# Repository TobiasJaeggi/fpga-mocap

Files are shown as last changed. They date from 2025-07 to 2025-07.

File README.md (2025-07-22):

# FPGA-based low-cost motion capture
Infrared-based motion capture.
Image processing is done the [GECKO5Modular](https://github.com/logisim-evolution/GECKO5Education) (formerly GECKO5Education V2.0), an educational FPGA platform.
I created this system as part of masters degree in electrical engineering at Bern University of Applied Sciences (BFH).

> [!NOTE]
> Solving marker correspondence using epipolar geometry is not yet implemented.
> As a result, the Python software is currently only able to track a single marker.

# Blob Detector
Marker detection unit hosting FGPA, microcontroller, IR camera, IR LEDs and PoE module.
<p float="left">
  
  
</p>

# Demo
The system tracking a reflective marker.
demo
[demo video](https://youtu.be/6Va6dF9vp88)

# Mechanical design
[onshape project](https://cad.onshape.com/documents/1d5331a2d4403797078fc34d/w/9683c0b739c4abd1173768d9/e/775ed87ad6031a9883c39a66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)

# Documentation
`doc/Low-Cost_Motion_Capture.pdf`

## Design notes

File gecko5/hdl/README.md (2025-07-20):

# Disclaimer
**This README is out of date!**
It is a leftover of the template this project is based on.
The most complete documentation can be found in the root README.md

Some testbenches are deprecated and no longer work.

[or1ktoolchain]( https://github.com/openrisc/or1k-gcc) is required to build program for softcore

---

# Old README
#### Structure:

The virtual prototype consists of three directories:

- modules: This directory contains the several modules that are contained in the SOC. Add your own modules in this directory. Most modules also contain a ```doc``` directory with documentation.
- programms: This directory contains the "hello world" template that can be used as basis for your own programms.
- systems: This directory contains all the required files for the "top level" of the SOC.

#### Hardware configuration files:

To be able to build the Virtual Prototype hardware, there are several files:

- systems/singleCore/scripts/gecko4_or1420.tcl: This file contains the pin-mapping of the top level to the FPGA-pins. For the add-on board they are already contained as remarks, for the one's of the GECKO4Education you can visit [the wiki page](https://gecko-wiki.ti.bfh.ch/gecko4education_epfl:start).
- systems/singleCore/config/project.device.intel: This file contains the definitions of the FPGA used on the GECKO4Education. Do not modify this file.
- systems/singleCore/config/project.files: This file contains a list with all Verilog files that are required to build the Virtual Prototype. If you add modules, you have also to modify this file such that the modules are found.
- systems/singleCore/config/project.intel: This file contains generic commands for the Intel Quartus Lite tool. Do not modify this file.
- systems/singleCore/config/project.qsf: This file is responsible to include the gecko4_or1420.tcl file. Do not modify this file.
- systems/singleCore/config/project.toplevel: This file contains the name of the top-level module. Normally you should not have to modify this file.

#### Building the hardware:

As the tools are quite "heavy" and to provide a automated flow, a makefile system is used. To build the system:

- Goto the directory systems/singleCore/ (e.g. ```cd systems/singleCore/```).
- Type: ```make intel_bit```
- If no errors occurred you'll find in the directory ```systems/singleCore/sandbox``` the files ```or1420SingleCore.cfg``` and ```or1420SingleCore.rbf```. These files can be used to program your FPGA with the open-source tool ```openocd``` of the oss-cad-suite by executing ```openocd -f or1420SingleCore.cfg``` on the machine to which the GECKO4Education board is connected. Alternatively you can use the intel quartus programmer, for this you require the file ```or1420SingleCore.sof```, which is also available in the directory ```systems/singleCore/sandbox```

#### Building the software:

Also the software is based on a makefile system. To build a program follow following steps (with as example the hello world program):

- Goto the directory ```programs/helloWorld```
- Execute ```make clean mem```
- If no error occurred, you will find in the directory ```programs/helloWorld/build-release/``` the files ```hello.elf```, ```hello.cmem```, and ```hello.mem```. The file that you need to upload to your board is the ```hello.cmem```-file.
- Upload the ```hello.cmem```-file with your favorite terminal program to your virtual prototype.

IMPORTANT: As the or1420 does not contain a hardware-divide unit you have to compile your programm with the compile option ```-msoft-div```!

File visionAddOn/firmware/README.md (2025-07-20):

C++ firmware for the STM32 microcontroller on the Vision Add-On

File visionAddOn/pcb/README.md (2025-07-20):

# `visionAddOn/hardware`
An addon for the [GECKO5Education](https://github.com/logisim-evolution/GECKO5Education) intended for IR based MoCap featuring
- STM32F767 with external RAM, EEPROM and external Watchdog
- Power Over Ethernet
- Connector for [KLT-E4MPF-OV9281 V4.2 NIR Camera](http://modulecamera.com)
- switchable 5V supply for external IR stroble LED
# known issues
## V1.0
### nINT/REFCLK0 does not output a clock
Pin 2 (LED2/nINIT/nPME/nINTSEL) on LAN87 needs a pulldown. Also, remove pulldown on LED1/nINT/nPME/REGOFF.
 
# Attribution
## Project Template
This project is based on the GECKO5 [addonTemplate](https://github.com/logisim-evolution/GECKO5Education/tree/main/kicad/addonTemplate)

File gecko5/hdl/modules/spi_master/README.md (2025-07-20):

# spi-master
[source](https://github.com/nandland/spi-master)

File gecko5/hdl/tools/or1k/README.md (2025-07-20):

# disclaimer
These tools are compiled for `amd64` architecture.
# about
Tools required to run custom code on the or1420 soft core.
ork1toolchain.zip contains the compiler, linker, etc.
convert_or32 is used to convert the toolchains output (.elf) to the format required by the or1420 softcore (.cmem).
# install
## ork1toolchain
1. extract ork1toolchain.zip to /opt/or1k_toolchain:
```
/opt/or1k_toolchain
├── bin
├── include
├── lib
├── libexec
├── or1k-elf
└── share
```
2. add bin folder to the system path
`export PATH="/opt/or1k_toolchain/bin:$PATH"`
(add to `~/.bashrc` or corresponding file of your shell)
## convert_or32
1. Copy convert_or32 to /opt/convert_o32/bin.
```
/opt/convert_or32/
└── bin
    └── convert_or32
```
2. add bin folder to the system path
`export PATH="/opt/convert_or32/bin:$PATH"`
(add to `~/.bashrc` or corresponding file of your shell)

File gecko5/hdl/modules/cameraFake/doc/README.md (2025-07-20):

# Description
Fake of Olimex Ov7670 camera, caplable of displaying a test image.
Outputs a RGB565 8bit parallel video signal. The resolution is 640*480 pixels.
# sources
[clock divier](https://www.fpga4student.com/2017/08/verilog-code-for-clock-divider-on-fpga.html)
[verilator tutorial](https://itsembedded.com/dhd/verilator_1/)
[implementing vga in verilog](https://ktln2.org/2018/01/23/implementing-vga-in-verilog/)

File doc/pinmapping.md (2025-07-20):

# Pin Mapping

| In Use (STM) | STM Pin | visionAddOn<br>QTE<br>Signal Name | QTE-020-01-F-D-A<br>Pin Number | GECKO5 QTE Signal Name | FPGA Pin |
| --- | --- | --- | --- | --- | --- |
| - | - | - | 1 | - | - |
| - | - | NC | 2 | - | - |
| | PD5 | UART_TX_STM_TO_FGPA | 3 | GPIO18 | A5 |
| - | - | PCLK_CAMERA | 4 | GPIO19 | E5 |
| x | PA3 | UART_RX_STM_FROM_FPGA | 5 | GPIO17 | B5 |
| - | - | HREF_CAMERA | 6 | GPIO20 | F2 |
| x | PA6 | PCLK_FPGA | 7 | GPIO16 | C5 |
| - | - | VSYNC_CAMERA | 8 | GPIO21 | E1 |
| x | PA4 | HSYNC_FPGA | 9 | GPIO15 | D5 |
| - | - | D2_CAMERA | 10 | GPIO22 | E2 |
| x | PG9 | VSYNC_FPGA | 11 | GPIO14 | A3 |
| - | - | D3_CAMERA | 12 | GPIO23 | D1 |
| x | PC9 | D3_FPGA | 13 | GPIO13 | A4 |
| - | - | D4_CAMERA | 14 | GPIO24 | D2 |
| x | PC8 | D2_FPGA | 15 | GPIO12 | B3 |
| - | - | D5_CAMERA | 16 | GPIO25 | C1 |
| x | PC7 | D1_FPGA | 17 | GPIO11 | B4 |
| - | - | D6_CAMERA | 18 | GPIO26 | C2 |
| x | PC6 | D0_FPGA | 19 | GPIO10 | C3 |
| - | - | D7_CAMERA | 20 | GPIO27 | B1 |
| x | PE4 | D4_FPGA | 21 | GPIO9 | C4 |
| - | - | D8_CAMERA | 22 | GPIO28 | B2 |
| x | PD3 | D5_FPGA | 23 | GPIO8 | D3 |
| - | - | D9_CAMERA | 24 | GPIO29 | A2 |
| x | PE5 | D6_FPGA | 25 | GPIO7 | F5 |
| - | - | STROBE | 26 | GPIO30 | H3 |
| x | PE6 | D7_FPGA | 27 | GPIO6 | E3 |
| | PB6 | SCL_CAM | 28 | GPIO31 | H4 |
| | PA5 | DEBUG0 | 29 | GPIO5 | E4 |
| | PB7 | SDA_CAM | 30 | GPIO32 | H5 |
| | PB4 | DEBUG1 | 31 | GPIO4 | F3 |
| - | - | PWR_RX | 32 | - | - |
| | PD7 | DEBUG2 | 33 | GPIO3 | F4 |
| - | - | PWR_TX | 34 | - | - |
| | PG10 | DEBUG3 (EXTI new SPI data) | 35 | GPIO2 | G3 |
| - | - | USB_FPGA_D- | 36 | Usb D- | - |
| | PG11 | DEBUG4 | 37 | GPIO1 | G5 |
| - | - | USB_FPGA_D+ | 38 | Usb D+ | - |
| - | - | - | 39 | - | - |
| - | - | GND | 40 | GND | - |

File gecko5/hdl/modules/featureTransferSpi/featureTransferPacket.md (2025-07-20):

## Types
---
`U8` type
unsigned integer 8-bit

---
`BB` type
6 bytes
index range is bit index
```
|-BB--------------------------------------|
|-47:42---|-41:31-|-30:20-|-19:10-|-9:0---|
| padding | xmin  | xmax  | ymin  | ymax  |
```
---
## packet structure
bb: bounding box
index range is byte index
```
|-header-------------------------|-features------------------|
| frame count | number of bb <n> | bb0 | bb1 | ... | bb<n-1> |
|-------------|------------------|-----|-----|-----|---------|
| U8          | U8               | BB  | BB  | ... | BB      |
```

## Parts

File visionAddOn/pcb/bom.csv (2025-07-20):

Reference | Value | Datasheet | Footprint | Qty | DNP | Description | DigiKey-Partnumber | CUBUS
R5 | 0 | ~ | Resistor_SMD:R_0402_1005Metric | 1 |  |  | 311-0.0JRTR-ND | 0 RESC1005X35
R6,R7,R10,R60,R61,R62 | 0 |  | Resistor_SMD:R_0402_1005Metric | 6 | DNP |  | 311-0.0JRTR-ND | 0 RESC1005X35
R11,R57,R58,R59 | 0 |  | Resistor_SMD:R_0402_1005Metric | 4 |  |  | 311-0.0JRTR-ND | 0 RESC1005X35
C31,C33 | 9pF | ~ | Capacitor_SMD:C_0402_1005Metric | 2 |  |  | 490-8232-2-ND
C2 | 18pF | ~ | Capacitor_SMD:C_0402_1005Metric | 1 |  |  | 490-8082-2-ND | 18P CAPC1005X50
C18,C20 | 47pF | ~ | Capacitor_SMD:C_0402_1005Metric | 2 |  |  | 490-5942-2-ND | 47P CAPC1005X50
C59 | 470pF | ~ | Capacitor_SMD:C_0402_1005Metric | 1 |  |  | 490-1300-2-ND | 470P CAPC1005X50
C71,C72 | 22nF | ~ | Capacitor_SMD:C_0603_1608Metric | 2 |  | Unpolarized capacitor | 490-17777-2-ND
C7,C12,C15 | 100nF |  | Capacitor_SMD:C_0402_1005Metric | 3 |  |  | 490-6328-2-ND | 100N CAPC1005X50
C17,C19,C22,C23,C24,C25,C26,C27,C29,C30,C32,C35,C36,C38,C39,C40,C41,C42,C45,C46,C47,C48,C49,C50,C51,C54,C55,C58,C63,C65,C66,C67,C76,C77,C79 | 100nF | ~ | Capacitor_SMD:C_0402_1005Metric | 35 |  |  | 490-6328-2-ND | 100N CAPC1005X50
C70 | 100nF | ~ | Capacitor_SMD:C_0603_1608Metric | 1 | DNP | Unpolarized capacitor | 311-1088-2-ND | 100N CAPC1608X80
C1,C3 | 1uF | ~ | Capacitor_SMD:C_0603_1608Metric | 2 |  |  | 445-4112-2-ND | 1U CAPC1608X80
C6,C8,C9,C11,C13,C14,C16 | 1uF |  | Capacitor_SMD:C_0603_1608Metric | 7 |  |  | 445-4112-2-ND | 1U CAPC1608X80
C34,C37,C52,C53,C56,C57,C62,C75 | 1uF | ~ | Capacitor_SMD:C_0402_1005Metric | 8 |  |  | 490-10024-2-ND | 1U CAPC1005X50
C60 | 1uF | ~ | Capacitor_SMD:C_0402_1005Metric | 1 | DNP |  | 490-10024-2-ND | 1U CAPC1005X50
C43,C44 | 2.2uF | ~ | Capacitor_SMD:C_0402_1005Metric | 2 |  |  | 490-10012-2-ND | 2U2 CAPC1005X50
C4,C5,C10 | 4.7uF |  | Capacitor_SMD:C_0805_2012Metric | 3 |  |  | 1292-0805X475K250CTTR-ND | 4u7 CAPC2012X95
C21 | 10uF | ~ | Capacitor_SMD:C_0603_1608Metric | 1 |  |  | 445-4112-2-ND
C64 | 10uF | ~ | Capacitor_SMD:C_0402_1005Metric | 1 |  |  | 490-GRM155R61A106ME11DTR-ND
R14,R15 | 27 | ~ | Resistor_SMD:R_0402_1005Metric | 2 |  |  | P27.0LTR-ND | 27 RESC1005X35
R31,R32,R34,R35,R36 | 33 | ~ | Resistor_SMD:R_0402_1005Metric | 5 |  |  | 311-33.0LRTR-ND
R30 | 47 | ~ | Resistor_SMD:R_0402_1005Metric | 1 |  |  | RMCF0402JT47R0TR-ND
R47,R48,R49,R50 | 50 | ~ | Resistor_SMD:R_0402_1005Metric | 4 |  |  | 13-RT0402BRE0750RLTR-ND
R16,R17,R43,R44 | 270 | ~ | Resistor_SMD:R_0402_1005Metric | 4 |  |  | 541-4842-2-ND | 270 RESC1005X35
R1,R2,R28,R29 | 1k | ~ | Resistor_SMD:R_0402_1005Metric | 4 |  |  | 311-1.0KJRTR-ND | 1K RESC1005X35
R8,R9 | 1k | ~ | Resistor_SMD:R_0402_1005Metric | 2 |  | Resistor | 311-1.0KJRTR-ND | 1K RESC1005X35
R18,R19,R20,R21,R22,R26,R27,R33,R37,R38,R39,R41,R42,R52,R53,R54,R55 | 10k | ~ | Resistor_SMD:R_0402_1005Metric | 17 |  |  | 311-10KJRTR-ND | 10K RESC1005X35
R23 | 12k | ~ | Resistor_SMD:R_0402_1005Metric | 1 |  |  | 311-12KJRTR-ND | 12K RESC1005X35
R46 | 12.1k | ~ | Resistor_SMD:R_0402_1005Metric | 1 |  |  | 311-12.1KLRTR-ND
R24,R25 | 100k | ~ | Resistor_SMD:R_0402_1005Metric | 2 |  |  | 311-100KLRTR-ND | 100K RESC1005X35
R4 | 150k | ~ | Resistor_SMD:R_0402_1005Metric | 1 |  |  | 311-150KLRTR-ND | 150K RESC1005X35
R3 | 680k | ~ | Resistor_SMD:R_0402_1005Metric | 1 |  |  | 311-680KJRTR-ND | 680K RESC1005X35
R45 | 1M | ~ | Resistor_SMD:R_0402_1005Metric | 1 | DNP |  | 311-1.00MLRTR-ND | 1M RESC1005X35
StrobeEnable1 | 61300211121 | ~ | Connector_PinHeader_2.54mm:PinHeader_1x02_P2.54mm_Vertical | 1 |  | Generic connector, single row, 01x02, script generated (kicad-library-utils/schlib/autogen/connector/) | 732-5315-ND
WATCHDOG_ENABLE1 | 61300211121 | https://www.we-online.com/components/products/datasheet/61300211121.pdf | Connector_PinHeader_2.54mm:PinHeader_1x02_P2.54mm_Vertical | 1 |  | Generic connector, single row, 01x02, script generated (kicad-library-utils/schlib/autogen/connector/) | 732-5315-ND
J3 | 61300311121 | ~ | Connector_PinHeader_2.54mm:PinHeader_1x03_P2.54mm_Vertical | 1 |  | Generic connector, single row, 01x03, script generated (kicad-library-utils/schlib/autogen/connector/) | 732-5316-ND
J1,J7 | 61300411121 | ~ | Connector_PinHeader_2.54mm:PinHeader_1x04_P2.54mm_Vertical | 2 |  | Generic connector, single row, 01x04, script generated (kicad-library-utils/schlib/autogen/connector/) | 732-5317-ND
J5 | 61300511121 | ~ | Connector_PinHeader_2.54mm:PinHeader_1x05_P2.54mm_Vertical | 1 |  | Generic connector, single row, 01x05, script generated (kicad-library-utils/schlib/autogen/connector/) | 732-5318-ND
J4 | 105450-0101 | https://tools.molex.com/pdm_docs/ps/PS-105448-001.pdf | visionAddOn:MOLEX_105450-0101 | 1 |  | USB Shielded I/O Receptacle; Type C; Right Angle; Surface Mount; Gold over Nickel | WM12856TR-ND
D2,D4 | 150060GS75020 | https://www.we-online.com/components/products/datasheet/150060GS75020.pdf | LED_SMD:LED_0603_1608Metric | 2 |  | Light emitting diode | 732-150060GS75020TR-ND
D1,D3 | 150060RS75020 | https://www.we-online.com/components/products/datasheet/150060RS75020.pdf | LED_SMD:LED_0603_1608Metric | 2 |  | Light emitting diode | 732-150060RS75020TR-ND
R51 | 15k/0.1W | ~ | Resistor_SMD:R_0402_1005Metric | 1 |  | Resistor | P15.0KLTR-ND
R40 | 1k5 | ~ | Resistor_SMD:R_0402_1005Metric | 1 |  |  | 311-1.5KJRTR-ND
L5 | 1k @ 100MHz/LRC0402CS2N2GV001T | ~ | Inductor_SMD:L_0402_1005Metric | 1 |  |  | 712-LRC0402CS2N2GV001TTR-ND
C61 | 1nF/2000V/10%/X7R/C1206 | ~ | Capacitor_SMD:C_1206_3216Metric | 1 |  | Unpolarized capacitor | 709-VPDD202W102K1GV001ETR-ND
C69 | 22uF/80V/20%/PCH1J220MCL4GS | https://www.nichicon.co.jp/english/series_items/catalog_pdf/e-pch.pdf | Capacitor_SMD:CP_Elec_6.3x7.7 | 1 |  | Polarized capacitor | PCH1J220MCL4GTR-ND
C68,C73,C74 | 470uF/10V/20%/PCF1A471MCL1GS | https://www.nichicon.co.jp/english/series_items/catalog_pdf/e-pcf.pdf | Capacitor_SMD:CP_Elec_10x10 | 3 |  | Polarized capacitor | 493-2996-2-ND
R12,R13 | 5k1 | ~ | Resistor_SMD:R_0402_1005Metric | 2 |  |  | 311-5.10KLRTR-ND
U2 | AP2281-3WG-7 | ~ | visionAddOn:SOT26_DIO | 1 |  |  | AP2281-3WG-7DITR-ND
U13 | AS4C16M16SA | https://www.alliancememory.com/wp-content/uploads/pdf/dram/256M-AS4C16M16SA-Automotive_v2.0_March%202015.pdf | Package_SO:TSOP-II-54_22.2x10.16mm_P0.8mm | 1 |  | 64M – (16M x 16 bit) Synchronous DRAM (SDRAM), TSOP-II-54 | 1450-1252-ND
U18 | AT24C02D-MAHM-T | https://ww1.microchip.com/downloads/aemDocuments/documents/OTH/ProductDocuments/DataSheets/AT24C01D-AT24C02D-I2C-Compatible-Two-Wire-Serial-EEPROM-1Kbit-2Kbit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 | visionAddOn:AT24C02D-MAHM-T_SON50P200X300X60-9N | 1 |  |  | AT24C02D-MAHM-TTR-ND
BOOT_STM1 | B3U-1000P | ~ | visionAddOn:SW_B3U-1000P_OMR | 1 |  | https://omronfs.omron.com/en_US/ecb/products/pdf/en-b3u.pdf | SW1020TR-ND
BT1 | B3U-1000P | https://omronfs.omron.com/en_US/ecb/products/pdf/en-b3u.pdf | visionAddOn:SW_B3U-1000P_OMR | 1 |  |  | SW1020TR-ND
RESET1 | B3U-1000P | https://omronfs.omron.com/en_US/ecb/products/pdf/en-b3u.pdf | visionAddOn:SW_B3U-1000P_OMR | 1 |  |  | SW1020TR-ND
L6 | BLM18KG601SN1D | ~ | Inductor_SMD:L_0603_1608Metric | 1 |  | Inductor | 490-5258-2-ND
C28 | C1608X5R0J106M080AB | ~ | Capacitor_SMD:C_0603_1608Metric | 1 |  |  | 445-4112-2-ND
xt30SourceSelect1 | D3086-98 | ~ | visionAddOn:HARWIN_D3086-98 | 1 |  | Generic connector, single row, 01x03, script generated (kicad-library-utils/schlib/autogen/connector/) | 952-1864-ND
U8 | DF30FC-24DS-0.4V_82_ | https://www.hirose.com/product/document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 | visionAddOn:DF30FC-24DS_KLT_PIN_MAPPING | 1 |  |  | H3860TR-ND
X1 | ECS-2520MV-240-BL-TR | https://www.ecsxtal.com/store/pdf/ECS-2520MV.pdf | Oscillator:Oscillator_SMD_ECS_2520MV-xxx-xx-4Pin_2.5x2.0mm | 1 |  | HCMOS Crystal Clock Oscillator, 2.5x2.0 mm SMD | 50-ECS-2520MV-240-BL-TR-ND
X2,X3 | ECS-2520MV-240-BL-TR | https://www.ecsxtal.com/store/pdf/ECS-2520MV.pdf | Oscillator:Oscillator_SMD_ECS_2520MV-xxx-xx-4Pin_2.5x2.0mm | 2 |  |  | 50-ECS-2520MV-240-BL-TR-ND
X4 | ECS-2520MV-250-CN-TR | https://www.ecsxtal.com/store/pdf/ECS-2520MV.pdf | Oscillator:Oscillator_SMD_ECS_2520MV-xxx-xx-4Pin_2.5x2.0mm | 1 |  | HCMOS Crystal Clock Oscillator, 2.5x2.0 mm SMD | XC2752TR-ND
U10 | FT231XQ | https://www.ftdichip.com/Support/Documents/DataSheets/ICs/DS_FT231X.pdf | Package_DFN_QFN:QFN-20-1EP_4x4mm_P0.5mm_EP2.5x2.5mm | 1 |  |  | 768-1128-2-ND
J6 | FTSH-105-01-S-DV-K-P-TR | http://infocenter.arm.com/help/topic/com.arm.doc.ddi0314h/DDI0314H_coresight_components_trm.pdf | visionAddOn:SAMTEC_FTSH-105-01-S-DV-TR | 1 |  | Cortex Debug Connector, standard ARM Cortex-M SWD and JTAG interface | SAM13935TR-ND
Q1 | IRLZ44N | http://www.irf.com/product-info/datasheets/data/irlz44n.pdf | Package_TO_SOT_THT:TO-220-3_Vertical | 1 |  | 47A Id, 55V Vds, 22mOhm Rds Single N-Channel HEXFET Power MOSFET, TO-220AB | IRLZ44NPBF-ND
U14 | LAN8742A | http://ww1.microchip.com/downloads/en/DeviceDoc/8742a.pdf | Package_DFN_QFN:VQFN-24-1EP_4x4mm_P0.5mm_EP2.5x2.5mm_ThermalVias | 1 |  | LAN8720 Ethernet PHY with RMII interface, QFN-24 | LAN8742A-CZ-TR-ND
L1 | LQM2HPN2R2MJ0L | ~ | visionAddOn:LQM2HPN2R2MJ0L | 1 |  |  | 490-6700-2-ND
U3 | MIC826TYMT-TR | https://ww1.microchip.com/downloads/en/DeviceDoc/MIC826.pdf | visionAddOn:MIC826TYMT-TR_SON50P160X160X60-7N | 1 |  |  | 576-4375-2-ND
L2,L3,L4 | MLP2012S3R3MT | https://product.tdk.com/en/system/files | Inductor_SMD:L_0805_2012Metric | 3 |  |  | 445-6365-2-ND
MD1 | MYBSP0055AABFT | https://www.murata.com/products/productdata/8807034454046/MYBSP0055AABFT.pdf | visionAddOn:MYBSP0055AABFT_0 | 1 |  |  | 811-MYBSP0055AABFTTR-ND
U1 | NCP1529A | https://www.onsemi.com/pub/Collateral/NCP1529-D.PDF | Package_TO_SOT_SMD:SOT-23-5 | 1 |  |  | NCP1529ASNT1GOSTR-ND
U7 | NTS0104BQ | https://www.nxp.com/docs/en/data-sheet/NTS0104_Q100.pdf | Package_DFN_QFN:DHVQFN-14-1EP_2.5x3mm_P0.5mm_EP1x1.5mm | 1 |  |  | 568-12382-2-ND
J2 | QTE-020-01-F-D-A |  | visionAddOn:SAMTEC_QTE-020-01-X-D-A | 1 |  |  | 612-QTE-020-01-F-D-A-TR-ND
J8 | RJ45_Abracon_ARJP11A-MASA-B-A-EMU2 | https://abracon.com/Magnetics/lan/ARJP11A.PDF | Connector_RJ:RJ45_Abracon_ARJP11A-MA_Horizontal | 1 |  | RJ45 PoE 10/100 Base-TX Jack with Magnetic Module | ARJP11A-MASA-B-A-EMU2-ND
Y1 | RT2012-32.768-9-20-EXT-TR | https://www.raltron.com/webproducts/specs/CRYSTAL/CKP/RT2012-32.768-9-20-EXT-TR.pdf | Crystal:Crystal_SMD_2012-2Pin_2.0x1.2mm | 1 |  |  | 2151-RT2012-32.768-9-20-EXT-TR-ND
U11 | SN74LVC2G07DBVR | https://www.ti.com/lit/ds/symlink/sn74lvc2g07.pdf | visionAddOn:SOT95P280X145-6N | 1 |  |  | 296-13494-2-ND
U12 | STM32F767ZITx | https://www.st.com/resource/en/datasheet/stm32f767zi.pdf | Package_QFP:LQFP-144_20x20mm_P0.5mm | 1 |  | STMicroelectronics Arm Cortex-M7 MCU, 2048KB flash, 512KB RAM, 216 MHz, 1.7-3.6V, 114 GPIO, LQFP144 | 497-16521-ND
U16 | TLP293 | https://toshiba.semicon-storage.com/info/TLP293_datasheet_en_20191129.pdf?did=14419&prodName=TLP293 | Package_SO:SOIC-4_4.55x2.6mm_P1.27mm | 1 |  | DC Optocoupler, Vce 80V, CTR 50-100%, SOP4 | TLP293(GB-TPLETR-ND
U5 | TLV73312PDBV | http://www.ti.com/lit/ds/symlink/tlv733p.pdf | Package_TO_SOT_SMD:SOT-23-5 | 1 |  | 300mA Capacitor-Free Low Dropout Voltage Regulator, Fixed Output 1.2V, SOT-23-5 | 296-40665-2-ND
U4 | TLV73318PDBV | http://www.ti.com/lit/ds/symlink/tlv733p.pdf | Package_TO_SOT_SMD:SOT-23-5 | 1 |  | 300mA Capacitor-Free Low Dropout Voltage Regulator, Fixed Output 1.8V, SOT-23-5 | 296-40669-2-ND
U6 | TLV73328PDBV | http://www.ti.com/lit/ds/symlink/tlv733p.pdf | Package_TO_SOT_SMD:SOT-23-5 | 1 |  | 300mA Capacitor-Free Low Dropout Voltage Regulator, Fixed Output 2.8V, SOT-23-5 | 296-42282-2-ND
U9 | USB2513B-AEZC | https://ww1.microchip.com/downloads/en/DeviceDoc/00001692C.pdf | visionAddOn:QFN36_6X6MC_MCH | 1 |  |  | USB2513B-AEZC-ND
U15 | USBLC6-4SC6 | https://www.st.com/resource/en/datasheet/usblc6-4.pdf | Package_TO_SOT_SMD:SOT-23-6 | 1 |  | Very low capacitance ESD protection diode, 4 data-line, SOT-23-6 | 497-4492-2-ND
U17 | XT30UPB-F/XT30-Female |  | Connector_AMASS:AMASS_XT30UPB-F_1x02_P5.0mm_Vertical | 1 |  |  | 1738-1436-ND

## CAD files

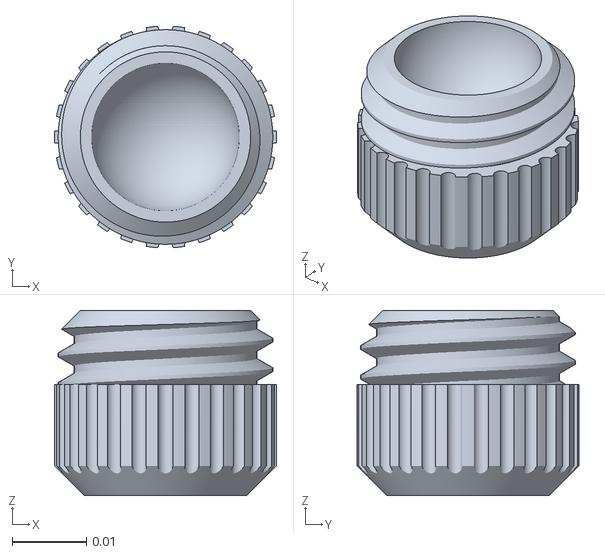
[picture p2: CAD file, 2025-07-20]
mechanical/Ball Joint Socket Extension.stl
0.03 x 0.0299 x 0.025

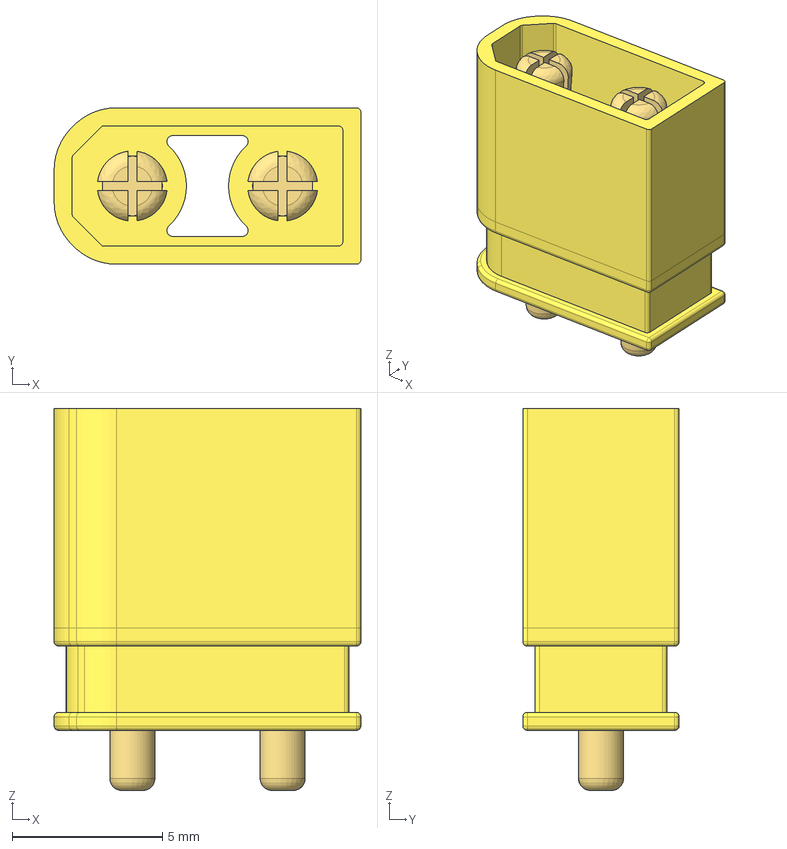
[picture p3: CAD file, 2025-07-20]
visionAddOn/pcb/3DModels/Amass_XT30UPB-M.step
10.2 x 5.20 x 12.7 mm

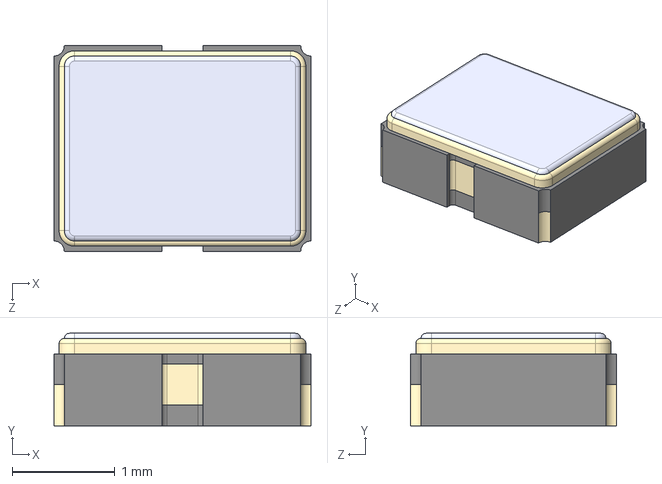
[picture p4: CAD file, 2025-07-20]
visionAddOn/pcb/3DModels/ECS-2520MV-250-CN-TR.STEP
2.50 x 0.9 x 2.00 mm

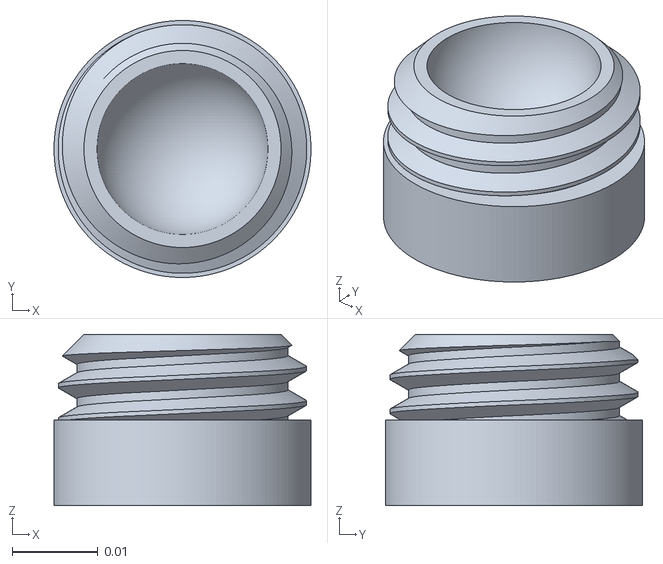
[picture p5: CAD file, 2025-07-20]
mechanical/Ball Joint Socket.stl
0.03 x 0.03 x 0.02

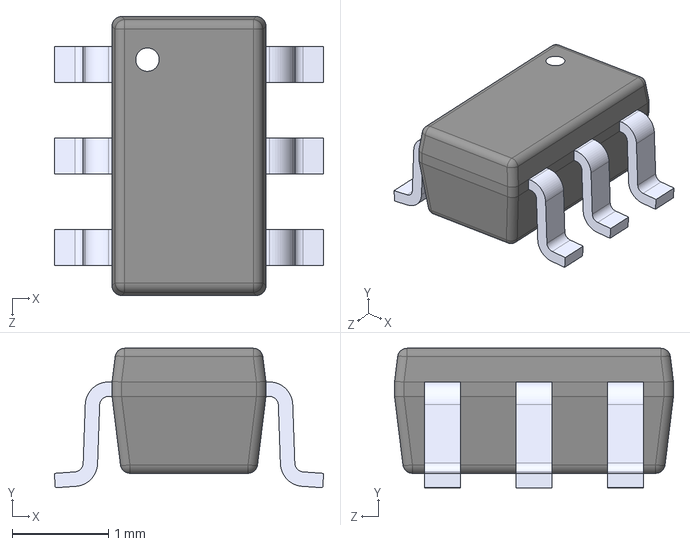
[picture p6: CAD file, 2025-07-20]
visionAddOn/pcb/3DModels/SN74LVC2G07DBVR.STEP
2.80 x 1.45 x 2.90 mm

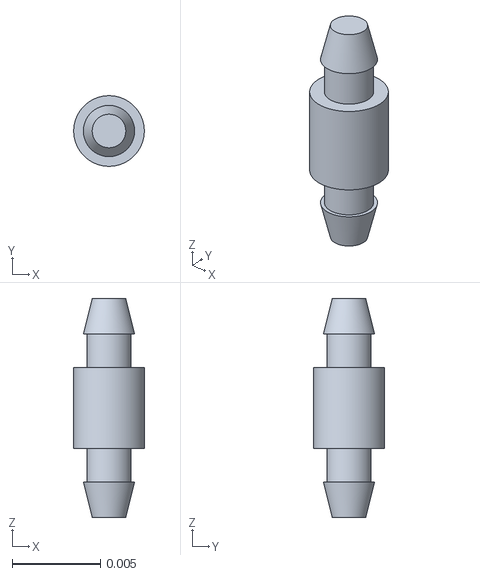
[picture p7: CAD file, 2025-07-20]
mechanical/Pin TPU.stl
0.004 x 0.004 x 0.0124

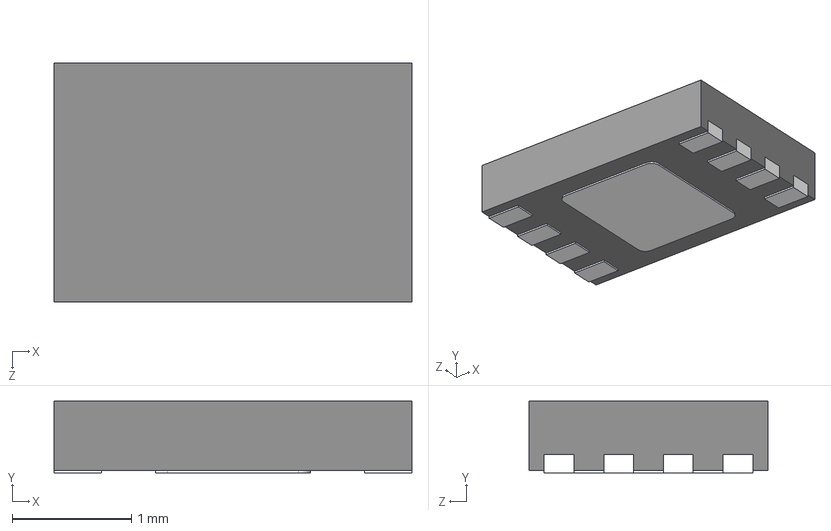
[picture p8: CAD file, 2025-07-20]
visionAddOn/pcb/3DModels/AT24C02D-MAHM-T.step
3.00 x 0.6 x 2.00 mm

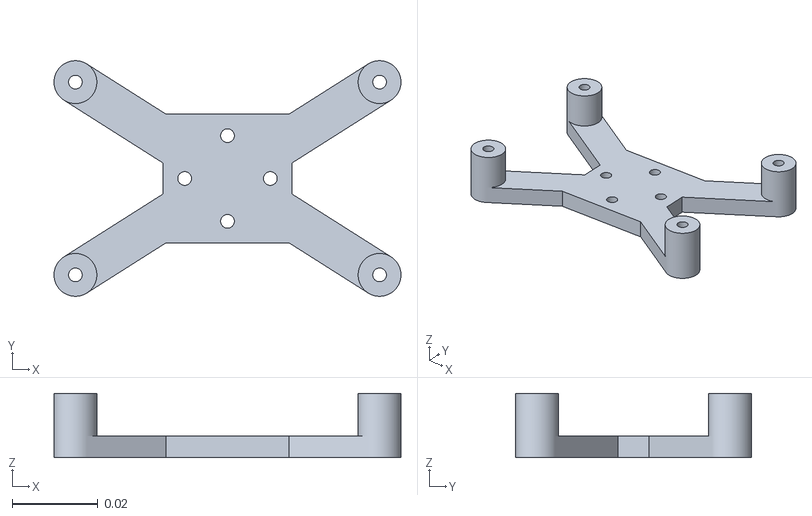
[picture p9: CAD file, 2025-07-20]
mechanical/x bar mount.stl
0.081 x 0.055 x 0.015

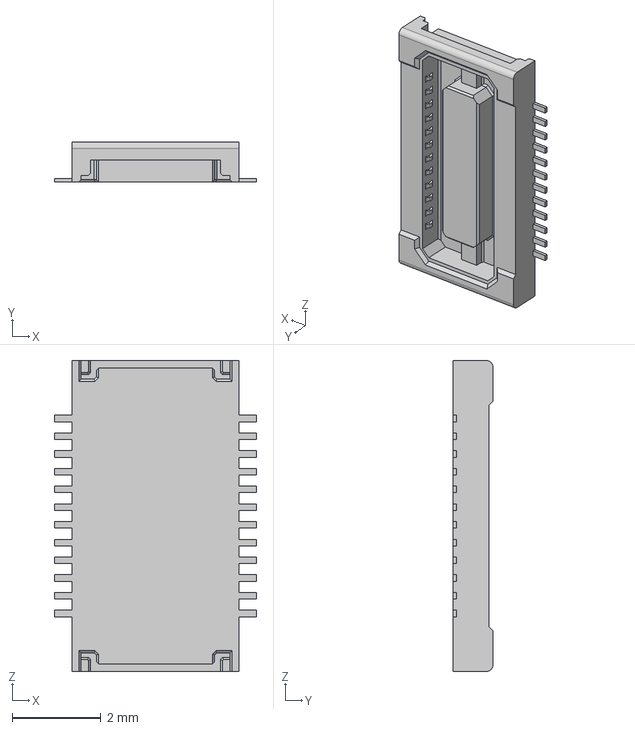
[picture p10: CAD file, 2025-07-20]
visionAddOn/pcb/3DModels/DF30FC-24DS-0.4V.stp
4.56 x 0.9 x 7.02 mm

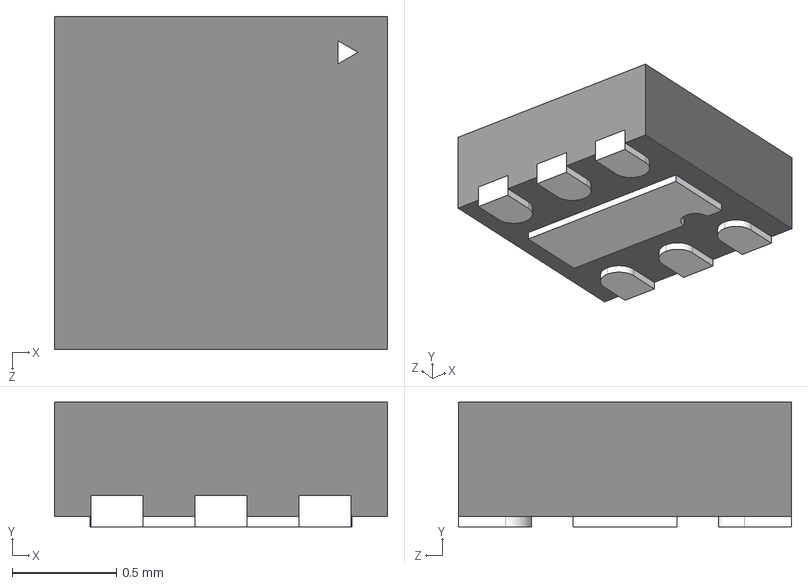
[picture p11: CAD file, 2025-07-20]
visionAddOn/pcb/3DModels/MIC826TYMT-TR.step
1.60 x 0.6 x 1.60 mm

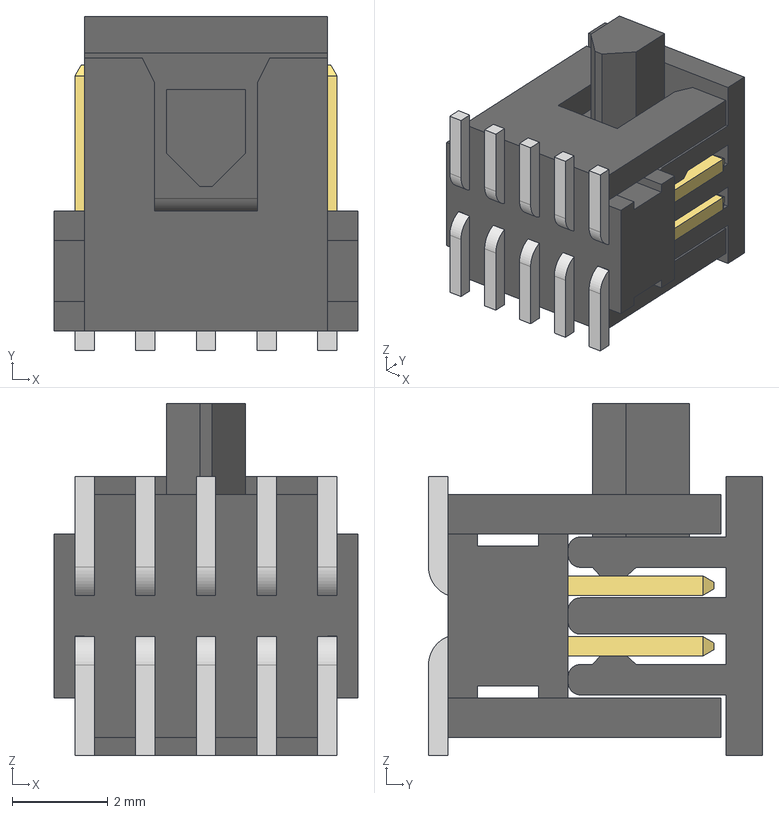
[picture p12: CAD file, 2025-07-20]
visionAddOn/pcb/3DModels/FTSH-105-01-S-DV-K-P-TR.stp
6.35 x 6.98 x 7.37 mm
FTSH-105-01-S-DV-K-P-TR_body
FTSH-105-01-S-DV-K-P-TR_pins1
FTSH-105-01-S-DV-K-P-TR_pins2
FTSH-105-01-S-DV-K-P-TR_pp_pad

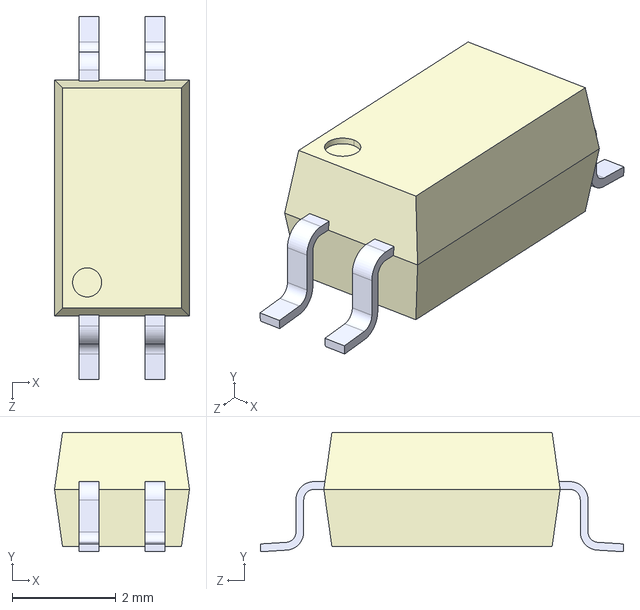
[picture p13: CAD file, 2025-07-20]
visionAddOn/pcb/3DModels/TLP293.STEP
2.60 x 2.30 x 7.00 mm

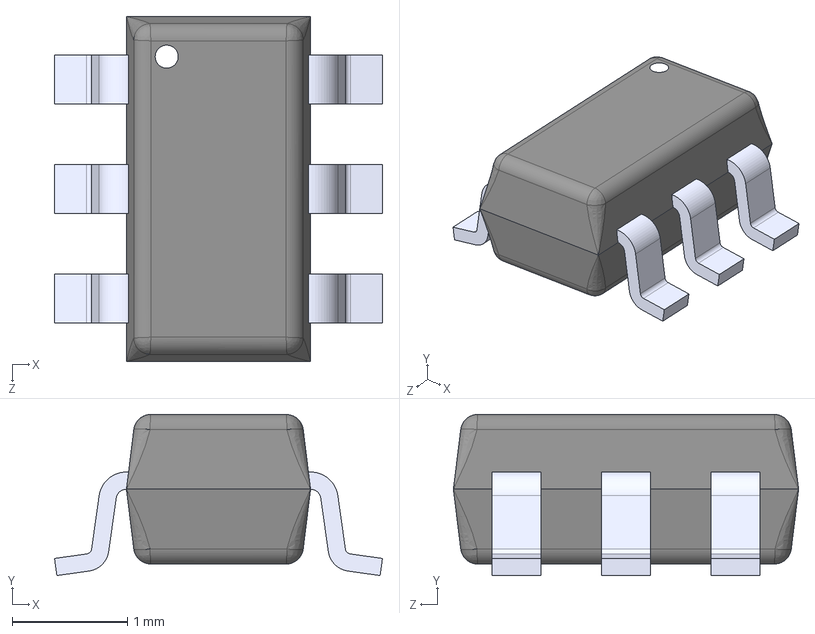
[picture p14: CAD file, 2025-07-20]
visionAddOn/pcb/3DModels/AP2281-3WG-7.STEP
2.85 x 1.40 x 3.00 mm

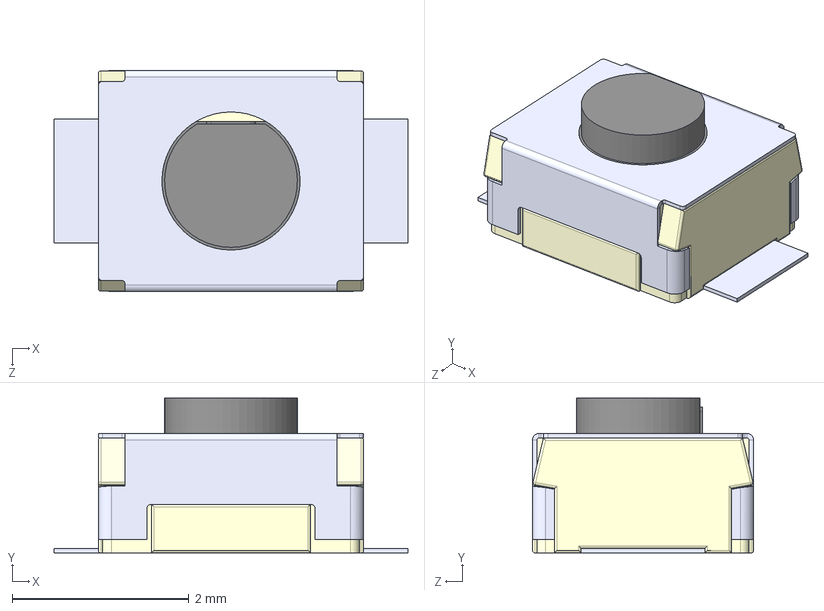
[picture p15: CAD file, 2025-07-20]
visionAddOn/pcb/3DModels/B3U-1000P--3DModel-STEP-56544.STEP
4.00 x 1.75 x 2.50 mm

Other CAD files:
visionAddOn/pcb/3DModels/RT2012-32.768-9-20-EXT-TR.stp
visionAddOn/pcb/3DModels/Amass_XT30UPB-F.step
visionAddOn/pcb/3DModels/USB2513B-AEZC-TR.STEP
visionAddOn/pcb/3DModels/ARJP11A-MASA-B-A-EMU2--3DModel-STEP-1.STEP
host/deprecated/testscene/scene.blend
mechanical/Ball Joint Nut.stl
visionAddOn/pcb/3DModels/105450-0101--3DModel-STEP-56544.STEP
visionAddOn/pcb/3DModels/LAN8742A-CZ-TR--3DModel-STEP-510211.STEP
visionAddOn/pcb/3DModels/LQM2HPN2R2MJ0L.STEP
visionAddOn/pcb/3DModels/MYBSP0055AABFT--3DModel-STEP-387902.STEP
visionAddOn/pcb/3DModels/NTS0104BQ_115.step
visionAddOn/pcb/3DModels/QTE-020-01-X-D-A.step

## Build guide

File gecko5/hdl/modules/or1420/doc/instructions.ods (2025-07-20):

31 | 30 | 29 | 28 | 27 | 26 | 25 | 24 | 23 | 22 | 21 | 20 | 19 | 18 | 17 | 16 | 15 | 14 | 13 | 12 | 11 | 10 | 9 | 8 | 7 | 6 | 5 | 4 | 3 | 2 | 1 | 0 | ADDER:
1 | 1 | 1 | 0 | 0 | 0 | D |  |  |  |  | A |  |  |  |  | B |  |  |  |  | 0 | 0 | 0 | ? | ? | ? | ? | 0 | 0 | 0 | 0 | Add signed
1 | 1 | 1 | 0 | 0 | 0 | D |  |  |  |  | A |  |  |  |  | B |  |  |  |  | 0 | 0 | 0 | ? | ? | ? | ? | 0 | 0 | 0 | 1 | Add signed with carry
1 | 1 | 1 | 0 | 0 | 0 | D |  |  |  |  | A |  |  |  |  | B |  |  |  |  | 0 | 0 | 0 | ? | ? | ? | ? | 0 | 0 | 1 | 0 | Sub Signed
1 | 0 | 0 | 1 | 1 | 1 | D |  |  |  |  | A |  |  |  |  | I |  |  |  |  |  |  |  |  |  |  |  |  |  |  |  | Add Immediate signed
1 | 0 | 1 | 0 | 0 | 0 | D |  |  |  |  | A |  |  |  |  | I |  |  |  |  |  |  |  |  |  |  |  |  |  |  |  | Add Immediate signed with carry
31 | 30 | 29 | 28 | 27 | 26 | 25 | 24 | 23 | 22 | 21 | 20 | 19 | 18 | 17 | 16 | 15 | 14 | 13 | 12 | 11 | 10 | 9 | 8 | 7 | 6 | 5 | 4 | 3 | 2 | 1 | 0 | LOGIC UNIT:
1 | 1 | 1 | 0 | 0 | 0 | D |  |  |  |  | A |  |  |  |  | B |  |  |  |  | 0 | 0 | 0 | ? | ? | ? | ? | 0 | 0 | 1 | 1 | And
1 | 1 | 1 | 0 | 0 | 0 | D |  |  |  |  | A |  |  |  |  | B |  |  |  |  | 0 | 0 | 0 | ? | ? | ? | ? | 0 | 1 | 0 | 0 | Or
1 | 1 | 1 | 0 | 0 | 0 | D |  |  |  |  | A |  |  |  |  | B |  |  |  |  | 0 | 0 | 0 | ? | ? | ? | ? | 0 | 1 | 0 | 1 | Xor
1 | 0 | 1 | 0 | 0 | 1 | D |  |  |  |  | A |  |  |  |  | I |  |  |  |  |  |  |  |  |  |  |  |  |  |  |  | And immediate
1 | 0 | 1 | 0 | 1 | 0 | D |  |  |  |  | A |  |  |  |  | I |  |  |  |  |  |  |  |  |  |  |  |  |  |  |  | Or immediate
1 | 0 | 1 | 0 | 1 | 1 | D |  |  |  |  | A |  |  |  |  | I |  |  |  |  |  |  |  |  |  |  |  |  |  |  |  | Xor immediate
1 | 1 | 1 | 0 | 0 | 0 | D |  |  |  |  | A |  |  |  |  | ? | ? | ? | ? | ? | ? | 0 | 0 | 0 | 1 | ? | ? | 1 | 1 | 0 | 0 | Extend byte with sign
1 | 1 | 1 | 0 | 0 | 0 | D |  |  |  |  | A |  |  |  |  | ? | ? | ? | ? | ? | ? | 0 | 0 | 1 | 1 | ? | ? | 1 | 1 | 0 | 0 | Extend byte with zero
1 | 1 | 1 | 0 | 0 | 0 | D |  |  |  |  | A |  |  |  |  | ? | ? | ? | ? | ? | ? | 0 | 0 | 0 | 0 | ? | ? | 1 | 1 | 0 | 0 | Extend half word with sign
1 | 1 | 1 | 0 | 0 | 0 | D |  |  |  |  | A |  |  |  |  | ? | ? | ? | ? | ? | ? | 0 | 0 | 1 | 0 | ? | ? | 1 | 1 | 0 | 0 | Extend half word with zero
1 | 1 | 1 | 0 | 0 | 0 | D |  |  |  |  | A |  |  |  |  | ? | ? | ? | ? | ? | ? | 0 | 0 | 0 | 0 | ? | ? | 1 | 1 | 0 | 1 | Extend word with sign
1 | 1 | 1 | 0 | 0 | 0 | D |  |  |  |  | A |  |  |  |  | ? | ? | ? | ? | ? | ? | 0 | 0 | 0 | 1 | ? | ? | 1 | 1 | 0 | 1 | Extend word with zero
31 | 30 | 29 | 28 | 27 | 26 | 25 | 24 | 23 | 22 | 21 | 20 | 19 | 18 | 17 | 16 | 15 | 14 | 13 | 12 | 11 | 10 | 9 | 8 | 7 | 6 | 5 | 4 | 3 | 2 | 1 | 0 | SHIFTER:
1 | 1 | 1 | 0 | 0 | 0 | D |  |  |  |  | A |  |  |  |  | B |  |  |  |  | 0 | 0 | 0 | 1 | 1 | ? | ? | 1 | 0 | 0 | 0 | ROR
1 | 1 | 1 | 0 | 0 | 0 | D |  |  |  |  | A |  |  |  |  | B |  |  |  |  | 0 | 0 | 0 | 0 | 0 | ? | ? | 1 | 0 | 0 | 0 | SLL
1 | 1 | 1 | 0 | 0 | 0 | D |  |  |  |  | A |  |  |  |  | B |  |  |  |  | 0 | 0 | 0 | 1 | 0 | ? | ? | 1 | 0 | 0 | 0 | SRA
1 | 1 | 1 | 0 | 0 | 0 | D |  |  |  |  | A |  |  |  |  | B |  |  |  |  | 0 | 0 | 0 | 0 | 1 | ? | ? | 1 | 0 | 0 | 0 | SRL
1 | 0 | 1 | 1 | 1 | 0 | D |  |  |  |  | A |  |  |  |  | ? | ? | ? | ? | ? | 0 | ? | ? | 1 | 1 | I |  |  |  |  |  | ROR with immediate
1 | 0 | 1 | 1 | 1 | 0 | D |  |  |  |  | A |  |  |  |  | ? | ? | ? | ? | ? | 0 | ? | ? | 0 | 0 | I |  |  |  |  |  | SLL with immediate
1 | 0 | 1 | 1 | 1 | 0 | D |  |  |  |  | A |  |  |  |  | ? | ? | ? | ? | ? | 0 | ? | ? | 1 | 0 | I |  |  |  |  |  | SRA with immediate
1 | 0 | 1 | 1 | 1 | 0 | D |  |  |  |  | A |  |  |  |  | ? | ? | ? | ? | ? | 0 | ? | ? | 0 | 1 | I |  |  |  |  |  | SRL with immediate
0 | 0 | 0 | 1 | 1 | 0 | D |  |  |  |  | 0 | 0 | 0 | 0 | 0 | I |  |  |  |  |  |  |  |  |  |  |  |  |  |  |  | Move immediate high
1 | 1 | 1 | 0 | 0 | 0 | D |  |  |  |  | A |  |  |  |  | B |  |  |  |  | ? | 0 | 0 | ? | ? | ? | ? | 1 | 1 | 1 | 0 | Conditional move
31 | 30 | 29 | 28 | 27 | 26 | 25 | 24 | 23 | 22 | 21 | 20 | 19 | 18 | 17 | 16 | 15 | 14 | 13 | 12 | 11 | 10 | 9 | 8 | 7 | 6 | 5 | 4 | 3 | 2 | 1 | 0 | BIT FINDER:
1 | 1 | 1 | 0 | 0 | 0 | D |  |  |  |  | A |  |  |  |  | B |  |  |  |  | ? | 0 | 0 | ? | ? | ? | ? | 1 | 1 | 1 | 1 | Find first one
1 | 1 | 1 | 0 | 0 | 0 | D |  |  |  |  | A |  |  |  |  | B |  |  |  |  | ? | 0 | 1 | ? | ? | ? | ? | 1 | 1 | 1 | 1 | Find last one
31 | 30 | 29 | 28 | 27 | 26 | 25 | 24 | 23 | 22 | 21 | 20 | 19 | 18 | 17 | 16 | 15 | 14 | 13 | 12 | 11 | 10 | 9 | 8 | 7 | 6 | 5 | 4 | 3 | 2 | 1 | 0 | FLAG UNIT, ADDER and COMPARITOR:
1 | 1 | 1 | 0 | 0 | 1 | 0 | 0 | 0 | 0 | 0 | A |  |  |  |  | B |  |  |  |  | ? | ? | ? | ? | ? | ? | ? | ? | ? | ? | ? | Set Flag if equal
1 | 1 | 1 | 0 | 0 | 1 | 0 | 0 | 0 | 0 | 1 | A |  |  |  |  | B |  |  |  |  | ? | ? | ? | ? | ? | ? | ? | ? | ? | ? | ? | Set flag if not equal
1 | 1 | 1 | 0 | 0 | 1 | 0 | 0 | 0 | 1 | 0 | A |  |  |  |  | B |  |  |  |  | ? | ? | ? | ? | ? | ? | ? | ? | ? | ? | ? | Set flag if greater unsigned
1 | 1 | 1 | 0 | 0 | 1 | 0 | 1 | 0 | 1 | 0 | A |  |  |  |  | B |  |  |  |  | ? | ? | ? | ? | ? | ? | ? | ? | ? | ? | ? | Set Flag if greater signed
1 | 1 | 1 | 0 | 0 | 1 | 0 | 0 | 0 | 1 | 1 | A |  |  |  |  | B |  |  |  |  | ? | ? | ? | ? | ? | ? | ? | ? | ? | ? | ? | Set Flag if greater or equal unsigned
1 | 1 | 1 | 0 | 0 | 1 | 0 | 1 | 0 | 1 | 1 | A |  |  |  |  | B |  |  |  |  | ? | ? | ? | ? | ? | ? | ? | ? | ? | ? | ? | Set Flag if greater or equal signed
1 | 1 | 1 | 0 | 0 | 1 | 0 | 0 | 1 | 0 | 0 | A |  |  |  |  | B |  |  |  |  | ? | ? | ? | ? | ? | ? | ? | ? | ? | ? | ? | Set flag if less unsigned
1 | 1 | 1 | 0 | 0 | 1 | 0 | 1 | 1 | 0 | 0 | A |  |  |  |  | B |  |  |  |  | ? | ? | ? | ? | ? | ? | ? | ? | ? | ? | ? | Set flag if less signed
1 | 1 | 1 | 0 | 0 | 1 | 0 | 0 | 1 | 0 | 1 | A |  |  |  |  | B |  |  |  |  | ? | ? | ? | ? | ? | ? | ? | ? | ? | ? | ? | Set flag if less or equal unsigned
1 | 1 | 1 | 0 | 0 | 1 | 0 | 1 | 1 | 0 | 1 | A |  |  |  |  | B |  |  |  |  | ? | ? | ? | ? | ? | ? | ? | ? | ? | ? | ? | Set flag if less or equal signed
1 | 0 | 1 | 1 | 1 | 1 | 0 | 0 | 0 | 0 | 0 | A |  |  |  |  | I |  |  |  |  |  |  |  |  |  |  |  |  |  |  |  | Set Flag if equal immediate
1 | 0 | 1 | 1 | 1 | 1 | 0 | 0 | 0 | 0 | 1 | A |  |  |  |  | I |  |  |  |  |  |  |  |  |  |  |  |  |  |  |  | Set flag if not equal immediate
1 | 0 | 1 | 1 | 1 | 1 | 0 | 0 | 0 | 1 | 0 | A |  |  |  |  | I |  |  |  |  |  |  |  |  |  |  |  |  |  |  |  | Set flag if greater immediate unsigned
1 | 0 | 1 | 1 | 1 | 1 | 0 | 1 | 0 | 1 | 0 | A |  |  |  |  | I |  |  |  |  |  |  |  |  |  |  |  |  |  |  |  | Set Flag if greater immediate signed
1 | 0 | 1 | 1 | 1 | 1 | 0 | 0 | 0 | 1 | 1 | A |  |  |  |  | I |  |  |  |  |  |  |  |  |  |  |  |  |  |  |  | Set Flag if greater or equal immediate unsigned
1 | 0 | 1 | 1 | 1 | 1 | 0 | 1 | 0 | 1 | 1 | A |  |  |  |  | I |  |  |  |  |  |  |  |  |  |  |  |  |  |  |  | Set Flag if greater or equal immediate signed
1 | 0 | 1 | 1 | 1 | 1 | 0 | 0 | 1 | 0 | 0 | A |  |  |  |  | I |  |  |  |  |  |  |  |  |  |  |  |  |  |  |  | Set flag if less immediate unsigned
1 | 0 | 1 | 1 | 1 | 1 | 0 | 1 | 1 | 0 | 0 | A |  |  |  |  | I |  |  |  |  |  |  |  |  |  |  |  |  |  |  |  | Set flag if less immediate signed
1 | 0 | 1 | 1 | 1 | 1 | 0 | 0 | 1 | 0 | 1 | A |  |  |  |  | I |  |  |  |  |  |  |  |  |  |  |  |  |  |  |  | Set flag if less or equal immediate unsigned
1 | 0 | 1 | 1 | 1 | 1 | 0 | 1 | 1 | 0 | 1 | A |  |  |  |  | I |  |  |  |  |  |  |  |  |  |  |  |  |  |  |  | Set flag if less or equal immediate signed
31 | 30 | 29 | 28 | 27 | 26 | 25 | 24 | 23 | 22 | 21 | 20 | 19 | 18 | 17 | 16 | 15 | 14 | 13 | 12 | 11 | 10 | 9 | 8 | 7 | 6 | 5 | 4 | 3 | 2 | 1 | 0 | Custom Instructions:
0 | 1 | 1 | 1 | 0 | 0 | D | ? | ? | ? | ? | A |  |  |  |  | B |  |  |  |  | Ra | Rb | Wd | opcode | ? | ? | ? | ? | ? | ? | ? | Nios custom
0 | 1 | 1 | 1 | 0 | 1 | ? | ? | ? | ? | ? | ? | ? | ? | ? | ? | 0 | 0 | 0 | 0 | 0 | 0 | 0 | 0 | 0 | 0 | 1 | 1 | 0 | 0 | 0 | 0 | Jump program 0x30
0 | 1 | 1 | 1 | 1 | 0 | D | ? | ? | ? | ? | A |  |  |  |  | B |  |  |  |  | ? | ? | ? | ? | ? | ? | ? | ? | ? | ? | ? | Cust3
0 | 1 | 1 | 1 | 1 | 1 | D | ? | ? | ? | ? | A |  |  |  |  | B |  |  |  |  | ? | ? | ? | ? | ? | ? | ? | ? | ? | ? | ? | Cust4
1 | 1 | 1 | 1 | 0 | 0 | D |  |  |  |  | A |  |  |  |  | B |  |  |  |  | ? | ? | ? | ? | ? | ? | ? | ? | ? | ? | ? | Cust5
1 | 1 | 1 | 1 | 0 | 1 | D | ? | ? | ? | ? | A |  |  |  |  | B |  |  |  |  | ? | ? | ? | ? | ? | ? | ? | ? | ? | ? | ? | Cust6
1 | 1 | 1 | 1 | 1 | 0 | D |  |  |  |  | A |  |  |  |  | B | ? | ? | ? | ? | ? | ? | ? | ? | ? | ? | ? | ? | ? | ? | ? | Cust7
1 | 1 | 1 | 1 | 1 | 1 | D |  |  |  |  | A |  |  |  |  | B |  |  |  |  | ? | ? | ? | ? | ? | ? | ? | ? | ? | ? | ? | Cust8
31 | 30 | 29 | 28 | 27 | 26 | 25 | 24 | 23 | 22 | 21 | 20 | 19 | 18 | 17 | 16 | 15 | 14 | 13 | 12 | 11 | 10 | 9 | 8 | 7 | 6 | 5 | 4 | 3 | 2 | 1 | 0 | Flow control instructions:
0 | 0 | 0 | 0 | 0 | 0 | I |  |  |  |  |  |  |  |  |  |  |  |  |  |  |  |  |  |  |  |  |  |  |  |  |  | Jump
0 | 0 | 0 | 0 | 0 | 1 | I |  |  |  |  |  |  |  |  |  |  |  |  |  |  |  |  |  |  |  |  |  |  |  |  |  | Jump and Link
0 | 1 | 0 | 0 | 0 | 1 | ? | ? | ? | ? | ? | ? | ? | ? | ? | ? | B |  |  |  |  | ? | ? | ? | ? | ? | ? | ? | ? | ? | ? | ? | Jump Register
0 | 1 | 0 | 0 | 1 | 0 | ? | ? | ? | ? | ? | ? | ? | ? | ? | ? | B |  |  |  |  | ? | ? | ? | ? | ? | ? | ? | ? | ? | ? | ? | Jump and Link Register
0 | 0 | 0 | 1 | 0 | 1 | 0 | 1 | ? | ? | ? | ? | ? | ? | ? | ? | I |  |  |  |  |  |  |  |  |  |  |  |  |  |  |  | NOP
0 | 0 | 1 | 0 | 0 | 1 | ? | ? | ? | ? | ? | ? | ? | ? | ? | ? | ? | ? | ? | ? | ? | ? | ? | ? | ? | ? | ? | ? | ? | ? | ? | ? | RTE
0 | 0 | 0 | 1 | 0 | 0 | I |  |  |  |  |  |  |  |  |  |  |  |  |  |  |  |  |  |  |  |  |  |  |  |  |  | Branch if flag
0 | 0 | 0 | 0 | 1 | 1 | I |  |  |  |  |  |  |  |  |  |  |  |  |  |  |  |  |  |  |  |  |  |  |  |  |  | Branch if no flag
31 | 30 | 29 | 28 | 27 | 26 | 25 | 24 | 23 | 22 | 21 | 20 | 19 | 18 | 17 | 16 | 15 | 14 | 13 | 12 | 11 | 10 | 9 | 8 | 7 | 6 | 5 | 4 | 3 | 2 | 1 | 0 | Load and store instructions:
1 | 0 | 0 | 1 | 0 | 0 | D |  |  |  |  | A |  |  |  |  | I |  |  |  |  |  |  |  |  |  |  |  |  |  |  |  | Load byte sign extended
1 | 0 | 0 | 0 | 1 | 1 | D |  |  |  |  | A |  |  |  |  | I |  |  |  |  |  |  |  |  |  |  |  |  |  |  |  | Load byte zero extended
1 | 0 | 0 | 1 | 1 | 0 | D |  |  |  |  | A |  |  |  |  | I |  |  |  |  |  |  |  |  |  |  |  |  |  |  |  | Load Half Word sign extended
1 | 0 | 0 | 1 | 0 | 1 | D |  |  |  |  | A |  |  |  |  | I |  |  |  |  |  |  |  |  |  |  |  |  |  |  |  | Load Half Word zero extended
1 | 0 | 0 | 0 | 1 | 0 | D |  |  |  |  | A |  |  |  |  | I |  |  |  |  |  |  |  |  |  |  |  |  |  |  |  | Load Word sign extended
1 | 0 | 0 | 0 | 0 | 1 | D |  |  |  |  | A |  |  |  |  | I |  |  |  |  |  |  |  |  |  |  |  |  |  |  |  | Load Word zero extended
1 | 1 | 0 | 1 | 1 | 0 | I |  |  |  |  | A |  |  |  |  | B |  |  |  |  | I |  |  |  |  |  |  |  |  |  |  | Store Byte
1 | 1 | 0 | 1 | 1 | 1 | I |  |  |  |  | A |  |  |  |  | B |  |  |  |  | I |  |  |  |  |  |  |  |  |  |  | Store Half Word
1 | 1 | 0 | 1 | 0 | 1 | I |  |  |  |  | A |  |  |  |  | B |  |  |  |  | I |  |  |  |  |  |  |  |  |  |  | Store Word
31 | 30 | 29 | 28 | 27 | 26 | 25 | 24 | 23 | 22 | 21 | 20 | 19 | 18 | 17 | 16 | 15 | 14 | 13 | 12 | 11 | 10 | 9 | 8 | 7 | 6 | 5 | 4 | 3 | 2 | 1 | 0 | Special purpose instructions:
1 | 0 | 1 | 1 | 0 | 1 | D |  |  |  |  | A |  |  |  |  | I |  |  |  |  |  |  |  |  |  |  |  |  |  |  |  | Move from special-purpose register
1 | 1 | 0 | 0 | 0 | 0 | I |  |  |  |  | A |  |  |  |  | B |  |  |  |  | I |  |  |  |  |  |  |  |  |  |  | Move to special-purpose register
31 | 30 | 29 | 28 | 27 | 26 | 25 | 24 | 23 | 22 | 21 | 20 | 19 | 18 | 17 | 16 | 15 | 14 | 13 | 12 | 11 | 10 | 9 | 8 | 7 | 6 | 5 | 4 | 3 | 2 | 1 | 0 | Multiply and divide instructions:
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

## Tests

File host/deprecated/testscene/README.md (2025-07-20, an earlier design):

```python
marker_position = (0.12, 0.8, 1.5) # m, blender coordinates
checker_size = 0.12 # m
offset_blender_to_world_origin = (-5*checker_size, 3.5*checker_size, 0) # m, apply to blender coordinates
```

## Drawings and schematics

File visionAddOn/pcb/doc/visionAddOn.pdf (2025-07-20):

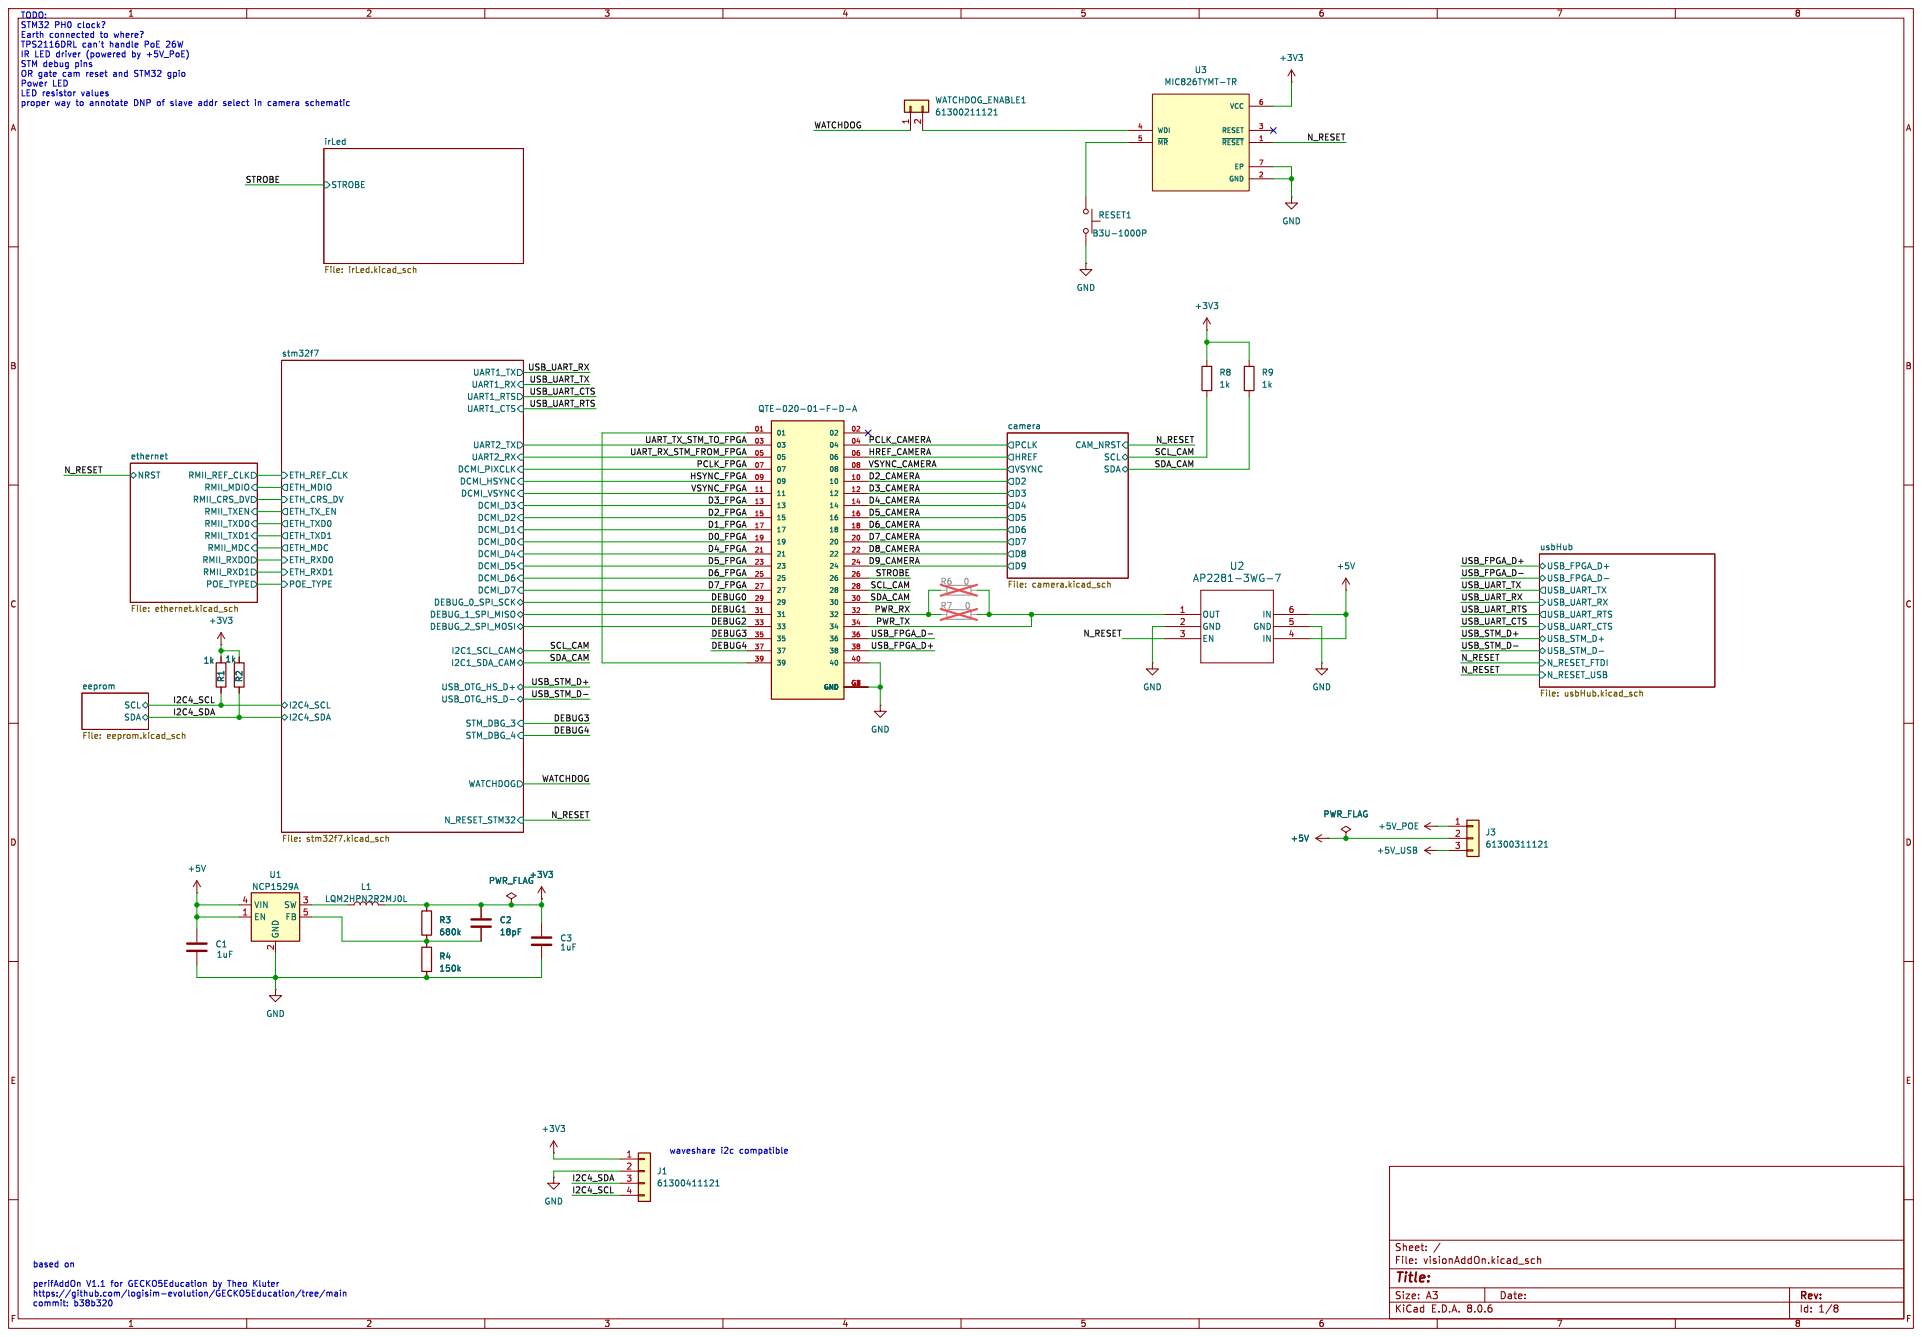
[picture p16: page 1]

IR LED driver (powered by +5V_PoE) STM debug pins OR gate cam reset and STM32 gpio Power LED

Id: 1/8 Title: File: visionAddOn.kicad_sch Sheet: /

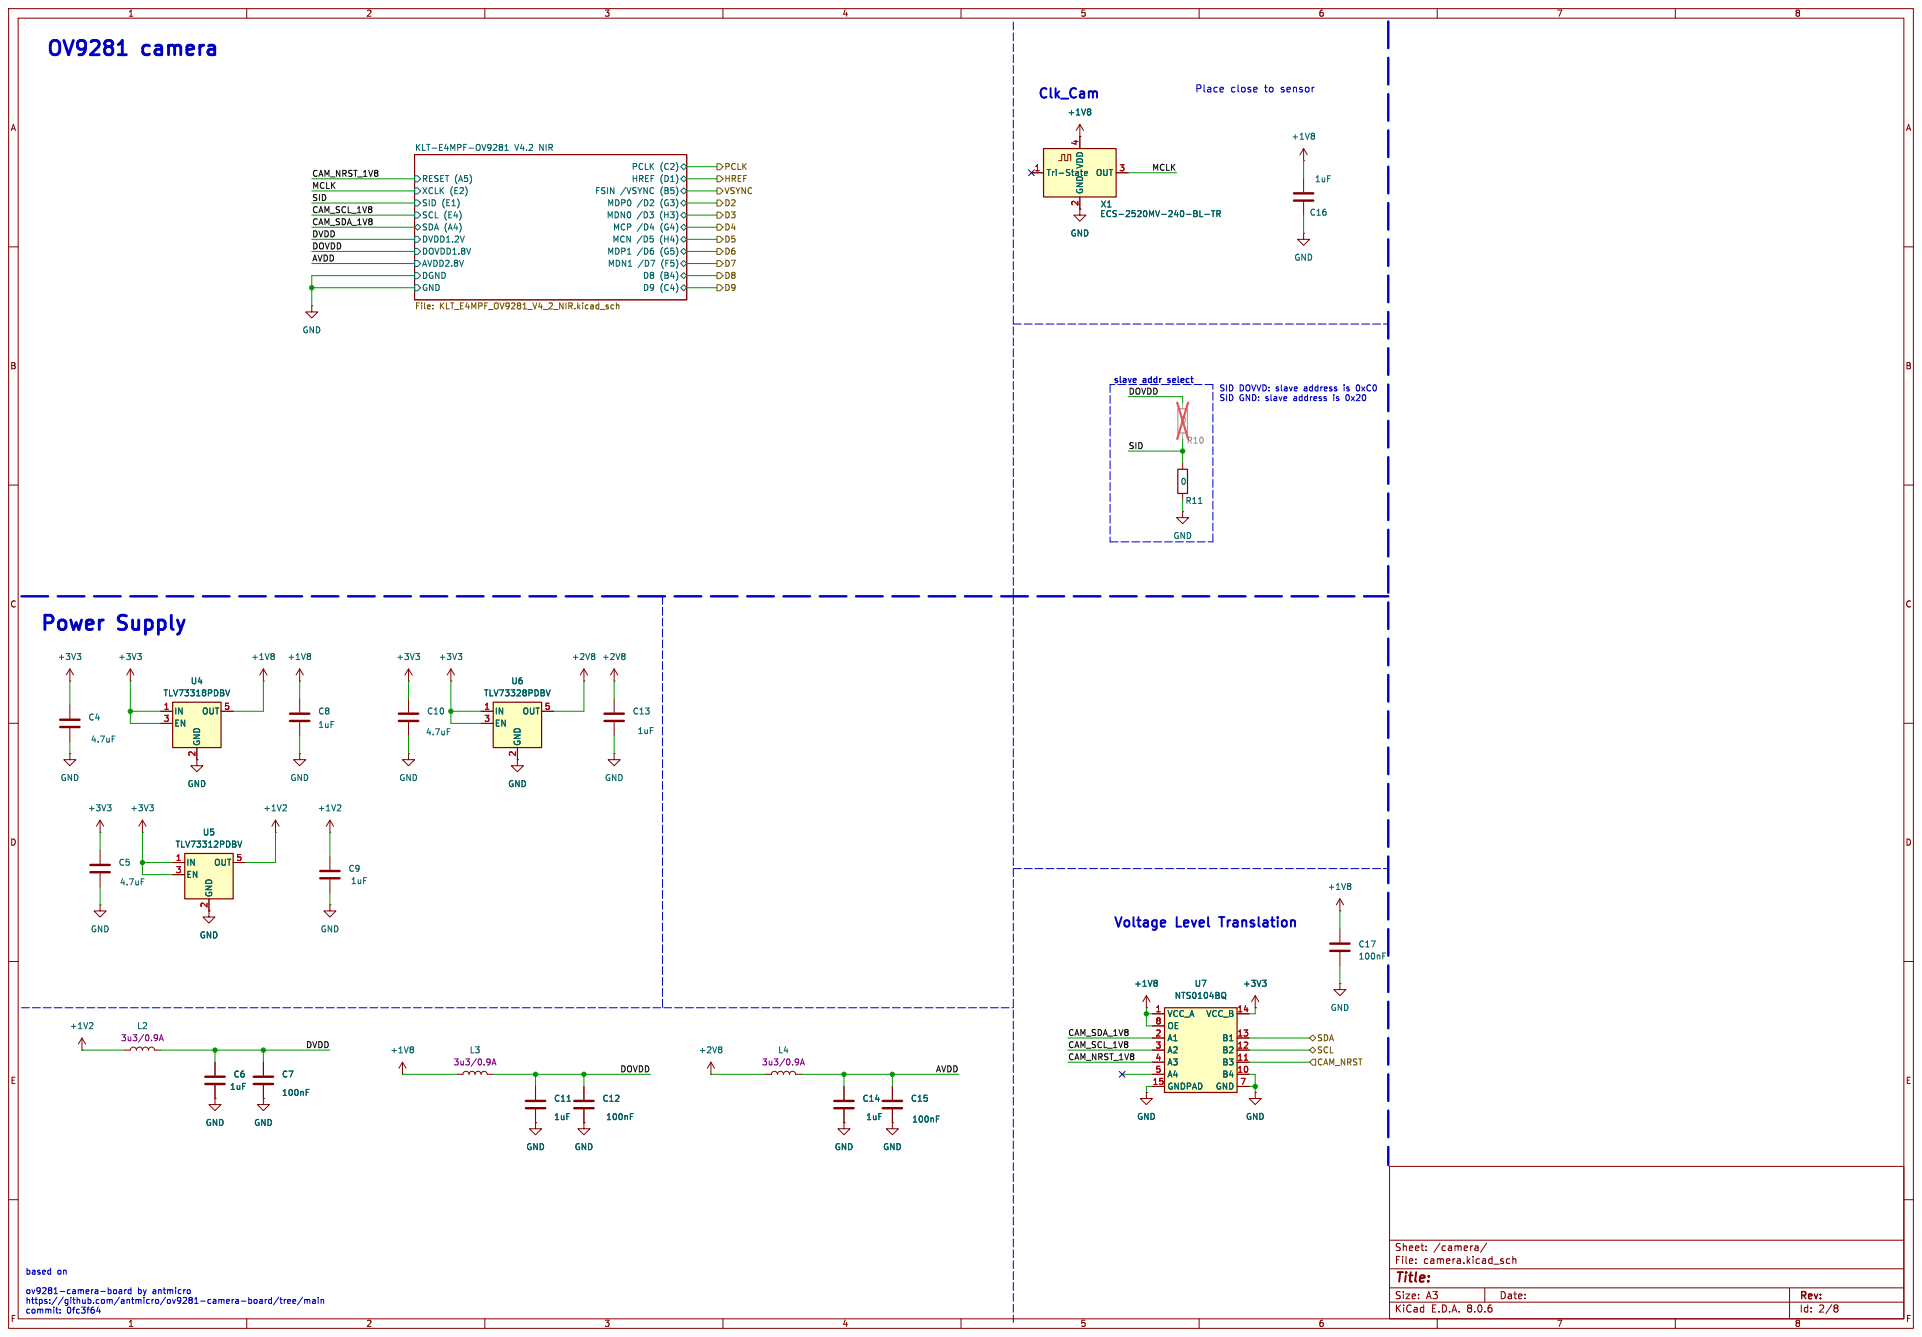
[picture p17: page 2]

slave addr selectPlace close to sensor U4 TLV73318PDBV

SID MCLK Clk_Cam
SID DOVVD: slave address is 0xC0 SID GND: slave address is 0x20 Voltage Level Translation
DOVDD

2 EN 3 OUT 5 U6 TLV73328PDBV GND GND GND

Id: 2/8 Title: File: camera.kicad_sch Sheet: /camera/

https://github.com/antmicro/ov9281-camera-board/tree/main

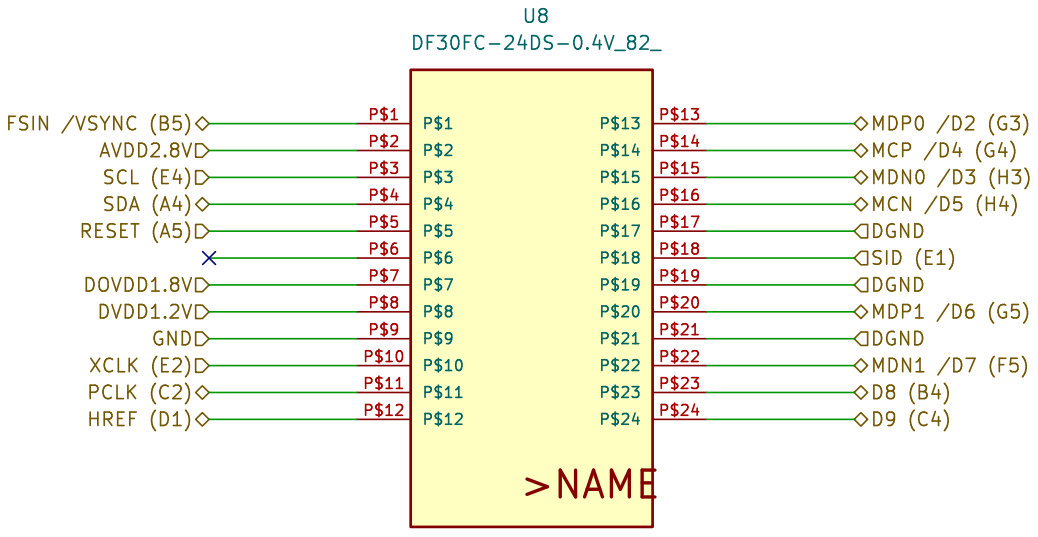
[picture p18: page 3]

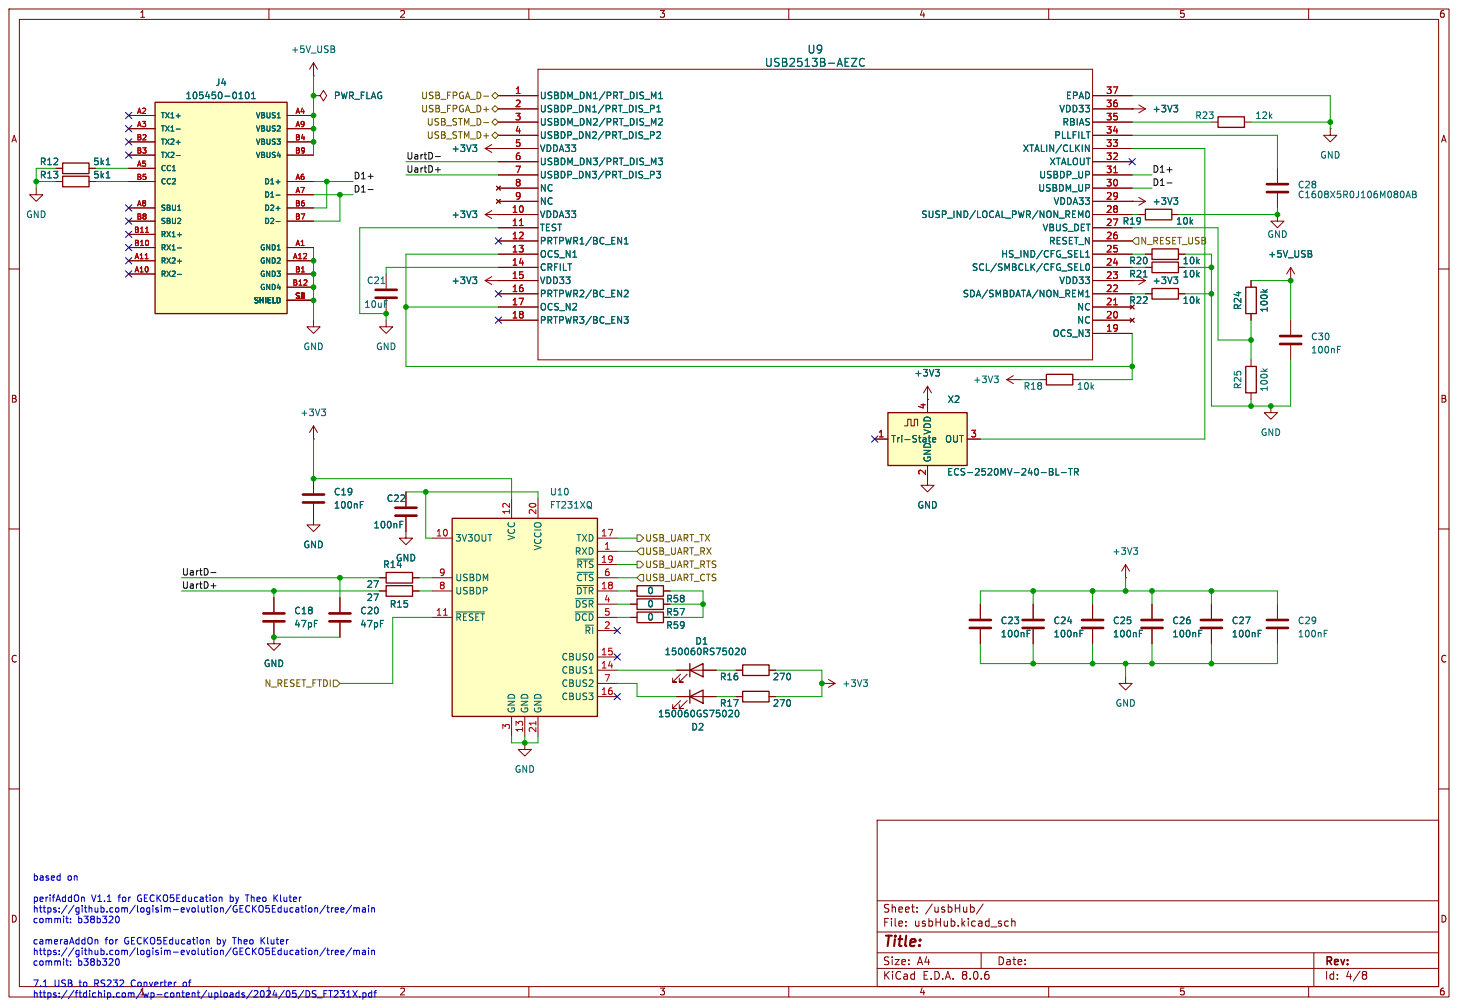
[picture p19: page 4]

3 ~{DSR}4 ~{DCD}5 ~{CTS}6 CBUS2 7 USBDP 8 USBDM 9 U10 FT231XQ

Id: 4/8 Title: File: usbHub.kicad_sch Sheet: /usbHub/ C22

7.1 USB to RS232 Converter of https://ftdichip.com/wp-content/uploads/2024/05/DS_FT231X.pdf

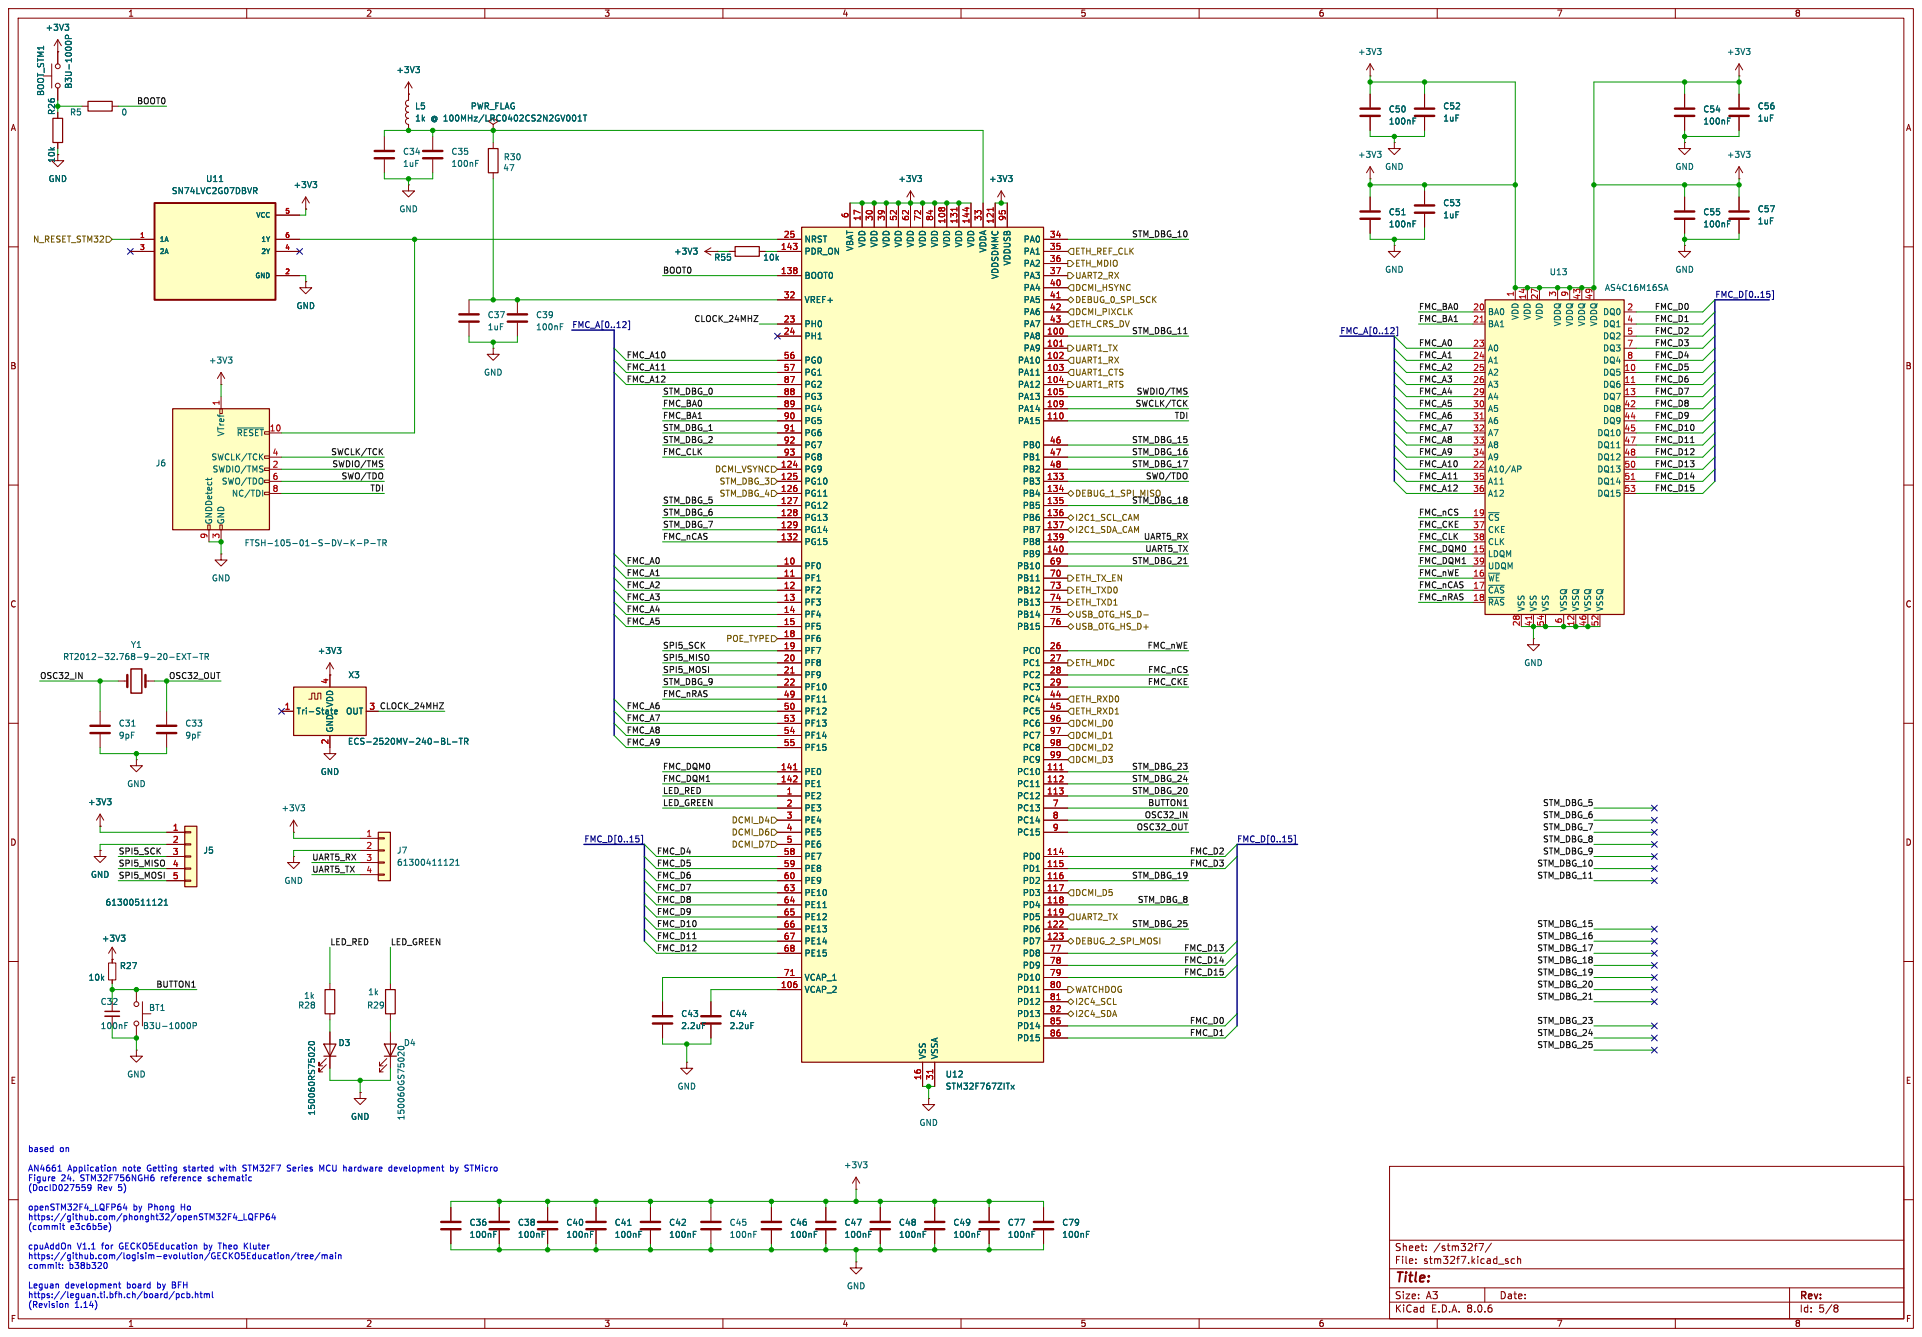
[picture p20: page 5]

3 A5 30 A6 31 A7 32 A8 33 A9 34 A11 35 A12 36 CKE 37 CLK 38 UDQM 39 DQ1 4 VSS 41 DQ8 42 VDDQ 43 DQ9 44 DQ10 45 VSSQ 46 DQ11 47 DQ12 48 VDDQ 49 DQ2 5 DQ13 50 DQ14 51 VSSQ 52 DQ15 53 VSS 54 VSSQ

3 SWCLK/TCK 4 SWO/TDO 6 NC/TDI 8 GNDDetect 9

Id: 5/8 Title: File: stm32f7.kicad_sch Sheet: /stm32f7/

https://leguan.ti.bfh.ch/board/pcb.html

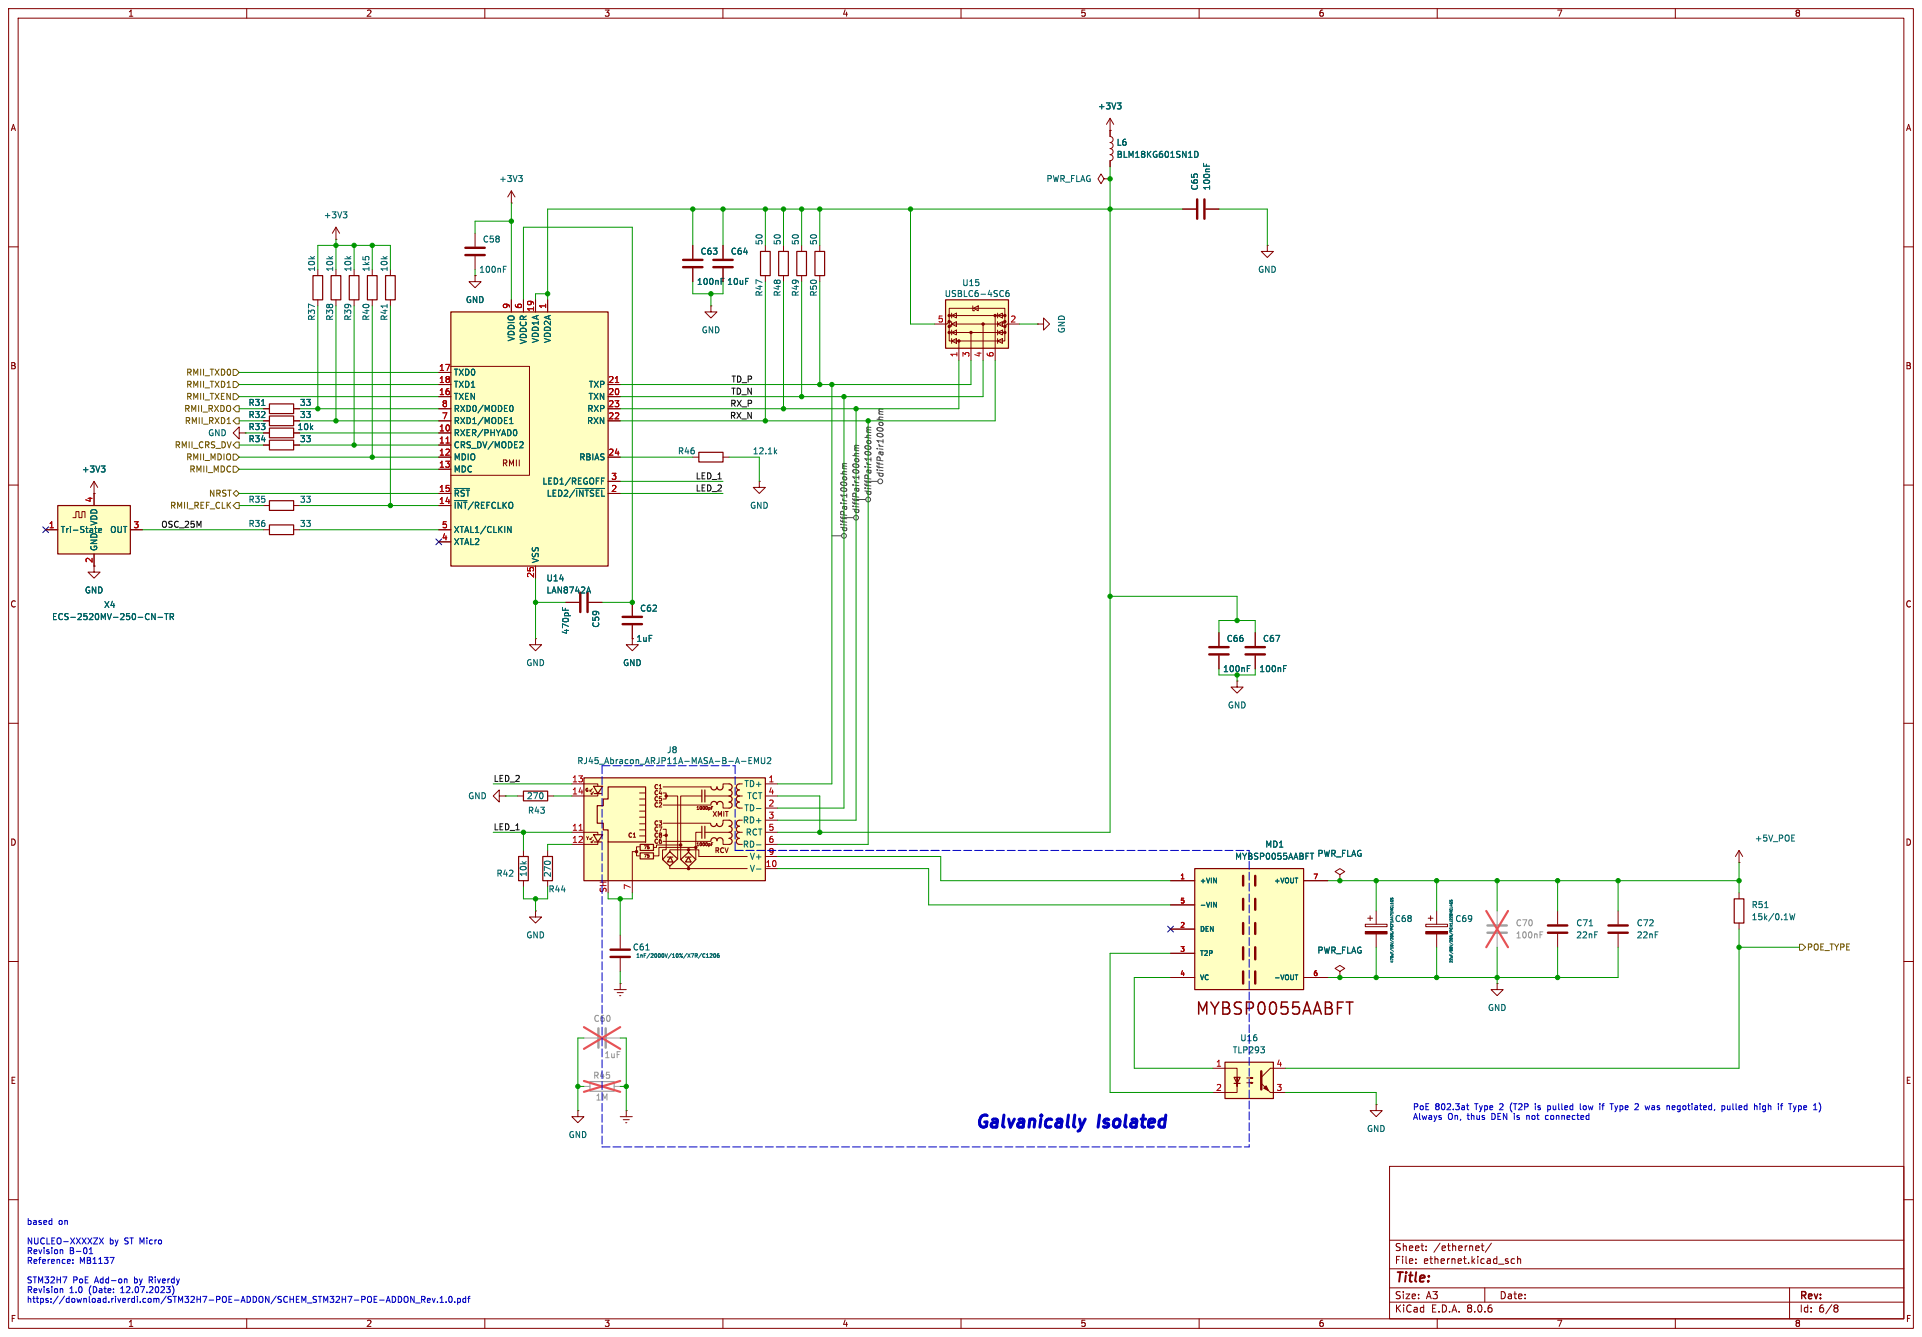
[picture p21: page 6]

LED2/~{INTSEL}2 TXN 20 TXP 21 RXN 22 RXP 23 RBIAS 24 VSS 25

Id: 6/8 Title: File: ethernet.kicad_sch Sheet: /ethernet/ R49 50 GND

1 RXER/PHYAD0 10 CRS_DV/MODE2 11 MDIO 12 MDC 13 ~{INT}/REFCLKO 14 ~{RST} 15 TXEN 16 TXD0 17 TXD1 18 VDD1A 19

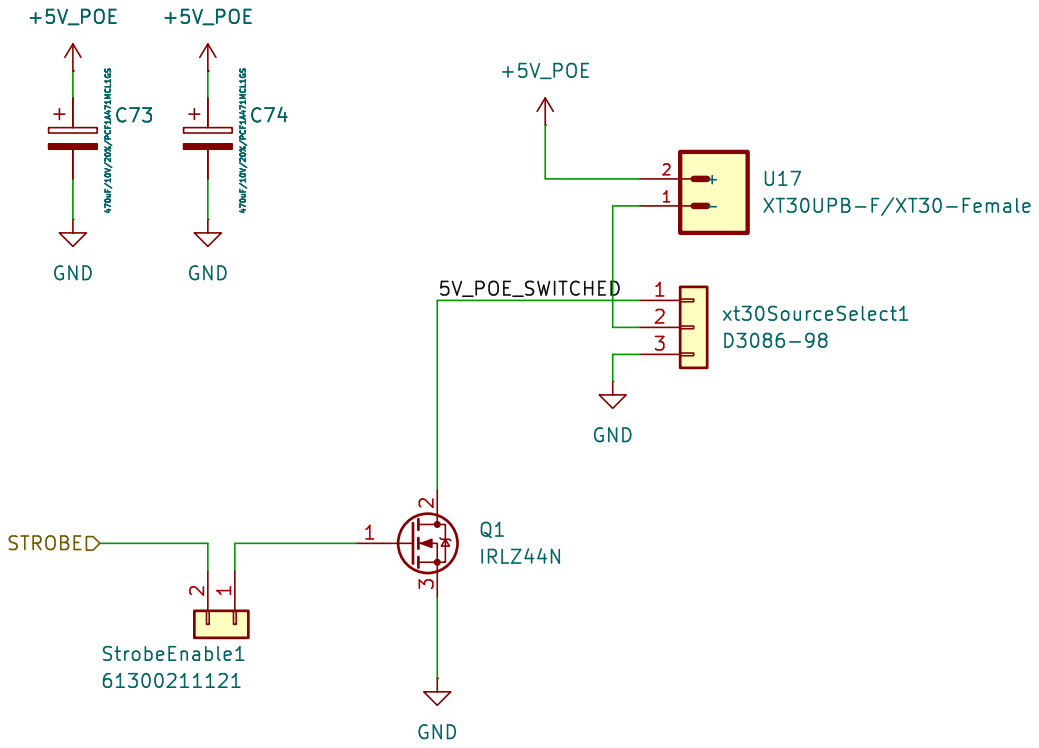
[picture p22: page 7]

Id: 7/8 Title: File: irLed.kicad_sch Sheet: /irLed/

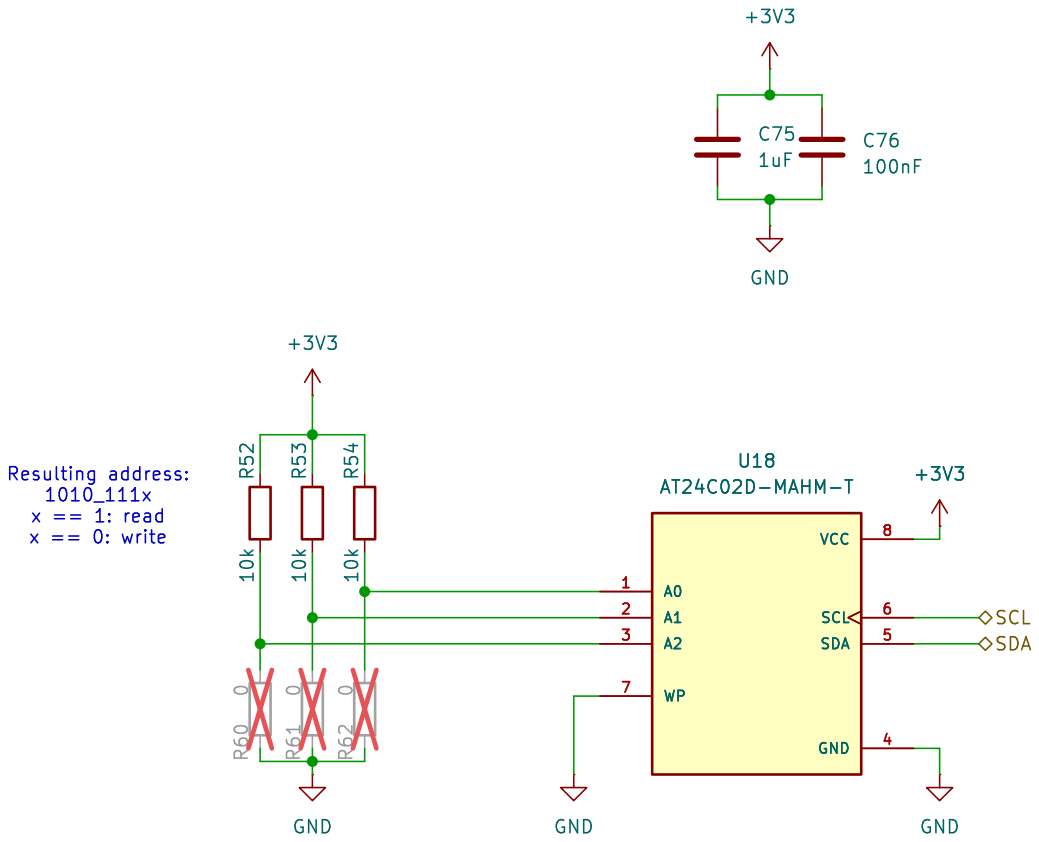
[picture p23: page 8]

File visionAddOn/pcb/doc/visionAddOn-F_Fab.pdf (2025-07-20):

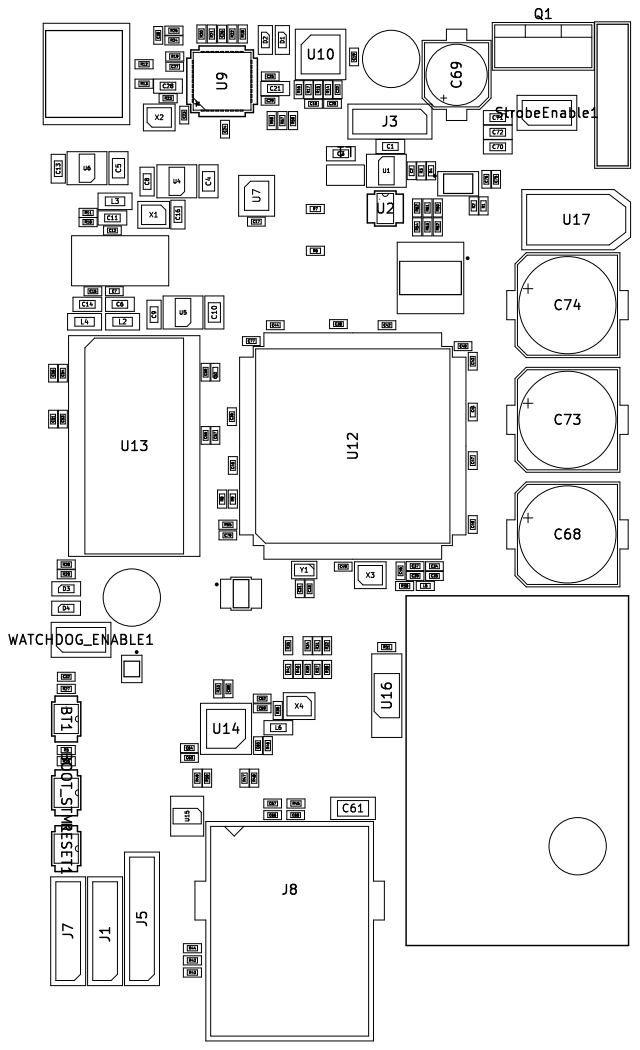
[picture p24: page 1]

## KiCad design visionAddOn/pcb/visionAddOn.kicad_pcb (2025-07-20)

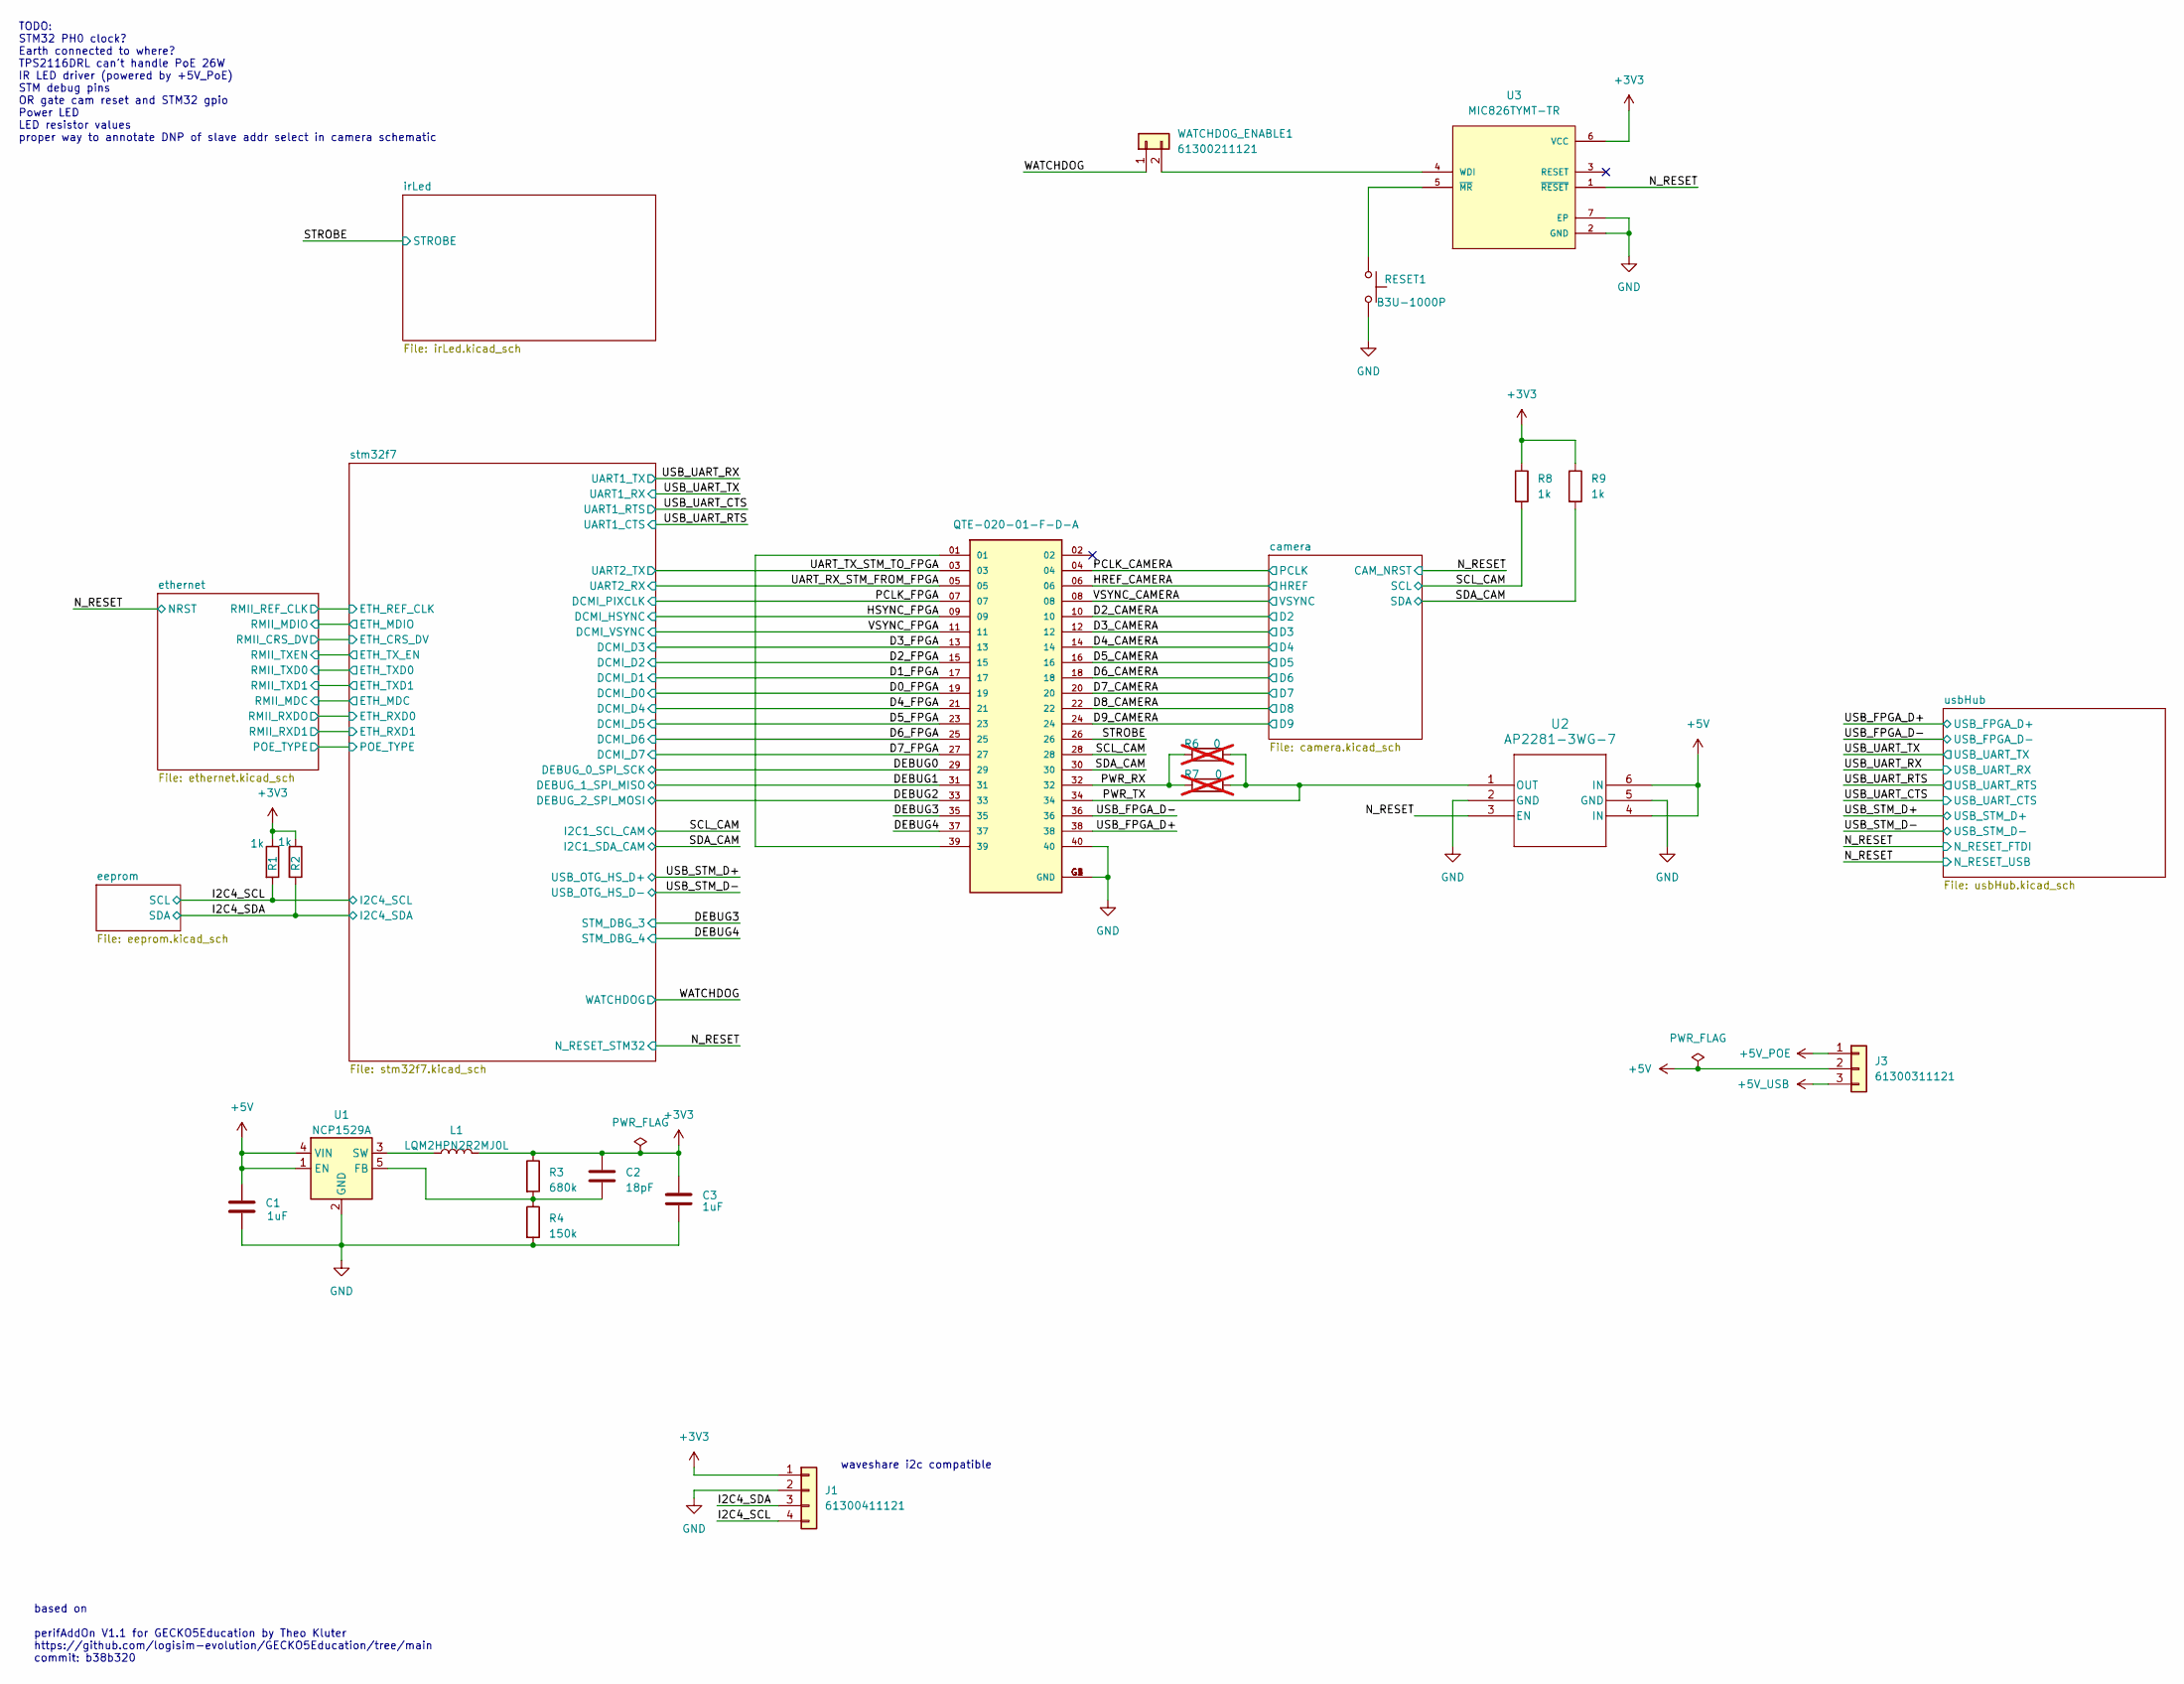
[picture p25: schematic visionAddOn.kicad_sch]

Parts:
C1, C3: 1uF; C_0603_1608Metric; DigiKey-Partnumber 445-4112-2-ND
C2: 18pF; C_0402_1005Metric; DigiKey-Partnumber 490-8082-2-ND
J1: 61300411121; PinHeader_1x04_P2.54mm_Vertical; DigiKey-Partnumber 732-5317-ND
J2: QTE-020-01-F-D-A; SAMTEC_QTE-020-01-X-D-A; DigiKey-Partnumber 612-QTE-020-01-F-D-A-TR-ND
J3: 61300311121; PinHeader_1x03_P2.54mm_Vertical; DigiKey-Partnumber 732-5316-ND
L1: LQM2HPN2R2MJ0L; DigiKey-Partnumber 490-6700-2-ND
R1, R2, R8, R9: 1k; R_0402_1005Metric; DigiKey-Partnumber 311-1.0KJRTR-ND
R3: 680k; R_0402_1005Metric; DigiKey-Partnumber 311-680KJRTR-ND
R4: 150k; R_0402_1005Metric; DigiKey-Partnumber 311-150KLRTR-ND
R6, R7: 0; R_0402_1005Metric; DigiKey-Partnumber 311-0.0JRTR-ND; not fitted
RESET1: B3U-1000P; SW_B3U-1000P_OMR; DigiKey-Partnumber SW1020TR-ND
U1: NCP1529A; SOT-23-5; DigiKey-Partnumber NCP1529ASNT1GOSTR-ND
U2: AP2281-3WG-7; SOT26_DIO; DigiKey-Partnumber AP2281-3WG-7DITR-ND
U3: MIC826TYMT-TR; MIC826TYMT-TR_SON50P160X160X60-7N; DigiKey-Partnumber 576-4375-2-ND
WATCHDOG_ENABLE1: 61300211121; PinHeader_1x02_P2.54mm_Vertical; DigiKey-Partnumber 732-5315-ND

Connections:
+3V3: C2.1, C3.1, J1.1, L1.2, R1.1, R2.1, R3.1, R8.1, R9.1, U3.6 (VCC); also elsewhere on the board
+5V: C1.1, J3.2, U1.1 (EN), U1.4 (VIN), U2.4 (IN), U2.6 (IN)
+5V_POE: J3.1; also elsewhere on the board
+5V_USB: J3.3; also elsewhere on the board
/D0_FPGA: J2.19; also elsewhere on the board
/D1_FPGA: J2.17; also elsewhere on the board
/D2_CAMERA: J2.10; also elsewhere on the board
/D2_FPGA: J2.15; also elsewhere on the board
/D3_CAMERA: J2.12; also elsewhere on the board
/D3_FPGA: J2.13; also elsewhere on the board
/D4_CAMERA: J2.14; also elsewhere on the board
/D4_FPGA: J2.21; also elsewhere on the board
/D5_CAMERA: J2.16; also elsewhere on the board
/D5_FPGA: J2.23; also elsewhere on the board
/D6_CAMERA: J2.18; also elsewhere on the board
/D6_FPGA: J2.25; also elsewhere on the board
/D7_CAMERA: J2.20; also elsewhere on the board
/D7_FPGA: J2.27; also elsewhere on the board
/D8_CAMERA: J2.22; also elsewhere on the board
/D9_CAMERA: J2.24; also elsewhere on the board
/DEBUG0: J2.29; also elsewhere on the board
/DEBUG1: J2.31; also elsewhere on the board
/DEBUG2: J2.33; also elsewhere on the board
/DEBUG3: J2.35; also elsewhere on the board
/DEBUG4: J2.37; also elsewhere on the board
/HREF_CAMERA: J2.06; also elsewhere on the board
/HSYNC_FPGA: J2.09; also elsewhere on the board
/I2C4_SCL: J1.4, R1.2; also elsewhere on the board
/I2C4_SDA: J1.3, R2.2; also elsewhere on the board
/N_RESET: U2.3 (EN), U3.1 (~RESET); also elsewhere on the board
/PCLK_CAMERA: J2.04; also elsewhere on the board
/PCLK_FPGA: J2.07; also elsewhere on the board
/PWR_RX: J2.32, R6.1, R7.1
/PWR_TX: J2.34, R6.2, R7.2, U2.1 (OUT)
/SCL_CAM: J2.28, R8.2; also elsewhere on the board
/SDA_CAM: J2.30, R9.2; also elsewhere on the board
/STROBE: J2.26; also elsewhere on the board
/UART_RX_STM_FROM_FPGA: J2.05; also elsewhere on the board
/UART_TX_STM_TO_FPGA: J2.03; also elsewhere on the board
/USB_FPGA_D+: J2.38; also elsewhere on the board
/USB_FPGA_D-: J2.36; also elsewhere on the board
/VSYNC_CAMERA: J2.08; also elsewhere on the board
/VSYNC_FPGA: J2.11; also elsewhere on the board
/WATCHDOG: WATCHDOG_ENABLE1.1; also elsewhere on the board
GND: C1.2, C3.2, J1.2, J2.40, J2.G1 (GND), J2.G2 (GND), J2.G3 (GND), J2.G4 (GND), R4.2, RESET1.2, U1.2 (GND), U2.2 (GND), U2.5 (GND), U3.2 (GND), U3.7 (EP); also elsewhere on the board
unnamed: J2.01, J2.39
unnamed: C2.2, R3.2, R4.1, U1.5 (FB)
unnamed: L1.1, U1.3 (SW)
unnamed: U3.4 (WDI), WATCHDOG_ENABLE1.2
unnamed: RESET1.1, U3.5 (~MR)

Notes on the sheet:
waveshare i2c compatible
TODO: STM32 PH0 clock? Earth connected to where? TPS2116DRL can't handle PoE 26W IR LED driver (powered by +5V_PoE) STM debug pins OR gate cam reset and STM32 gpio Power LED LED resistor values proper way to annotate DNP of slave addr select in camera schematic
based on perifAddOn V1.1 for GECKO5Education by Theo Kluter https://github.com/logisim-evolution/GECKO5Education/tree/main commit: b38b320

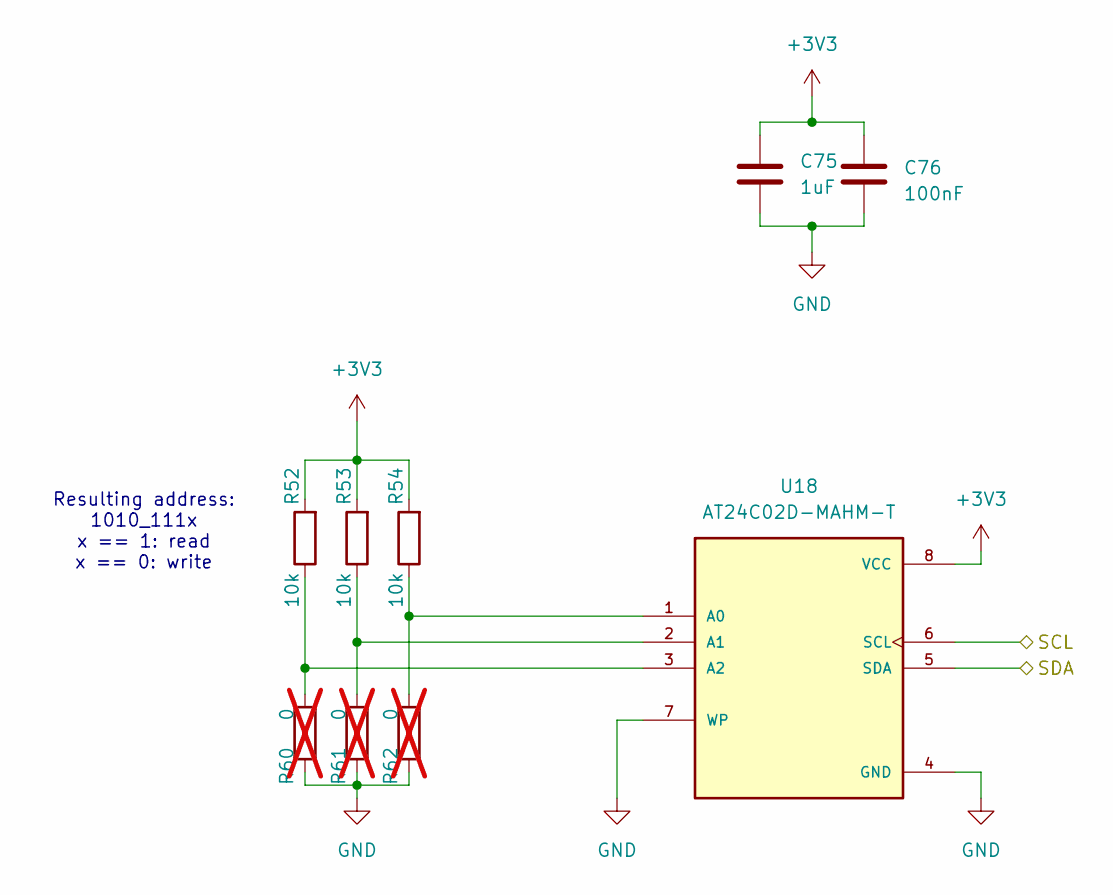
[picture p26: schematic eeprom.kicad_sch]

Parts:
C75: 1uF; C_0402_1005Metric; DigiKey-Partnumber 490-10024-2-ND
C76: 100nF; C_0402_1005Metric; DigiKey-Partnumber 490-6328-2-ND
R52, R53, R54: 10k; R_0402_1005Metric; DigiKey-Partnumber 311-10KJRTR-ND
R60, R61, R62: 0; R_0402_1005Metric; DigiKey-Partnumber 311-0.0JRTR-ND; not fitted
U18: AT24C02D-MAHM-T; AT24C02D-MAHM-T_SON50P200X300X60-9N; DigiKey-Partnumber AT24C02D-MAHM-TTR-ND

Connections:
+3V3: C75.1, C76.1, R52.2, R53.2, R54.2, U18.8 (VCC); also elsewhere on the board
/I2C4_SCL: U18.6 (SCL); also elsewhere on the board
/I2C4_SDA: U18.5 (SDA); also elsewhere on the board
GND: C75.2, C76.2, R60.1, R61.1, R62.1, U18.4 (GND), U18.7 (WP); also elsewhere on the board
unnamed: R54.1, R62.2, U18.1 (A0)
unnamed: R53.1, R61.2, U18.2 (A1)
unnamed: R52.1, R60.2, U18.3 (A2)

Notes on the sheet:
Resulting address: 1010_111x x == 1: read x == 0: write

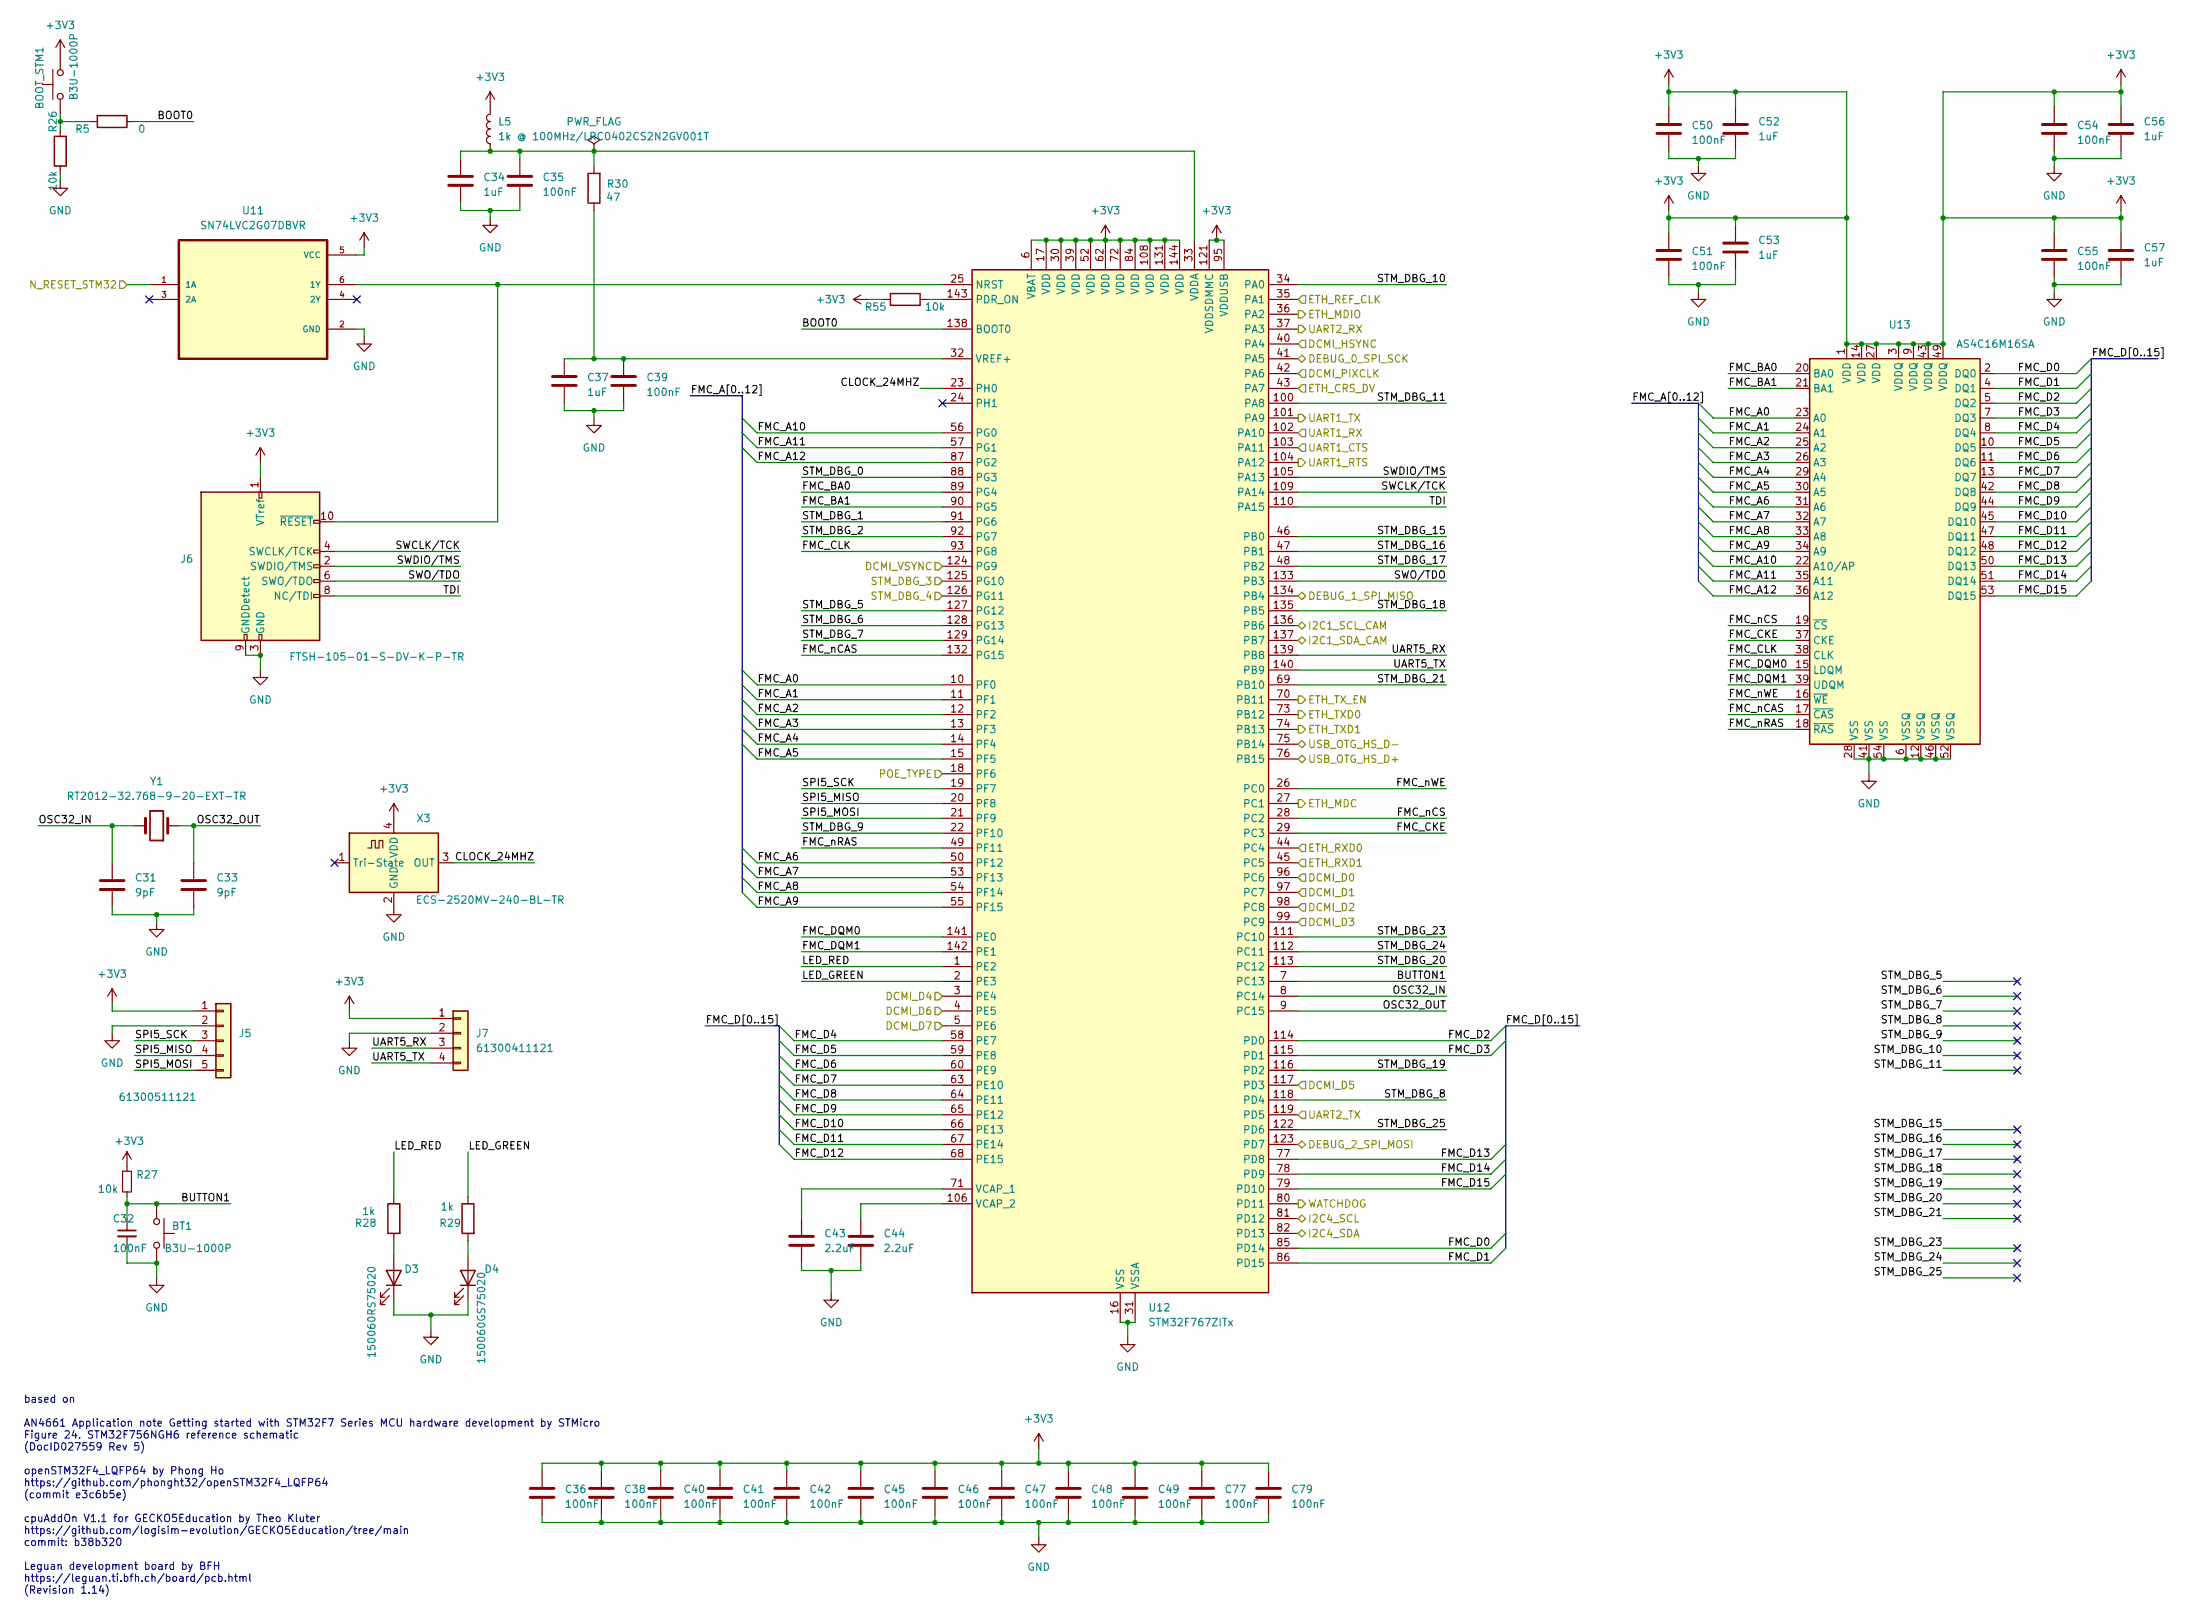
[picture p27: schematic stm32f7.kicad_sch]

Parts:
BOOT_STM1: B3U-1000P; SW_B3U-1000P_OMR; DigiKey-Partnumber SW1020TR-ND
BT1: B3U-1000P; SW_B3U-1000P_OMR; DigiKey-Partnumber SW1020TR-ND
C31, C33: 9pF; C_0402_1005Metric; DigiKey-Partnumber 490-8232-2-ND
C32, C35, C36, C38, C39, C40, C41, C42, C45, C46, C47, C48, C49, C50, C51, C54, C55, C77, C79: 100nF; C_0402_1005Metric; DigiKey-Partnumber 490-6328-2-ND
C34, C37, C52, C53, C56, C57: 1uF; C_0402_1005Metric; DigiKey-Partnumber 490-10024-2-ND
C43, C44: 2.2uF; C_0402_1005Metric; DigiKey-Partnumber 490-10012-2-ND
D3: 150060RS75020; LED_0603_1608Metric; DigiKey-Partnumber 732-150060RS75020TR-ND
D4: 150060GS75020; LED_0603_1608Metric; DigiKey-Partnumber 732-150060GS75020TR-ND
J5: 61300511121; PinHeader_1x05_P2.54mm_Vertical; DigiKey-Partnumber 732-5318-ND
J6: FTSH-105-01-S-DV-K-P-TR; SAMTEC_FTSH-105-01-S-DV-TR; DigiKey-Partnumber SAM13935TR-ND
J7: 61300411121; PinHeader_1x04_P2.54mm_Vertical; DigiKey-Partnumber 732-5317-ND
L5: 1k @ 100MHz/LRC0402CS2N2GV001T; L_0402_1005Metric; DigiKey-Partnumber 712-LRC0402CS2N2GV001TTR-ND
R5: 0; R_0402_1005Metric; DigiKey-Partnumber 311-0.0JRTR-ND
R26, R27, R55: 10k; R_0402_1005Metric; DigiKey-Partnumber 311-10KJRTR-ND
R28, R29: 1k; R_0402_1005Metric; DigiKey-Partnumber 311-1.0KJRTR-ND
R30: 47; R_0402_1005Metric; DigiKey-Partnumber RMCF0402JT47R0TR-ND
U11: SN74LVC2G07DBVR; SOT95P280X145-6N; DigiKey-Partnumber 296-13494-2-ND
U12: STM32F767ZITx; LQFP-144_20x20mm_P0.5mm; DigiKey-Partnumber 497-16521-ND
U13: AS4C16M16SA; TSOP-II-54_22.2x10.16mm_P0.8mm; DigiKey-Partnumber 1450-1252-ND
X3: ECS-2520MV-240-BL-TR; Oscillator_SMD_ECS_2520MV-xxx-xx-4Pin_2.5x2.0mm; DigiKey-Partnumber 50-ECS-2520MV-240-BL-TR-ND
Y1: RT2012-32.768-9-20-EXT-TR; Crystal_SMD_2012-2Pin_2.0x1.2mm; DigiKey-Partnumber 2151-RT2012-32.768-9-20-EXT-TR-ND

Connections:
+3V3: BOOT_STM1.2, C36.1, C38.1, C40.1, C41.1, C42.1, C45.1, C46.1, C47.1, C48.1, C49.1, C50.1, C51.1, C52.1, C53.1, C54.1, C55.1, C56.1, C57.1, C77.1, C79.1, J5.1, J6.1 (VTref), J7.1, L5.2, R27.1, R55.2, U11.5 (VCC), U12.6 (VBAT), U12.17 (VDD), U12.30 (VDD), U12.39 (VDD), U12.52 (VDD), U12.62 (VDD), U12.72 (VDD), U12.84 (VDD), U12.95 (VDDUSB), U12.108 (VDD), U12.121 (VDDSDMMC), U12.131 (VDD), U12.144 (VDD), U13.1 (VDD), U13.3 (VDDQ), U13.9 (VDDQ), U13.14 (VDD), U13.27 (VDD), U13.43 (VDDQ), U13.49 (VDDQ), X3.4 (VDD); also elsewhere on the board
/D0_FPGA: U12.96 (PC6); also elsewhere on the board
/D1_FPGA: U12.97 (PC7); also elsewhere on the board
/D2_FPGA: U12.98 (PC8); also elsewhere on the board
/D3_FPGA: U12.99 (PC9); also elsewhere on the board
/D4_FPGA: U12.3 (PE4); also elsewhere on the board
/D5_FPGA: U12.117 (PD3); also elsewhere on the board
/D6_FPGA: U12.4 (PE5); also elsewhere on the board
/D7_FPGA: U12.5 (PE6); also elsewhere on the board
/DEBUG0: U12.41 (PA5); also elsewhere on the board
/DEBUG1: U12.134 (PB4); also elsewhere on the board
/DEBUG2: U12.123 (PD7); also elsewhere on the board
/DEBUG3: U12.125 (PG10); also elsewhere on the board
/DEBUG4: U12.126 (PG11); also elsewhere on the board
/HSYNC_FPGA: U12.40 (PA4); also elsewhere on the board
/I2C4_SCL: U12.81 (PD12); also elsewhere on the board
/I2C4_SDA: U12.82 (PD13); also elsewhere on the board
/N_RESET: U11.1 (1A); also elsewhere on the board
/PCLK_FPGA: U12.42 (PA6); also elsewhere on the board
/SCL_CAM: U12.136 (PB6); also elsewhere on the board
/SDA_CAM: U12.137 (PB7); also elsewhere on the board
/UART_RX_STM_FROM_FPGA: U12.37 (PA3); also elsewhere on the board
/UART_TX_STM_TO_FPGA: U12.119 (PD5); also elsewhere on the board
/USB_STM_D+: U12.76 (PB15); also elsewhere on the board
/USB_STM_D-: U12.75 (PB14); also elsewhere on the board
/USB_UART_CTS: U12.104 (PA12); also elsewhere on the board
/USB_UART_RTS: U12.103 (PA11); also elsewhere on the board
/USB_UART_RX: U12.101 (PA9); also elsewhere on the board
/USB_UART_TX: U12.102 (PA10); also elsewhere on the board
/VSYNC_FPGA: U12.124 (PG9); also elsewhere on the board
/WATCHDOG: U12.80 (PD11); also elsewhere on the board
/ethernet/POE_TYPE: U12.18 (PF6); also elsewhere on the board
/ethernet/RMII_CRS_DV: U12.43 (PA7); also elsewhere on the board
/ethernet/RMII_MDC: U12.27 (PC1); also elsewhere on the board
/ethernet/RMII_MDIO: U12.36 (PA2); also elsewhere on the board
/ethernet/RMII_REF_CLK: U12.35 (PA1); also elsewhere on the board
/ethernet/RMII_RXD1: U12.45 (PC5); also elsewhere on the board
/ethernet/RMII_RXDO: U12.44 (PC4); also elsewhere on the board
/ethernet/RMII_TXD0: U12.73 (PB12); also elsewhere on the board
/ethernet/RMII_TXD1: U12.74 (PB13); also elsewhere on the board
/ethernet/RMII_TXEN: U12.70 (PB11); also elsewhere on the board
/stm32f7/BOOT0: R5.1, U12.138 (BOOT0)
/stm32f7/BUTTON1: BT1.1, C32.1, R27.2, U12.7 (PC13)
/stm32f7/CLOCK_24MHZ: U12.23 (PH0), X3.3 (OUT)
/stm32f7/FMC_A0: U12.10 (PF0), U13.23 (A0)
/stm32f7/FMC_A1: U12.11 (PF1), U13.24 (A1)
/stm32f7/FMC_A2: U12.12 (PF2), U13.25 (A2)
/stm32f7/FMC_A3: U12.13 (PF3), U13.26 (A3)
/stm32f7/FMC_A4: U12.14 (PF4), U13.29 (A4)
/stm32f7/FMC_A5: U12.15 (PF5), U13.30 (A5)
/stm32f7/FMC_A6: U12.50 (PF12), U13.31 (A6)
/stm32f7/FMC_A7: U12.53 (PF13), U13.32 (A7)
/stm32f7/FMC_A8: U12.54 (PF14), U13.33 (A8)
/stm32f7/FMC_A9: U12.55 (PF15), U13.34 (A9)
/stm32f7/FMC_A10: U12.56 (PG0), U13.22 (A10/AP)
/stm32f7/FMC_A11: U12.57 (PG1), U13.35 (A11)
/stm32f7/FMC_A12: U12.87 (PG2), U13.36 (A12)
/stm32f7/FMC_BA0: U12.89 (PG4), U13.20 (BA0)
/stm32f7/FMC_BA1: U12.90 (PG5), U13.21 (BA1)
/stm32f7/FMC_CKE: U12.29 (PC3), U13.37 (CKE)
/stm32f7/FMC_CLK: U12.93 (PG8), U13.38 (CLK)
/stm32f7/FMC_D0: U12.85 (PD14), U13.2 (DQ0)
/stm32f7/FMC_D1: U12.86 (PD15), U13.4 (DQ1)
/stm32f7/FMC_D2: U12.114 (PD0), U13.5 (DQ2)
/stm32f7/FMC_D3: U12.115 (PD1), U13.7 (DQ3)
/stm32f7/FMC_D4: U12.58 (PE7), U13.8 (DQ4)
/stm32f7/FMC_D5: U12.59 (PE8), U13.10 (DQ5)
/stm32f7/FMC_D6: U12.60 (PE9), U13.11 (DQ6)
/stm32f7/FMC_D7: U12.63 (PE10), U13.13 (DQ7)
/stm32f7/FMC_D8: U12.64 (PE11), U13.42 (DQ8)
/stm32f7/FMC_D9: U12.65 (PE12), U13.44 (DQ9)
/stm32f7/FMC_D10: U12.66 (PE13), U13.45 (DQ10)
/stm32f7/FMC_D11: U12.67 (PE14), U13.47 (DQ11)
/stm32f7/FMC_D12: U12.68 (PE15), U13.48 (DQ12)
/stm32f7/FMC_D13: U12.77 (PD8), U13.50 (DQ13)
/stm32f7/FMC_D14: U12.78 (PD9), U13.51 (DQ14)
/stm32f7/FMC_D15: U12.79 (PD10), U13.53 (DQ15)
/stm32f7/FMC_DQM0: U12.141 (PE0), U13.15 (LDQM)
/stm32f7/FMC_DQM1: U12.142 (PE1), U13.39 (UDQM)
/stm32f7/FMC_nCAS: U12.132 (PG15), U13.17 (~CAS)
/stm32f7/FMC_nCS: U12.28 (PC2), U13.19 (~CS)
/stm32f7/FMC_nRAS: U12.49 (PF11), U13.18 (~RAS)
/stm32f7/FMC_nWE: U12.26 (PC0), U13.16 (~WE)
/stm32f7/LED_GREEN: R29.1, U12.2 (PE3)
/stm32f7/LED_RED: R28.1, U12.1 (PE2)
/stm32f7/OSC32_IN: C31.1, U12.8 (PC14), Y1.2
/stm32f7/OSC32_OUT: C33.1, U12.9 (PC15), Y1.1
/stm32f7/SPI5_MISO: J5.4, U12.20 (PF8)
/stm32f7/SPI5_MOSI: J5.5, U12.21 (PF9)
/stm32f7/SPI5_SCK: J5.3, U12.19 (PF7)
/stm32f7/STM_DBG_0: U12.88 (PG3)
/stm32f7/STM_DBG_1: U12.91 (PG6)
/stm32f7/STM_DBG_2: U12.92 (PG7)
/stm32f7/STM_DBG_5: U12.127 (PG12)
/stm32f7/STM_DBG_6: U12.128 (PG13)
/stm32f7/STM_DBG_7: U12.129 (PG14)
/stm32f7/STM_DBG_8: U12.118 (PD4)
/stm32f7/STM_DBG_9: U12.22 (PF10)
/stm32f7/STM_DBG_10: U12.34 (PA0)
/stm32f7/STM_DBG_11: U12.100 (PA8)
/stm32f7/STM_DBG_15: U12.46 (PB0)
/stm32f7/STM_DBG_16: U12.47 (PB1)
/stm32f7/STM_DBG_17: U12.48 (PB2)
/stm32f7/STM_DBG_18: U12.135 (PB5)
/stm32f7/STM_DBG_19: U12.116 (PD2)
/stm32f7/STM_DBG_20: U12.113 (PC12)
/stm32f7/STM_DBG_21: U12.69 (PB10)
/stm32f7/STM_DBG_23: U12.111 (PC10)
/stm32f7/STM_DBG_24: U12.112 (PC11)
/stm32f7/STM_DBG_25: U12.122 (PD6)
/stm32f7/SWCLK/TCK: J6.4 (SWCLK/TCK), U12.109 (PA14)
/stm32f7/SWDIO/TMS: J6.2 (SWDIO/TMS), U12.105 (PA13)
/stm32f7/SWO/TDO: J6.6 (SWO/TDO), U12.133 (PB3)
/stm32f7/TDI: J6.8 (NC/TDI), U12.110 (PA15)
/stm32f7/UART5_RX: J7.3, U12.139 (PB8)
/stm32f7/UART5_TX: J7.4, U12.140 (PB9)
GND: BT1.2, C31.2, C32.2, C33.2, C34.2, C35.2, C36.2, C37.2, C38.2, C39.2, C40.2, C41.2, C42.2, C43.2, C44.2, C45.2, C46.2, C47.2, C48.2, C49.2, C50.2, C51.2, C52.2, C53.2, C54.2, C55.2, C56.2, C57.2, C77.2, C79.2, D3.1 (K), D4.1 (K), J5.2, J6.3 (GND), J6.5 (GND), J6.9 (GNDDetect), J7.2, R26.1, U11.2 (GND), U12.16 (VSS), U12.31 (VSSA), U12.38 (VSS), U12.51 (VSS), U12.61 (VSS), U12.83 (VSS), U12.94 (VSS), U12.107 (VSS), U12.120 (VSS), U12.130 (VSS), U13.6 (VSSQ), U13.12 (VSSQ), U13.28 (VSS), U13.41 (VSS), U13.46 (VSSQ), U13.52 (VSSQ), U13.54 (VSS), X3.2 (GND); also elsewhere on the board
unnamed: BOOT_STM1.1, R5.2, R26.2
unnamed: D3.2 (A), R28.2
unnamed: D4.2 (A), R29.2
unnamed: J6.10 (~RESET), U11.6 (1Y), U12.25 (NRST)
unnamed: R55.1, U12.143 (PDR_ON)
unnamed: C43.1, U12.71 (VCAP_1)
unnamed: C44.1, U12.106 (VCAP_2)
unnamed: C34.1, C35.1, L5.1, R30.2, U12.33 (VDDA)
unnamed: C37.1, C39.1, R30.1, U12.32 (VREF+)

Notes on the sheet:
based on AN4661 Application note Getting started with STM32F7 Series MCU hardware development by STMicro Figure 24. STM32F756NGH6 reference schematic (DocID027559 Rev 5) openSTM32F4_LQFP64 by Phong Ho https://github.com/phonght32/openSTM32F4_LQFP64 (commit e3c6b5e) cpuAddOn V1.1 for GECKO5Education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

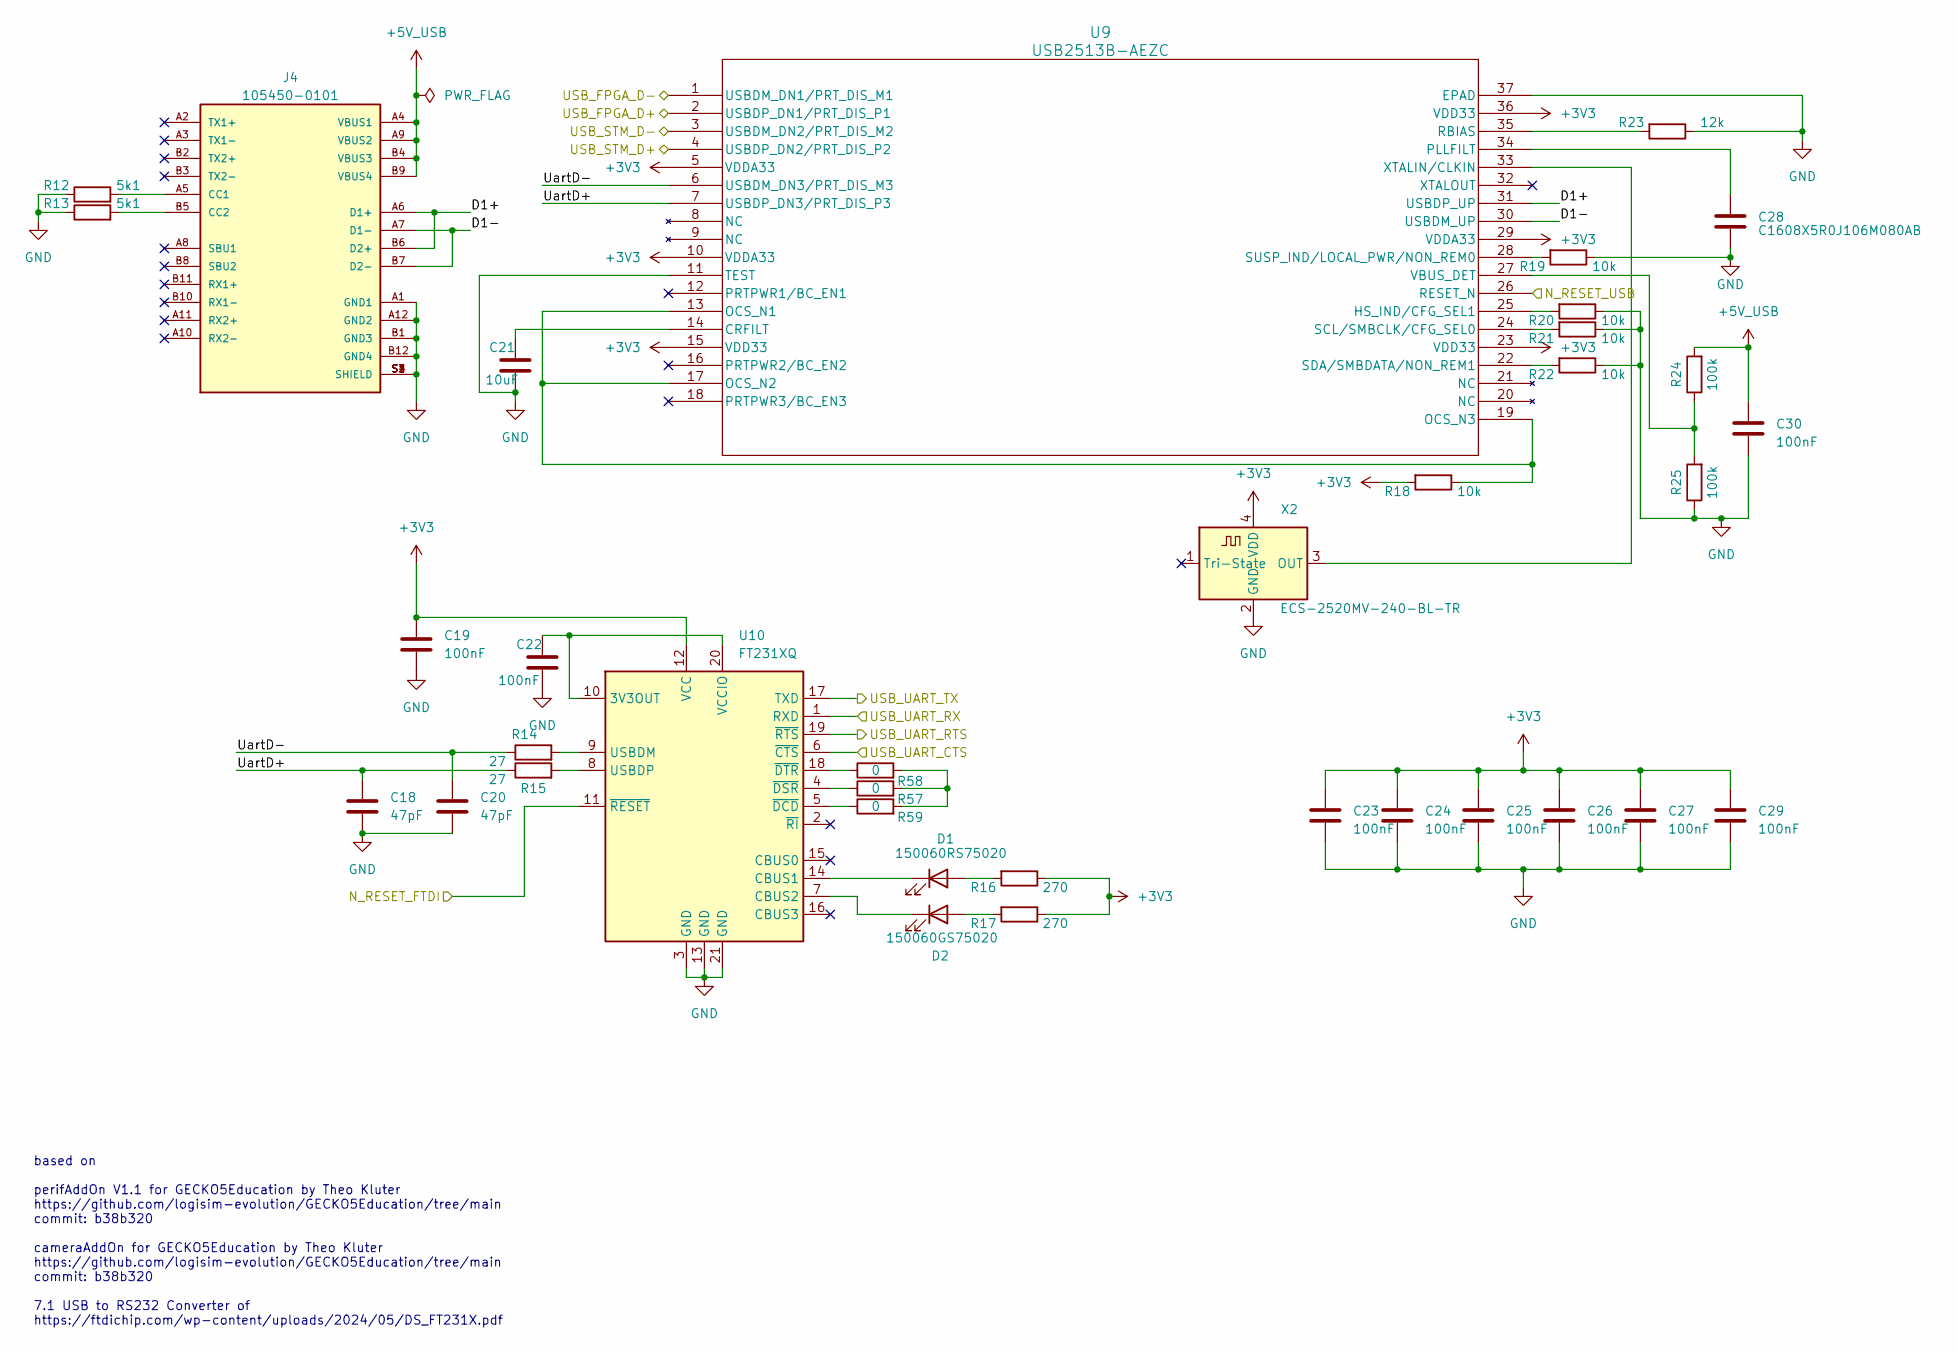
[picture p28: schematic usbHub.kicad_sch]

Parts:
C18, C20: 47pF; C_0402_1005Metric; DigiKey-Partnumber 490-5942-2-ND
C19, C22, C23, C24, C25, C26, C27, C29, C30: 100nF; C_0402_1005Metric; DigiKey-Partnumber 490-6328-2-ND
C21: 10uF; C_0603_1608Metric; DigiKey-Partnumber 445-4112-2-ND
C28: C1608X5R0J106M080AB; C_0603_1608Metric; DigiKey-Partnumber 445-4112-2-ND
D1: 150060RS75020; LED_0603_1608Metric; DigiKey-Partnumber 732-150060RS75020TR-ND
D2: 150060GS75020; LED_0603_1608Metric; DigiKey-Partnumber 732-150060GS75020TR-ND
J4: 105450-0101; MOLEX_105450-0101; DigiKey-Partnumber WM12856TR-ND
R12, R13: 5k1; R_0402_1005Metric; DigiKey-Partnumber 311-5.10KLRTR-ND
R14, R15: 27; R_0402_1005Metric; DigiKey-Partnumber P27.0LTR-ND
R16, R17: 270; R_0402_1005Metric; DigiKey-Partnumber 541-4842-2-ND
R18, R19, R20, R21, R22: 10k; R_0402_1005Metric; DigiKey-Partnumber 311-10KJRTR-ND
R23: 12k; R_0402_1005Metric; DigiKey-Partnumber 311-12KJRTR-ND
R24, R25: 100k; R_0402_1005Metric; DigiKey-Partnumber 311-100KLRTR-ND
R57, R58, R59: 0; R_0402_1005Metric; DigiKey-Partnumber 311-0.0JRTR-ND
U9: USB2513B-AEZC; QFN36_6X6MC_MCH; DigiKey-Partnumber USB2513B-AEZC-ND
U10: FT231XQ; QFN-20-1EP_4x4mm_P0.5mm_EP2.5x2.5mm; DigiKey-Partnumber 768-1128-2-ND
X2: ECS-2520MV-240-BL-TR; Oscillator_SMD_ECS_2520MV-xxx-xx-4Pin_2.5x2.0mm; DigiKey-Partnumber 50-ECS-2520MV-240-BL-TR-ND

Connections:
+3V3: C19.1, C23.1, C24.1, C25.1, C26.1, C27.1, C29.1, R16.1, R17.1, R18.2, U9.5 (VDDA33), U9.10 (VDDA33), U9.15 (VDD33), U9.23 (VDD33), U9.29 (VDDA33), U9.36 (VDD33), U10.12 (VCC), X2.4 (VDD); also elsewhere on the board
+5V_USB: C30.1, J4.A4 (VBUS1), J4.A9 (VBUS2), J4.B4 (VBUS3), J4.B9 (VBUS4), R24.2; also elsewhere on the board
/N_RESET: U9.26 (RESET_N), U10.11 (~RESET); also elsewhere on the board
/USB_FPGA_D+: U9.2 (USBDP_DN1/PRT_DIS_P1); also elsewhere on the board
/USB_FPGA_D-: U9.1 (USBDM_DN1/PRT_DIS_M1); also elsewhere on the board
/USB_STM_D+: U9.4 (USBDP_DN2/PRT_DIS_P2); also elsewhere on the board
/USB_STM_D-: U9.3 (USBDM_DN2/PRT_DIS_M2); also elsewhere on the board
/USB_UART_CTS: U10.6 (~CTS); also elsewhere on the board
/USB_UART_RTS: U10.19 (~RTS); also elsewhere on the board
/USB_UART_RX: U10.1 (RXD); also elsewhere on the board
/USB_UART_TX: U10.17 (TXD); also elsewhere on the board
/usbHub/D1+: J4.A6 (D1+), J4.B6 (D2+), U9.31 (USBDP_UP)
/usbHub/D1-: J4.A7 (D1-), J4.B7 (D2-), U9.30 (USBDM_UP)
/usbHub/UartD+: C18.1, R15.1, U9.7 (USBDP_DN3/PRT_DIS_P3)
/usbHub/UartD-: C20.1, R14.1, U9.6 (USBDM_DN3/PRT_DIS_M3)
GND: C18.2, C19.2, C20.2, C21.2, C22.2, C23.2, C24.2, C25.2, C26.2, C27.2, C28.2, C29.2, C30.2, J4.A1 (GND1), J4.A12 (GND2), J4.B1 (GND3), J4.B12 (GND4), J4.S1 (SHIELD), J4.S2 (SHIELD), J4.S3 (SHIELD), J4.S4 (SHIELD), R12.1, R13.1, R19.1, R20.1, R21.1, R22.1, R23.1, R25.1, U9.11 (TEST), U9.37 (EPAD), U10.3 (GND), U10.13 (GND), U10.21 (GND), X2.2 (GND); also elsewhere on the board
unnamed: D1.2 (A), R16.2
unnamed: D1.1 (K), U10.14 (CBUS1)
unnamed: D2.2 (A), R17.2
unnamed: D2.1 (K), U10.7 (CBUS2)
unnamed: J4.A5 (CC1), R12.2
unnamed: J4.B5 (CC2), R13.2
unnamed: R57.2, R58.2, R59.2
unnamed: C21.1, U9.14 (CRFILT)
unnamed: R20.2, U9.25 (HS_IND/CFG_SEL1)
unnamed: R18.1, U9.13 (OCS_N1), U9.17 (OCS_N2), U9.19 (OCS_N3)
unnamed: C28.1, U9.34 (PLLFILT)
unnamed: R23.2, U9.35 (RBIAS)
unnamed: R21.2, U9.24 (SCL/SMBCLK/CFG_SEL0)
unnamed: R22.2, U9.22 (SDA/SMBDATA/NON_REM1)
unnamed: R19.2, U9.28 (SUSP_IND/LOCAL_PWR/NON_REM0)
unnamed: R24.1, R25.2, U9.27 (VBUS_DET)
unnamed: U9.33 (XTALIN/CLKIN), X2.3 (OUT)
unnamed: C22.1, U10.10 (3V3OUT), U10.20 (VCCIO)
unnamed: R14.2, U10.9 (USBDM)
unnamed: R15.2, U10.8 (USBDP)
unnamed: R59.1, U10.5 (~DCD)
unnamed: R57.1, U10.4 (~DSR)
unnamed: R58.1, U10.18 (~DTR)

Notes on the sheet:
based on perifAddOn V1.1 for GECKO5Education by Theo Kluter https://github.com/logisim-evolution/GECKO5Education/tree/main commit: b38b320 cameraAddOn for GECKO5Education by Theo Kluter https://github.com/logisim-evolution/GECKO5Education/tree/main commit: b38b320 7.1 USB to RS232 Converter of http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

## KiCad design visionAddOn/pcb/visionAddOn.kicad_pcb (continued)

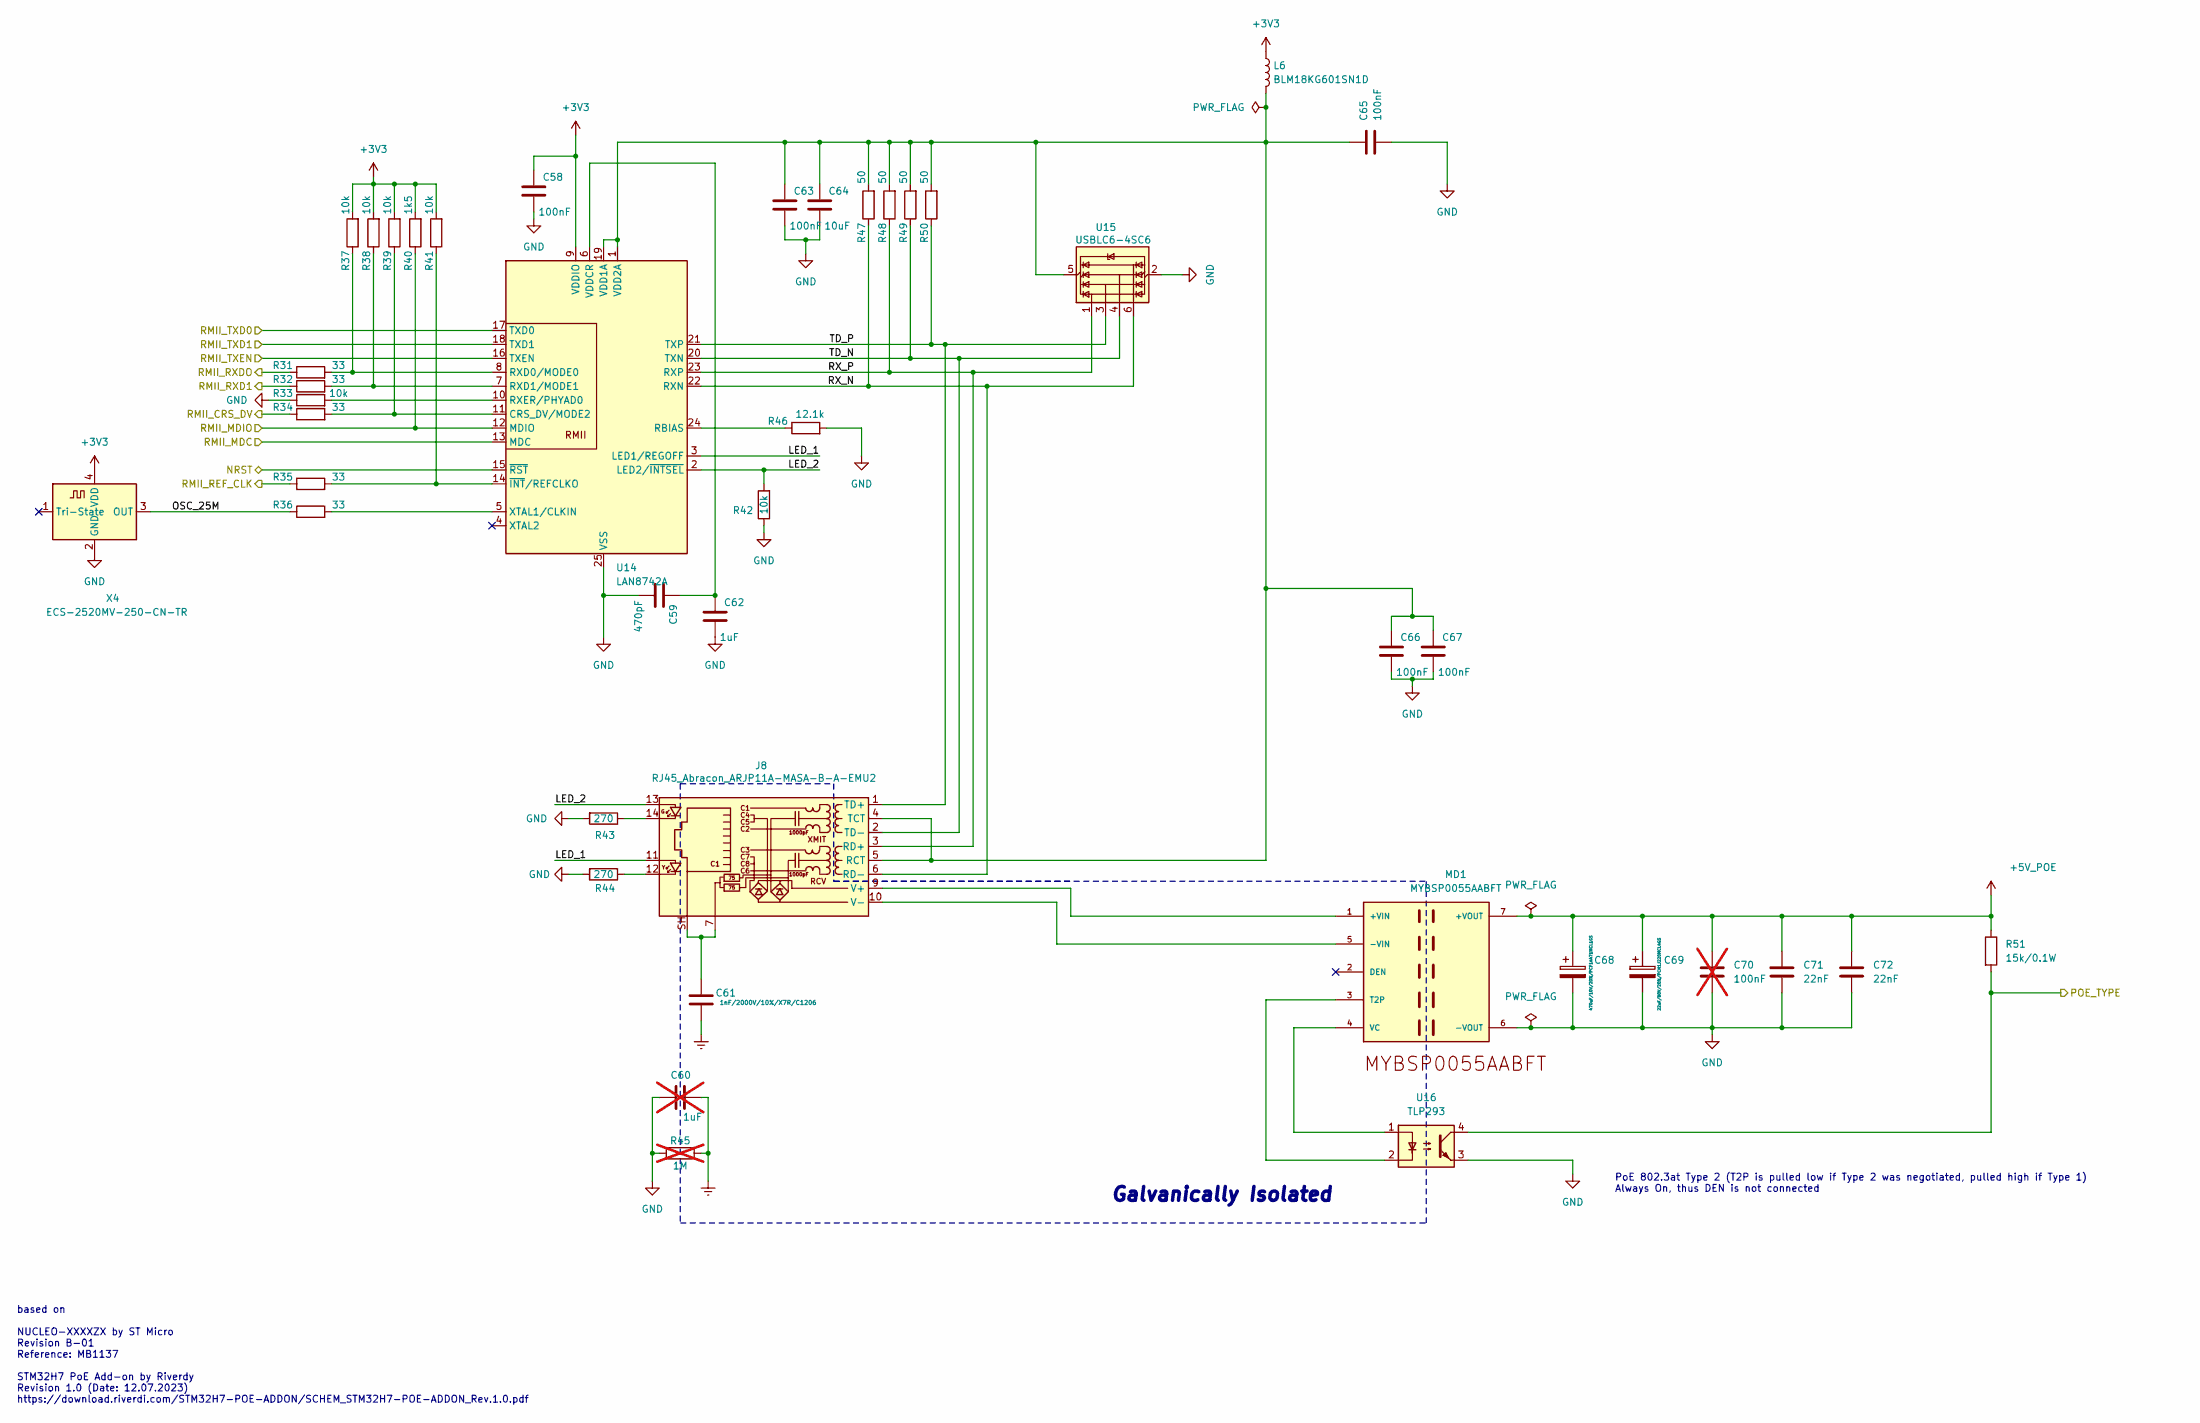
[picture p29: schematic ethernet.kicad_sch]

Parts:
C58, C63, C65, C66, C67: 100nF; C_0402_1005Metric; DigiKey-Partnumber 490-6328-2-ND
C59: 470pF; C_0402_1005Metric; DigiKey-Partnumber 490-1300-2-ND
C60: 1uF; C_0402_1005Metric; DigiKey-Partnumber 490-10024-2-ND; not fitted
C61: 1nF/2000V/10%/X7R/C1206; C_1206_3216Metric; DigiKey-Partnumber 709-VPDD202W102K1GV001ETR-ND
C62: 1uF; C_0402_1005Metric; DigiKey-Partnumber 490-10024-2-ND
C64: 10uF; C_0402_1005Metric; DigiKey-Partnumber 490-GRM155R61A106ME11DTR-ND
C68: 470uF/10V/20%/PCF1A471MCL1GS; CP_Elec_10x10; DigiKey-Partnumber 493-2996-2-ND
C69: 22uF/80V/20%/PCH1J220MCL4GS; CP_Elec_6.3x7.7; DigiKey-Partnumber PCH1J220MCL4GTR-ND
C70: 100nF; C_0603_1608Metric; DigiKey-Partnumber 311-1088-2-ND; not fitted
C71, C72: 22nF; C_0603_1608Metric; DigiKey-Partnumber 490-17777-2-ND
J8: RJ45_Abracon_ARJP11A-MASA-B-A-EMU2; RJ45_Abracon_ARJP11A-MA_Horizontal; DigiKey-Partnumber ARJP11A-MASA-B-A-EMU2-ND
L6: BLM18KG601SN1D; L_0603_1608Metric; DigiKey-Partnumber 490-5258-2-ND
MD1: MYBSP0055AABFT; MYBSP0055AABFT_0; DigiKey-Partnumber 811-MYBSP0055AABFTTR-ND
R31, R32, R34, R35, R36: 33; R_0402_1005Metric; DigiKey-Partnumber 311-33.0LRTR-ND
R33, R37, R38, R39, R41, R42: 10k; R_0402_1005Metric; DigiKey-Partnumber 311-10KJRTR-ND
R40: 1k5; R_0402_1005Metric; DigiKey-Partnumber 311-1.5KJRTR-ND
R43, R44: 270; R_0402_1005Metric; DigiKey-Partnumber 541-4842-2-ND
R45: 1M; R_0402_1005Metric; DigiKey-Partnumber 311-1.00MLRTR-ND; not fitted
R46: 12.1k; R_0402_1005Metric; DigiKey-Partnumber 311-12.1KLRTR-ND
R47, R48, R49, R50: 50; R_0402_1005Metric; DigiKey-Partnumber 13-RT0402BRE0750RLTR-ND
R51: 15k/0.1W; R_0402_1005Metric; DigiKey-Partnumber P15.0KLTR-ND
U14: LAN8742A; VQFN-24-1EP_4x4mm_P0.5mm_EP2.5x2.5mm_ThermalVias; DigiKey-Partnumber LAN8742A-CZ-TR-ND
U15: USBLC6-4SC6; SOT-23-6; DigiKey-Partnumber 497-4492-2-ND
U16: TLP293; SOIC-4_4.55x2.6mm_P1.27mm; DigiKey-Partnumber TLP293(GB-TPLETR-ND
X4: ECS-2520MV-250-CN-TR; Oscillator_SMD_ECS_2520MV-xxx-xx-4Pin_2.5x2.0mm; DigiKey-Partnumber XC2752TR-ND

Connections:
+3V3: C58.2, L6.1, R37.2, R38.2, R39.2, R40.2, R41.2, U14.9 (VDDIO), X4.4 (VDD); also elsewhere on the board
+5V_POE: C68.1, C69.1, C70.1, C71.1, C72.1, MD1.7 (+VOUT), R51.1; also elsewhere on the board
/N_RESET: U14.15 (~RST); also elsewhere on the board
/ethernet/LED_1: J8.11, U14.3 (LED1/REGOFF)
/ethernet/LED_2: J8.13, R42.2, U14.2 (LED2/~INTSEL)
/ethernet/OSC_25M: R36.1, X4.3 (OUT)
/ethernet/POE_TYPE: R51.2, U16.4; also elsewhere on the board
/ethernet/RMII_CRS_DV: R34.1; also elsewhere on the board
/ethernet/RMII_MDC: U14.13 (MDC); also elsewhere on the board
/ethernet/RMII_MDIO: R40.1, U14.12 (MDIO); also elsewhere on the board
/ethernet/RMII_REF_CLK: R35.1; also elsewhere on the board
/ethernet/RMII_RXD1: R32.1; also elsewhere on the board
/ethernet/RMII_RXDO: R31.1; also elsewhere on the board
/ethernet/RMII_TXD0: U14.17 (TXD0); also elsewhere on the board
/ethernet/RMII_TXD1: U14.18 (TXD1); also elsewhere on the board
/ethernet/RMII_TXEN: U14.16 (TXEN); also elsewhere on the board
/ethernet/RX_N: J8.6 (RD-), R47.1, U14.22 (RXN), U15.6 (I/O4)
/ethernet/RX_P: J8.3 (RD+), R48.1, U14.23 (RXP), U15.1 (I/O1)
/ethernet/TD_N: J8.2 (TD-), R49.1, U14.20 (TXN), U15.4 (I/O3)
/ethernet/TD_P: J8.1 (TD+), R50.1, U14.21 (TXP), U15.3 (I/O2)
Earth: C60.1, C61.1, R45.1
GND: C58.1, C59.1, C60.2, C62.1, C63.1, C64.1, C65.2, C66.1, C67.1, C68.2, C69.2, C70.2, C71.2, C72.2, MD1.6 (-VOUT), R33.1, R42.1, R43.2, R44.2, R45.2, R46.2, U14.25 (VSS), U15.2 (GND), U16.3, X4.2 (GND); also elsewhere on the board
unnamed: C61.2, J8.7, J8.SH
unnamed: J8.12, R44.1
unnamed: J8.14, R43.1
unnamed: C63.2, C64.2, C65.1, C66.2, C67.2, J8.4 (TCT), J8.5 (RCT), L6.2, R47.2, R48.2, R49.2, R50.2, U14.1 (VDD2A), U14.19 (VDD1A), U15.5 (VBUS)
unnamed: J8.9 (V+), MD1.1 (+VIN)
unnamed: J8.10 (V-), MD1.5 (-VIN)
unnamed: MD1.3 (T2P), U16.2
unnamed: MD1.4 (VC), U16.1
unnamed: R34.2, R39.1, U14.11 (CRS_DV/MODE2)
unnamed: R46.1, U14.24 (RBIAS)
unnamed: R31.2, R37.1, U14.8 (RXD0/MODE0)
unnamed: R32.2, R38.1, U14.7 (RXD1/MODE1)
unnamed: R33.2, U14.10 (RXER/PHYAD0)
unnamed: C59.2, C62.2, U14.6 (VDDCR)
unnamed: R36.2, U14.5 (XTAL1/CLKIN)
unnamed: R35.2, R41.1, U14.14 (~INT/REFCLKO)

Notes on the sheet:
PoE 802.3at Type 2 (T2P is pulled low if Type 2 was negotiated, pulled high if Type 1) Always On, thus DEN is not connected
Galvanically Isolated
based on NUCLEO-XXXXZX by ST Micro Revision B-01 Reference: MB1137 STM32H7 PoE Add-on by Riverdy Revision 1.0 (Date: 12.07.2023) https://download.riverdi.com/STM32H7-POE-ADDON/SCHEM_STM32H7-POE-ADDON_Rev.1.0.pdf

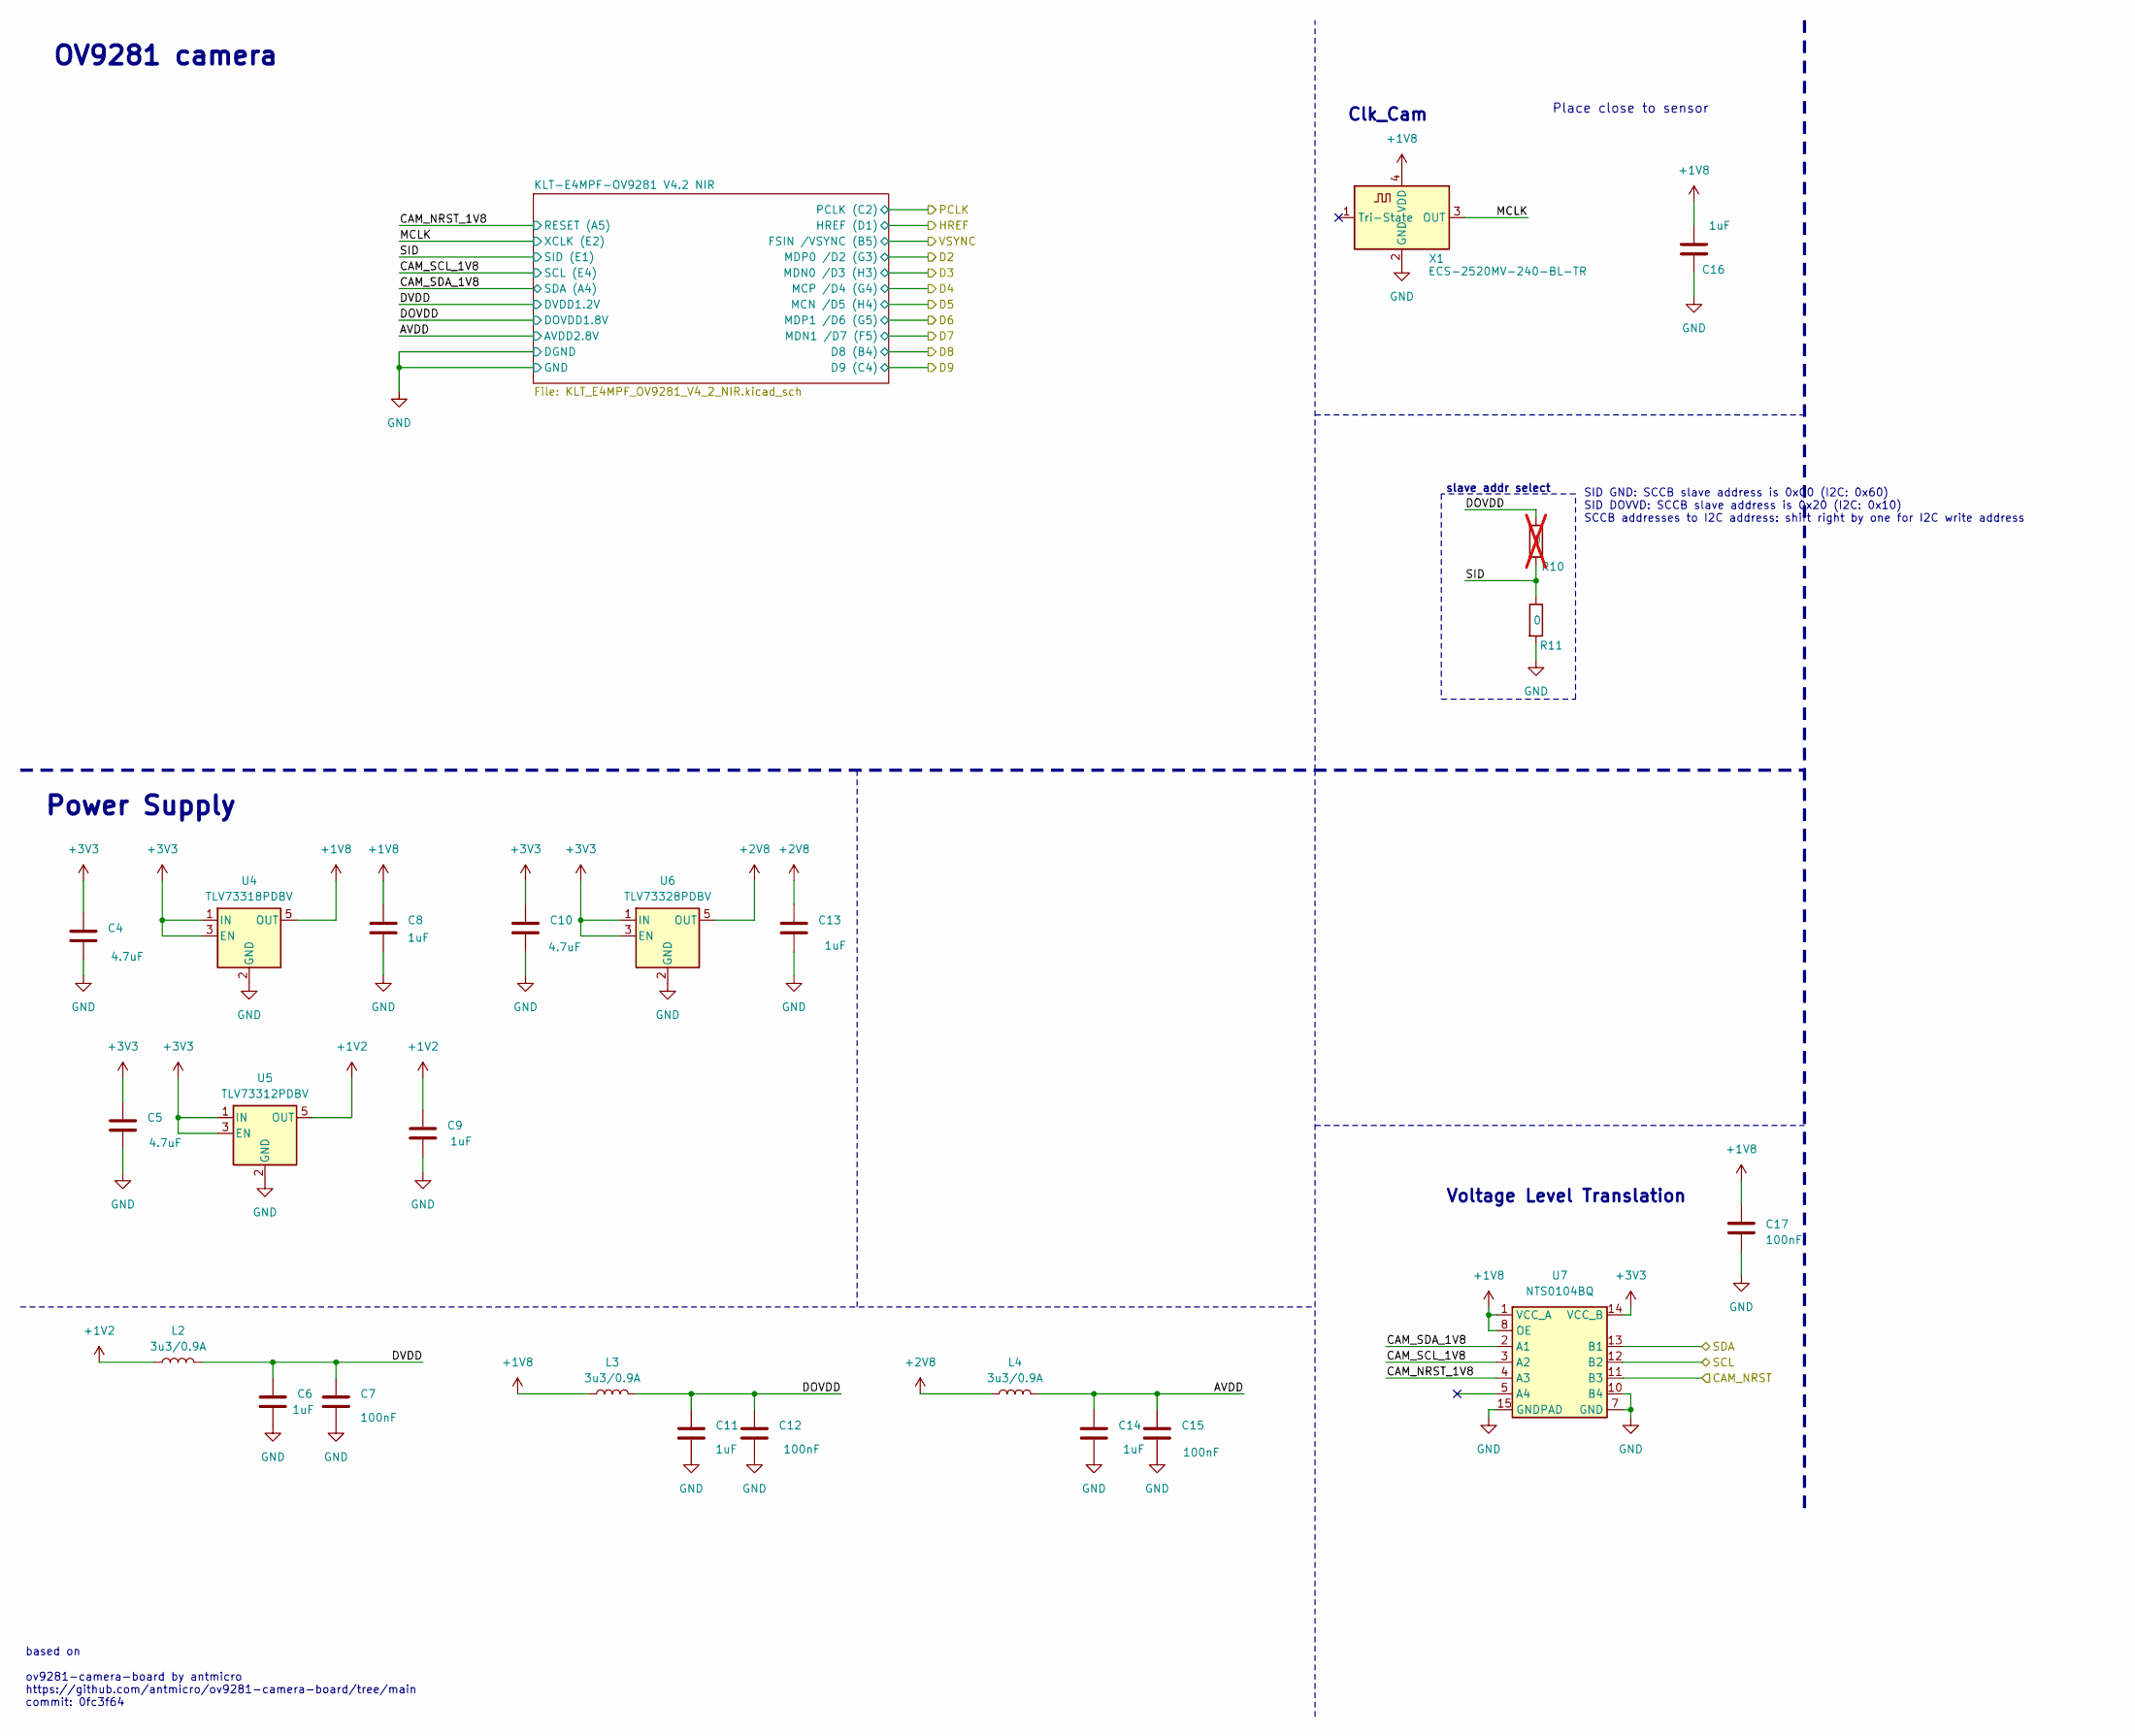
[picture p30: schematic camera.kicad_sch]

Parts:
C4, C5, C10: 4.7uF; C_0805_2012Metric; DigiKey-Partnumber 1292-0805X475K250CTTR-ND
C6, C8, C9, C11, C13, C14, C16: 1uF; C_0603_1608Metric; DigiKey-Partnumber 445-4112-2-ND
C7, C12, C15, C17: 100nF; C_0402_1005Metric; DigiKey-Partnumber 490-6328-2-ND
L2, L3, L4: MLP2012S3R3MT; L_0805_2012Metric; DigiKey-Partnumber 445-6365-2-ND
R10: 0; R_0402_1005Metric; DigiKey-Partnumber 311-0.0JRTR-ND; not fitted
R11: 0; R_0402_1005Metric; DigiKey-Partnumber 311-0.0JRTR-ND
U4: TLV73318PDBV; SOT-23-5; DigiKey-Partnumber 296-40669-2-ND
U5: TLV73312PDBV; SOT-23-5; DigiKey-Partnumber 296-40665-2-ND
U6: TLV73328PDBV; SOT-23-5; DigiKey-Partnumber 296-42282-2-ND
U7: NTS0104BQ; DHVQFN-14-1EP_2.5x3mm_P0.5mm_EP1x1.5mm; DigiKey-Partnumber 568-12382-2-ND
X1: ECS-2520MV-240-BL-TR; Oscillator_SMD_ECS_2520MV-xxx-xx-4Pin_2.5x2.0mm; DigiKey-Partnumber 50-ECS-2520MV-240-BL-TR-ND

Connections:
+1V2: C9.1, L2.1, U5.5 (OUT)
+1V8: C8.1, C16.1, C17.1, L3.1, U4.5 (OUT), U7.1 (VCC_A), U7.8 (OE), X1.4 (VDD)
+2V8: C13.1, L4.1, U6.5 (OUT)
+3V3: C4.1, C5.1, C10.1, U4.1 (IN), U4.3 (EN), U5.1 (IN), U5.3 (EN), U6.1 (IN), U6.3 (EN), U7.14 (VCC_B); also elsewhere on the board
/N_RESET: U7.11 (B3); also elsewhere on the board
/SCL_CAM: U7.12 (B2); also elsewhere on the board
/SDA_CAM: U7.13 (B1); also elsewhere on the board
/camera/AVDD: C14.1, C15.1, L4.2; also elsewhere on the board
/camera/CAM_NRST_1V8: U7.4 (A3); also elsewhere on the board
/camera/CAM_SCL_1V8: U7.3 (A2); also elsewhere on the board
/camera/CAM_SDA_1V8: U7.2 (A1); also elsewhere on the board
/camera/DOVDD: C11.1, C12.1, L3.2, R10.1; also elsewhere on the board
/camera/DVDD: C6.1, C7.1, L2.2; also elsewhere on the board
/camera/MCLK: X1.3 (OUT); also elsewhere on the board
/camera/SID: R10.2, R11.1; also elsewhere on the board
GND: C4.2, C5.2, C6.2, C7.2, C8.2, C9.2, C10.2, C11.2, C12.2, C13.2, C14.2, C15.2, C16.2, C17.2, R11.2, U4.2 (GND), U5.2 (GND), U6.2 (GND), U7.7 (GND), U7.10 (B4), U7.15 (GNDPAD), X1.2 (GND); also elsewhere on the board

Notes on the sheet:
Voltage Level Translation
SID GND: SCCB slave address is 0xC0 (I2C: 0x60) SID DOVVD: SCCB slave address is 0x20 (I2C: 0x10) SCCB addresses to I2C address: shift right by one for I2C write address
Power Supply
slave addr select
Clk_Cam
OV9281 camera
Place close to sensor
based on ov9281-camera-board by antmicro https://github.com/antmicro/ov9281-camera-board/tree/main commit: 0fc3f64

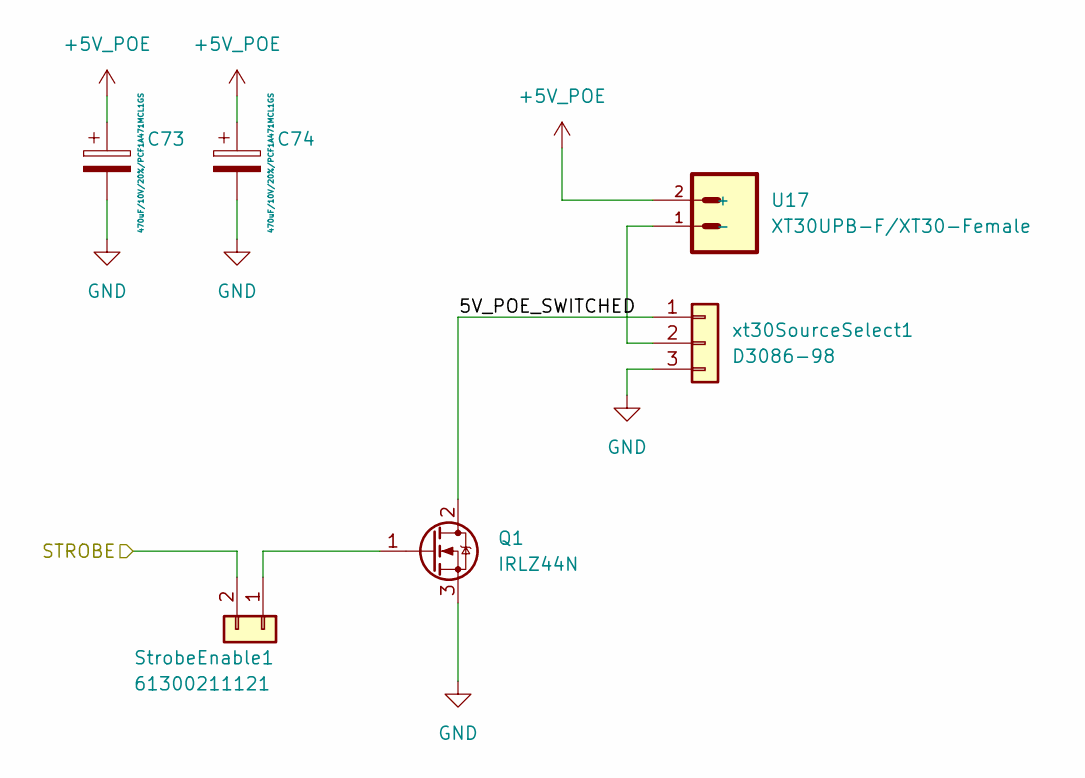
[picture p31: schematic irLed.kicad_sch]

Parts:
C73, C74: 470uF/10V/20%/PCF1A471MCL1GS; CP_Elec_10x10; DigiKey-Partnumber 493-2996-2-ND
Q1: IRLZ44N; TO-220-3_Vertical; DigiKey-Partnumber IRLZ44NPBF-ND
StrobeEnable1: 61300211121; PinHeader_1x02_P2.54mm_Vertical; DigiKey-Partnumber 732-5315-ND
U17: XT30UPB-F/XT30-Female; AMASS_XT30UPB-F_1x02_P5.0mm_Vertical; DigiKey-Partnumber 1738-1436-ND
xt30SourceSelect1: D3086-98; HARWIN_D3086-98; DigiKey-Partnumber 952-1864-ND

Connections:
+5V_POE: C73.1, C74.1, U17.2 (+); also elsewhere on the board
/STROBE: StrobeEnable1.2; also elsewhere on the board
/irLed/5V_POE_SWITCHED: Q1.2 (D), xt30SourceSelect1.1
GND: C73.2, C74.2, Q1.3 (S), xt30SourceSelect1.3; also elsewhere on the board
unnamed: Q1.1 (G), StrobeEnable1.1
unnamed: U17.1 (-), xt30SourceSelect1.2

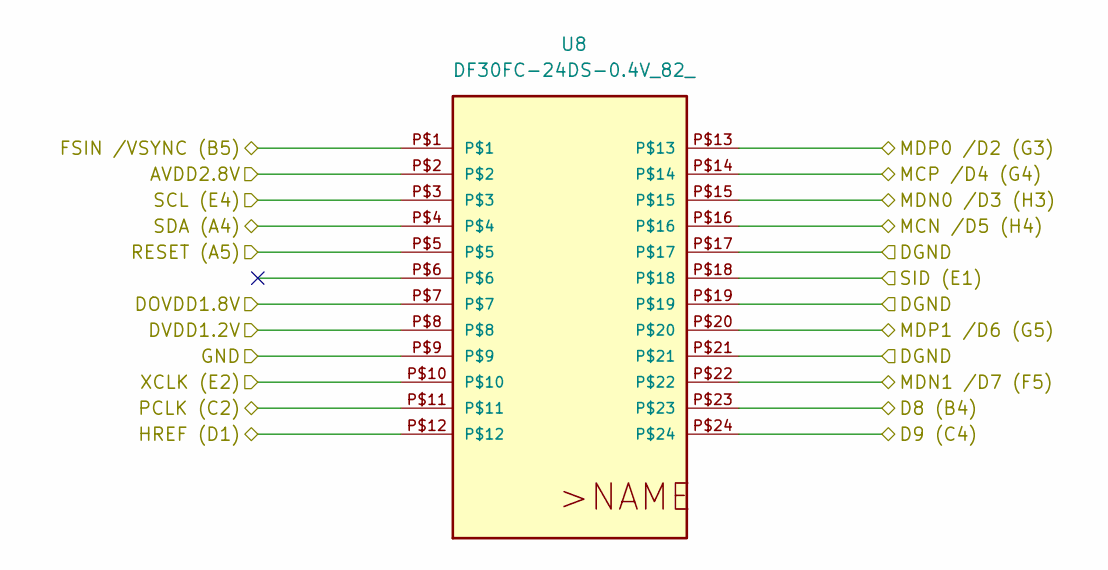
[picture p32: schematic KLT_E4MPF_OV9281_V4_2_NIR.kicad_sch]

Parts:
U8: DF30FC-24DS-0.4V_82_; DF30FC-24DS_KLT_PIN_MAPPING; DigiKey-Partnumber H3860TR-ND

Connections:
/D2_CAMERA: U8.P$13; also elsewhere on the board
/D3_CAMERA: U8.P$15; also elsewhere on the board
/D4_CAMERA: U8.P$14; also elsewhere on the board
/D5_CAMERA: U8.P$16; also elsewhere on the board
/D6_CAMERA: U8.P$20; also elsewhere on the board
/D7_CAMERA: U8.P$22; also elsewhere on the board
/D8_CAMERA: U8.P$23; also elsewhere on the board
/D9_CAMERA: U8.P$24; also elsewhere on the board
/HREF_CAMERA: U8.P$12; also elsewhere on the board
/PCLK_CAMERA: U8.P$11; also elsewhere on the board
/VSYNC_CAMERA: U8.P$1; also elsewhere on the board
/camera/AVDD: U8.P$2; also elsewhere on the board
/camera/CAM_NRST_1V8: U8.P$5; also elsewhere on the board
/camera/CAM_SCL_1V8: U8.P$3; also elsewhere on the board
/camera/CAM_SDA_1V8: U8.P$4; also elsewhere on the board
/camera/DOVDD: U8.P$7; also elsewhere on the board
/camera/DVDD: U8.P$8; also elsewhere on the board
/camera/MCLK: U8.P$10; also elsewhere on the board
/camera/SID: U8.P$18; also elsewhere on the board
GND: U8.P$9, U8.P$17, U8.P$19, U8.P$21; also elsewhere on the board

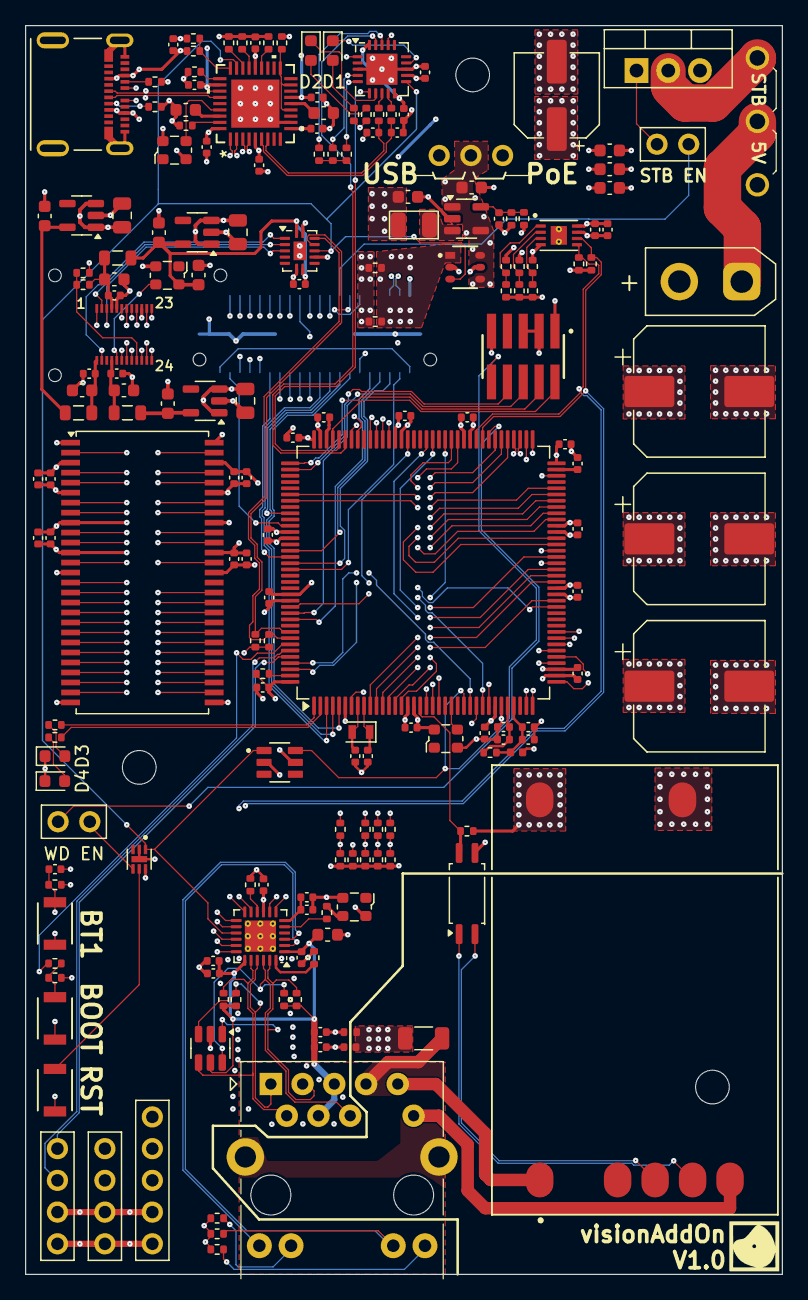
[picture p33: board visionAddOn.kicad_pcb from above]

Board: 6 copper layers, 60.6 x 100.0 mm, 188 parts (1 on the bottom side), 198 nets.

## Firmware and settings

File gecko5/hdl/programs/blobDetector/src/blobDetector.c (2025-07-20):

#include <stdio.h>
#include <string.h>
#include <swap.h>
#include <vga.h>
#include <assert.h>
#include <uart.h>
#include <platform.h>

#include "binarize.h"
#include "busErrorCounter.h"
#include "input.h"
#include "myLib.h"

uint32_t sequenceCounter = 0;
int main()
{
  platform_init();
  uart_init((volatile char *)UART1_BASE);
  vga_clear();

  uint32_t busErrorCounter = busErrorCounterGet();
  printf("bus error counter: 0x%08x\n", busErrorCounter);

  binarizeSetThreshold(128);

  uart_rx_flush((volatile char *)UART0_BASE);
  uart_rx_flush((volatile char *)UART1_BASE);

  while (true)
  {
    int res = handle_input((char *)UART0_BASE);
    if (res < 0)
    {
      printf("error parsing user input: %d\n", res);
    }
  
    res = handle_input((char *)UART1_BASE);
    if (res < 0)
    {
      printf("error parsing Vision Add-On input: %d\n", res);
    }

    busErrorCounter = busErrorCounterGet();
    if (busErrorCounter != 0)
    {
      printf("bus error counter: 0x%08x\n", busErrorCounter);
    }
  }
}

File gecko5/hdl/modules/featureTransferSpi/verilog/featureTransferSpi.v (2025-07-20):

module featureTransferSpi #(
    // default for 640x480 resolution
    parameter integer unsigned NUM_BITS_X = 10,  // must be less or equal to 16
    parameter integer unsigned NUM_BITS_Y = 9  // must be less or equal to 16
) (
    input wire reset,
    // producer
    input wire pixelClock,
    input wire featureValid,
    input wire [((NUM_BITS_X + NUM_BITS_Y) * 2) - 1:0] featureVector,
    input wire cameraVsync,  // low active!
    // consumer
    input wire systemClock,
    // here the spi master interface is defined
    output wire spiSck,
    output wire spiMosi,
    input wire spiMiso,
    output reg spiTransferDone
);

  /*
   *
   * FEATURE BUFFER
   *
   */

  localparam integer unsigned FeatureWidth = (NUM_BITS_X + NUM_BITS_Y) * 2;
  localparam integer unsigned BytesPaddedFeatureVector = $rtoi($ceil(FeatureWidth / 8.0));
  localparam integer unsigned BitsPaddedFeatureVector = BytesPaddedFeatureVector * 8;

  wire switchBuffer;

  edgeDetect vSyncEdgeDetect (
      .clk(pixelClock),
      .reset(reset),
      .s(cameraVsync),
      .neg(switchBuffer)
  );

  // support for 2^7-2 boxes. Max buffer width is 8! Otherwise number of features can't be sent in one transfer over SPI
  localparam integer unsigned DoubleBufferAddressWidth = 7; // FIXME: 8 does not seems to work

  wire writeEnable;
  wire full;
  wire oneWriteLeft;
  wire [FeatureWidth-1:0] featureVectorSystemDomain;
  reg [DoubleBufferAddressWidth:0] bufferReadAddress; // one more bit for greater than comparison
  reg [DoubleBufferAddressWidth:0] bufferReadAddressNext;
  wire newData;
  wire [DoubleBufferAddressWidth-1:0] dataLength;

  assign writeEnable = featureValid && !(full || oneWriteLeft);

  doubleBuffer #(
      .DATA_WIDTH(FeatureWidth),
      .ADDRESS_WIDTH(DoubleBufferAddressWidth)
  ) featureBuffer (
      .reset(reset),
      // producer
      .writeClock(pixelClock),
      .writeEnable(writeEnable),
      .dataIn(featureVector),
      .full(full),
      .oneWriteLeft(oneWriteLeft),
      .switchBuffer(switchBuffer),
      // consumer
      .readClock(systemClock),
      .readPointer(bufferReadAddress[DoubleBufferAddressWidth-1:0]),
      .newData(newData),
      .dataLength(dataLength),
      .dataOut(featureVectorSystemDomain)
  );

  wire [BitsPaddedFeatureVector-1:0] paddedFeatureVector;
  localparam integer unsigned BitsPadding = BitsPaddedFeatureVector - FeatureWidth;
  wire [1:0] Padding = 'b0;
  assign paddedFeatureVector = {Padding, featureVectorSystemDomain};



  wire nReset =  ~reset;
  wire spiTxReady;
  reg spiTxDataValid;
  reg [7:0] spiTxData;
  wire spiRxDataValid;
  wire [7:0] spiRxData;
  SPI_Master #(
    .SPI_MODE(3), // CPOL = 1, CPHA = 1
    .CLKS_PER_HALF_BIT(2) // o_SPI_Clk = i_Clk / (2 * CLKS_PER_HALF_BIT)
  )
    spiMasterFeatureTransfer
  (
    // Control/Data Signals,
    .i_Rst_L(nReset),
    .i_Clk(systemClock),
    // TX (MOSI) Signals
    .i_TX_Byte(spiTxData), // Byte to transmit on MOSI
    .i_TX_DV(spiTxDataValid), // Data Valid Pulse with i_TX_Byte
    .o_TX_Ready(spiTxReady), // Transmit Ready for Byte
    // RX (MISO) Signals
    .o_RX_DV(spiRxDataValid), // Data Valid pulse (1 clock cycle)
    .o_RX_Byte(spiRxData), // Byte received on MISO
    // SPI Interface
    .o_SPI_Clk(spiSck),
    .i_SPI_MISO(spiMiso),
    .o_SPI_MOSI(spiMosi)
  );

  wire switchBufferSysDom;
  // crossing from pixel clock to system clock domain
  synchroFlop updateElementsInBufferCrossing (
      .clockIn(pixelClock),
      .clockOut(systemClock),
      .reset(reset),
      .D(switchBuffer),
      .Q(switchBufferSysDom)
  );

  reg [7:0] frameCount;
  always @(posedge systemClock, posedge reset) begin
    if (reset) begin
      frameCount <= 'd0;
    end else if(switchBufferSysDom == 'd1) begin
      frameCount <= frameCount + 'd1;
    end
  end

  /*
   *
   * SPI TRANSFER FSM
   *
   */
  localparam integer unsigned StateIdle = 0;
  localparam integer unsigned StateSendFrameCountWaitReady = 1;
  localparam integer unsigned StateSendFrameCountPulseValid = 2;
  localparam integer unsigned StateSendLengthWaitReady = 3;
  localparam integer unsigned StateSendLengthPulseValid = 4;
  localparam integer unsigned StateSendByteWaitReady = 5;
  localparam integer unsigned StateSendBytePulseValid = 6;
  localparam integer unsigned StateCheckBytesRemaining = 7;
  localparam integer unsigned StateIncrementAddress = 8;
  localparam integer unsigned StateCheckFeaturesRemaining = 9;
  localparam integer unsigned StateTransferDone = 10;
  localparam integer unsigned StateError = 11;
  localparam integer unsigned NumberOfStates = 12;

  reg [$clog2(NumberOfStates)-1:0] fsmState;
  reg [$clog2(NumberOfStates)-1:0] fsmStateNext;

  localparam integer unsigned BitsTxCount = $clog2(BytesPaddedFeatureVector);
  reg [BitsTxCount:0] txByteCount;
  reg [BitsTxCount:0] txByteCountNext;

  // FSN state and txCount register
  always @(posedge systemClock, posedge reset) begin
    if (reset) begin
      fsmState <= StateIdle;
      txByteCount <= 'd0;
      bufferReadAddress <= 'd0;
    end else begin
      fsmState <= fsmStateNext;
      txByteCount <= txByteCountNext;
      bufferReadAddress <= bufferReadAddressNext;
    end
  end
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

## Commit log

2025-07-20 add sources
    [105450-0101--3DModel-STEP-56544.STEP, AP2281-3WG-7.STEP, ARJP11A-MASA-B-A-EMU2--3DModel-STEP-1.STEP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]
2025-07-20 add README.md, doc and STL files
    [Ball Joint Nut.stl, Ball Joint Socket Extension.stl, Ball Joint Socket.stl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]
2025-07-20 lower resolution and frame rate of demo GIF

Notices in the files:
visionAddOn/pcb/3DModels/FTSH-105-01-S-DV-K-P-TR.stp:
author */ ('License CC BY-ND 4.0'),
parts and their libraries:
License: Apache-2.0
